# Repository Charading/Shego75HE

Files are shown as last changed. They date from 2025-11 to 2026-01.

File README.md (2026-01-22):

<h1 style="margin-bottom:0;">Shego75HE</h1>
<h4 style="margin-top:0;">Probably the first magnetic keyboard running QMK firmware.</h4>

> 📖 **[Read the latest update →](UPDATE.md)**

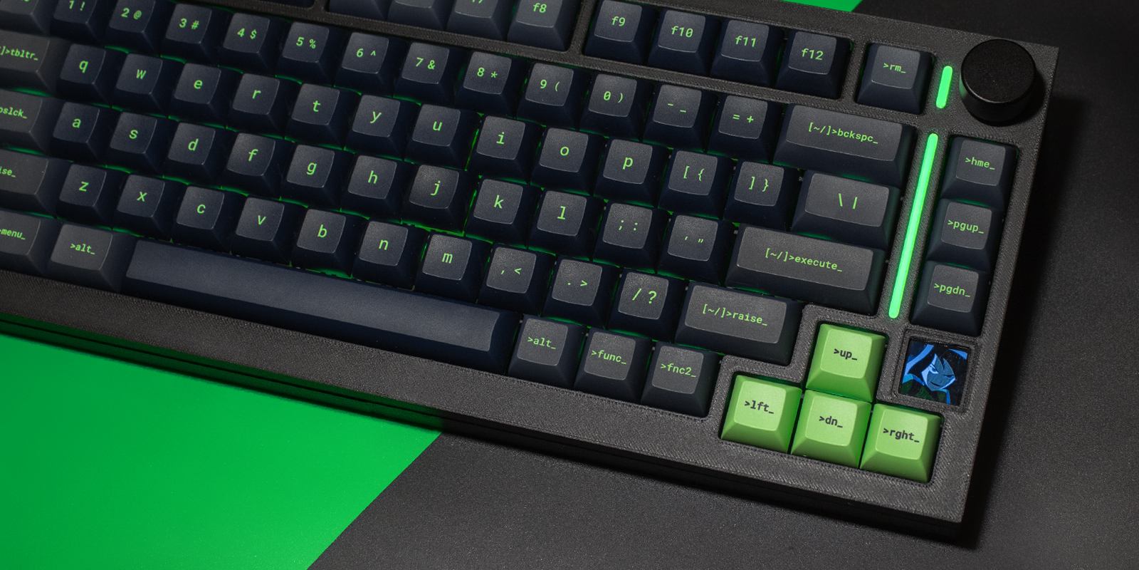
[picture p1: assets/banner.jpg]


### Introduction&nbsp; 

I couldn't find a keyboard with the all of features that I wanted at all, so I resorted to building my own one. After testing a lot of keyboards, I wanted one that had a mix of all different features from multiple keyboards. This project has taken many, many, many months, starting from experimentaion and various mini protypes like the [Shego16](https://github.com/Charading/SHEGO16-QMK-Hall-Effect-Macropad).

### Design and Inspiration 💡
I think the exploded 75% layout is one of the best layouts but sadly it's not as aftermarket as the generic 60% layout so my only options for trying to find a board were scarce. For aesthetics, I went with Shego because my mind was blank and tbh, I just wanted a cool silkscreen too lol. 

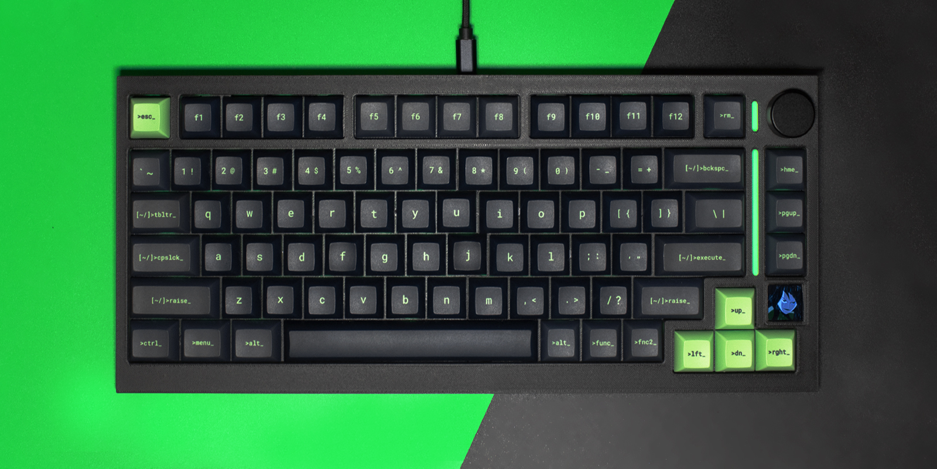
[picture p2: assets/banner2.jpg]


I do love the **Ajazz AK820 Pro** and it's clean design, along with the added screen. I do wish it could run QMK/VIA firmware though. Another board I tested was the **GamaKay TK75HEV2** I wanted my board to be quite similar to both, but have everything I've ever wanted. 

Features I wanted

* Hall Sensors
* SOCD
* Rapid Trigger
* Volume Knob
* Ambient Lighting
* Screen
* North-facing RGB
* 75% Layout
* QMK/VIA Compatible
* Works with SignalRGB (per-key not that stupid one-zone nonsense)

#### Firmware 👨‍💻
I originally tried raw C, then riskable put me on Rust, but after creating a successful prototype, I had a revelation. the idea I had is to use normal QMK firmware since I was a little bit familiar with it, then heavily modify my clone of it to work with hall sensors. 

*I am still designing a drop in [module](https://github.com/Charading/qmk-hallscan) that can make anyone be able to use the logic for QMK. Project is ongoing*

Oh yeah, to make my life easier, and save my poor fingers from typing `qmk compile -kb shego75_v1 -km default` a million times, I developed a VS Code extension, a small one-click button that compiles QMK firmware. Find it [here](https://github.com/Charading/QMK-Compile-button-for-VS-Code).

The screen/ESP32 portion is written in C++ inside Arduino IDE.

###### The Sensors 🧲
After doing extensive research and testing with breadboards and Raspberry Pi Pico boards, I settled on using the RP2040 for my base MCU. I was going to use HC4067s, but I didn't really understand multiplexer cascading so after looking for a bit, I stumbled upon the ADG732 so I now use three of these, which means I do not need to use a MCP3208 external ADC *(my god, I recently was trying to get this to work using my sensor-to-matrix logic in QMK but couldn't for the life of me)* and I could use only 3 of the 4 analog pins.

###### How it works 🔎
Essentially, the bread and butter is that the firmware scans across three ADG732 muxes - *which I got really cheap for ~£2 on AliExpress*, and this 'injects' keypresses directly into the key matrix so that it works with VIA and key remapping also. 

On startup, the sensors calibrate with a baseline threshold and when the sensors deviate by a certain % amount, the keypress is registered. I even added hysteresis so I have some kind of rapid trigger.

Debugging keycodes enable printing to QMK Toolbox's HID Console

* `DEBUG_ADC`  - Prints ADC values
* `DEBUG_KEYS` - Prints on keypress events
* `DEBUG_RAW`  - Prints the raw VIA keycode on keypresses, i.e *0x67*

I believe it still prints keys and raw to the screen on a little popup text box too.

###### The Lighting 💡
For the lighting, I ket it simple, and just use SignalRGB,  but in the future I want to maybe add OpenRGB support as well and my own custom lighting section in my Electron app. I have made the [plugin](SignalRGB/SHEGO75.js).

It has full per-key north-facing rgb, a 10-led ambient strip and a 3-led status bar, there is also a 3-pin jst 1.25mm connector footprint in the corner for optional extending *(maybe for a future case, underglow?)*.

The SRGB plugin uses `LedGroups()` to create segments so it has three draggable windows to mess around with.

```javascript
export function LedGroups() {
	return [
		{ name: "Keys",    leds: vKeys },
		{ name: "Ambient", leds: vAmbientKeys },
		{ name: "Status", leds: vStatusKeys }
	];
}
```
 It is designed as one continuous strip though, on `GP17`, but there is a transistor pair on `GP23` which is controlled by the `LED_TOG` custom keycode and cuts power to the LEDs.

 When focused on the screen/layer 3 toggled, the status bar will turn blue.

 When debugging is enabled via `DEBUG_ADC`,`DEBUG_KEYS` or `DEBUG_RAW`, the ambient strip should marque orange.

###### The Screen 📺

Sadly, I couldn't figure out how to get SPI working to talk to the screen for GIF upload and playback via HID, so I approached it a different way.

I built an isolated ESP32 system using [my fork](/esp32_display) of a GIF player repo. I basically redid it to have a little menu and file system, and work a different way to the original. Instead of it automatically copying the GIF to flash and autoplaying, I can browse the SD card, choose which GIF to display, it copies it to SPIFFS, then plays. This way it persists even after power off. 

The screen is [this](https://www.aliexpress.com/item/1005004490846551.html) ST7735/GC9107 8-pin, 0.85", 128x128 IPS display.

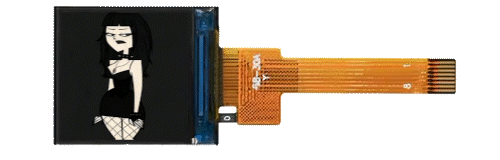
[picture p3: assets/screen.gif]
display


To get the QMK firmware to communicate with the ESP32 system, I created custom VIA keycodes which send UART text strings and text commands such as `MENU_OPEN`, `MENU_UP`,`MENU_DOWN` and `MENU_SELECT` allow me to navigate and choose an animation.

4-stage PWM controlled backlight with `TFT_BRIGHTNESS_UP` and `TFT_BRIGHTNESS_DOWN`, via a [AO3401](https://www.aosmd.com/res/data_sheets/AO3401.pdf) transistor. 

I also made a a timer page, settings page, and hardcoded focus toggle which layer 3 + encoder press turns the rotation into menu navigation, and press is the select. 

In a small update, I added a I2C connection between the RP2040 and the ESP32 which I was thinking I could use for GIF passthrough and sending in the future but this is not implemented yet.

##### Firmware Issues
I want a way to use QMK's `raw_hid_receive` and `raw_hid_send` so I can have my own custom software that can change per-key actuation, I could implement DKS, upload GIFs to the SD card/directly to the screen and even manage the card's storage. 

I managed to create a small Electron app that can communicate with the board, but it's still in development.

I realised that SignalRGB consumes packets so I had to edit the `signalrgb.c` and `signalrgb.h` to not drop packets it doesn't recognise but I am still stuck because I can't get my app to even toggle GPIO23 which toggles power to the lighting. *I did manage to do it once but I reverted back because I have up, but this was before I changed the SRGB module. Now even with SRGB disabled, I still can't get my keyboard to toggle and I don't know what the issue is.*

I just want to be able to talk to my board over HID and then I can make it similar to all those Chinese OEM clone web apps and software, Wootings web app etc.

If anyone more knowledgable can assist or point me in the right direction that would be amazing!

####  Case ⚫

case

At the moment I am using a prototype case that I printed out of ELEGOO PLA-CF. I could technically get this machined by JLCCNC but I do not wish to increase spending at this time. I would rather wait and see if I can finalise my case beforehand to minimise revisions and metallic waste. 

I do wish I could find the smaller form factor ball catches that the **Lucky65** and many other newer boards use but I can't find somewhere that can machine them or find them aftermarket. So at the moment, it is a two piece design, designed similarily to the **CIDOO C75** and **TK75HEV2** but with the shaping somewhat resembling the **Tofu65** because I like the sharp edges. I really hate the designs that have such baby rounded edges like the **AK820 Pro MAX**.

It uses a daughterboard I designed, but maybe a future design I would want to to use pogo pin connectors like the **Lucky65 V3** but I would have to do some testing to see that the magnets do not interfer with normal keyboard function.

#### PCB 🟢
pcb

Just used KiCad, I kept having issues using the standalone ESP32-PICO-D4 and flashing it *(maybe it's because I was lazy and didn't implement a USB-UART chip)* so I did some looking and found the [TinyPICO Nano](https://github.com/tinypico). To help test with firmware and stuff, just to be safe and not rely on my firmware working with it just because it worked on the ESP32-WROOM-32 dev module, I designed [this adapter](https://github.com/Charading/flexypin_adapters_hw/tree/main/TinyPICO-NANO_flexypin) so interfacing and testing would be easier. The RP2040's `GP0` and `GP1` are broken out for UART0 debug.

### Future Updates/Roadmap 🚗
- I haven't really been focused on it much with this board, but I will be looking to implent tri-mode or at least 2.4GHz wireless with a dongle. For a coming soon, future project I want to design a drop in replacement pcb for the **Lucky65 V2** or **Lucky65 V3** running my custom magnetic QMK firmware because the cases are gorgeous and such a steal!

- Software/web app (most likely Electron powered)
- Implement GIF upload over USB 
- Motion design/3D design for promotional material, a small website as I would like to start a small store that sells keyboard stuff and keycaps.
- Full aluminium case needs to be machined 
- Maybe start a Kickstarter for a future keyboard project
- TMR keyboard maybe? 👀

>*I should say I came into this project with no prior knowledge of PCB design (proficient now), very miniscule coding knowledge (still a newbie though), and a small amount of CAD skill (which I am quite proficient at now I believe). My soldering skills are now extremely high as well* :).

### Special Thanks 🖤
- [**riskable**](https://github.com/riskable) for his online resources and availabilty to help me at various points in this project!

- **@hardbr** *(discord)* for helping me understand SignalRGB implentation

- [**Phils Lab**](https://github.com/pms67) for online resources *(Youtube)*

- **JLCPCB**

- **GitHub Copilot**, **ChatGPT**, **Claude**, **Gemini Pro** (actual life savers lmao)

## 24/12/2025 - Merry Christmas! 
## Huge Update:
I’ve got the software working and a completely new firmware stack built from the ground up. The app is **Electron-based** and (honestly) was mostly vibe-coded while I iterated on UX and device behavior. The firmware is also brand new—written specifically for this project and its multi‑MCU architecture.

A big part of this update is that we **moved fully away from QMK**. Instead of adapting QMK to fit the hardware and features, we started from scratch with a firmware designed around our exact data paths and performance goals: **USB HID on the RP2040**, a clean **UART link** to the ESP32 for UI/display responsibilities, and **SPI** for high-throughput TFT updates. Dropping QMK gave us tighter control over timing, memory, and feature integration, and removed the friction of forcing a general-purpose keyboard firmware into a system that’s doing more than “just key scanning.”

The project is currently in a private repo. If you want to follow along or chat about it, my Discord is **hyupdo**.

### App Preview

<h5 align="center">Keys</h5>

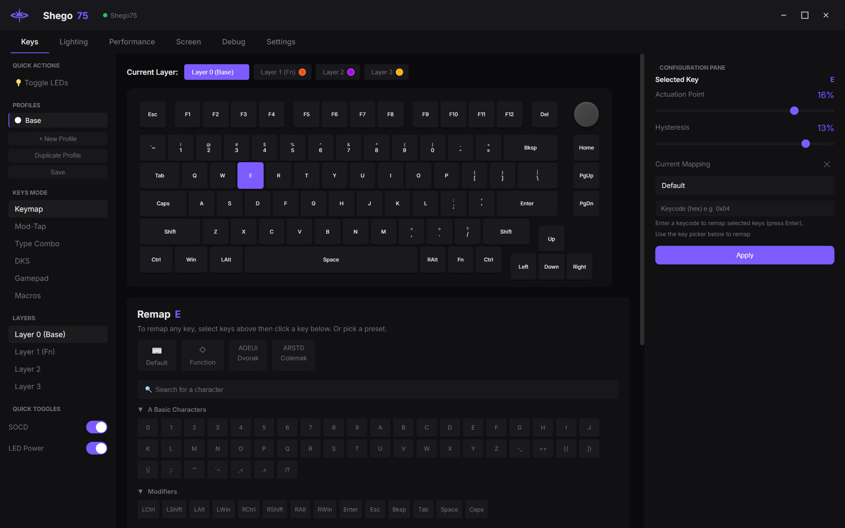
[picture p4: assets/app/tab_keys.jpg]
Keys Tab


<h5 align="center">Lighting</h5>

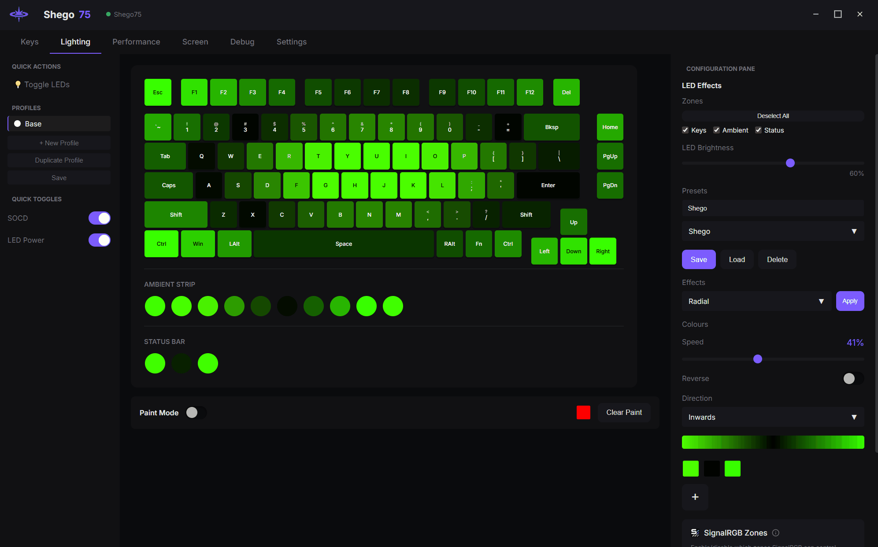
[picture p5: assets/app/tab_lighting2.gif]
Lighting Tab


<h5 align="center">Performance</h5>

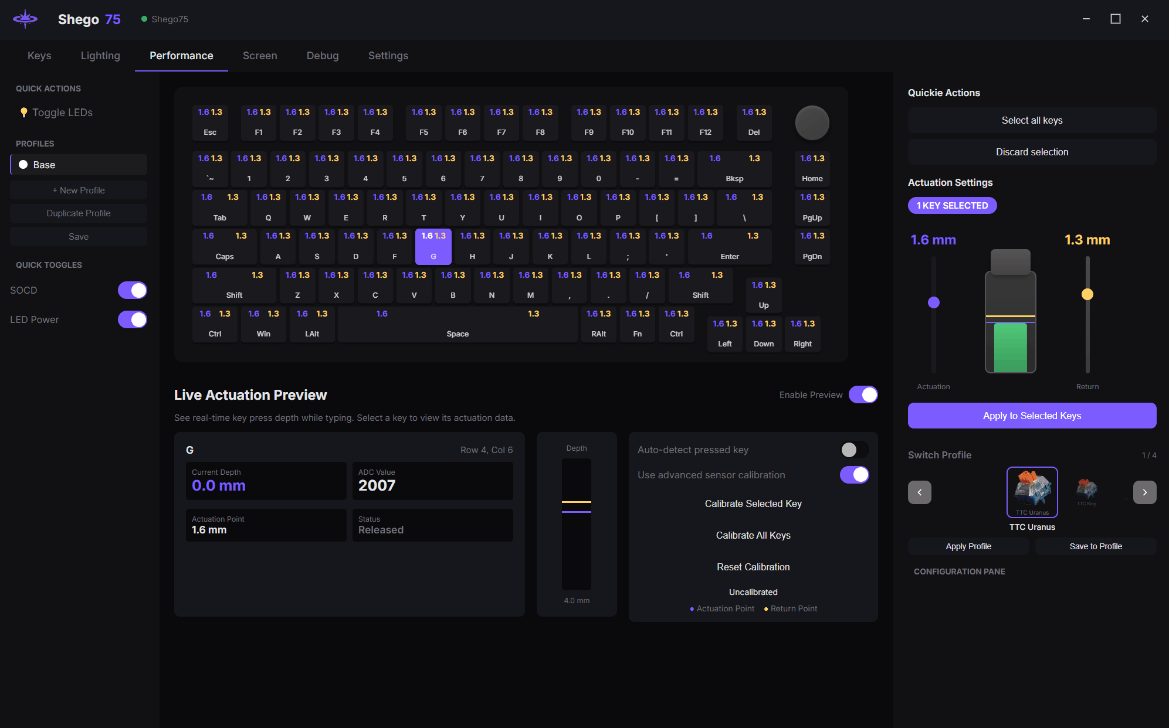
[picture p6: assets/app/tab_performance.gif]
Performance Tab


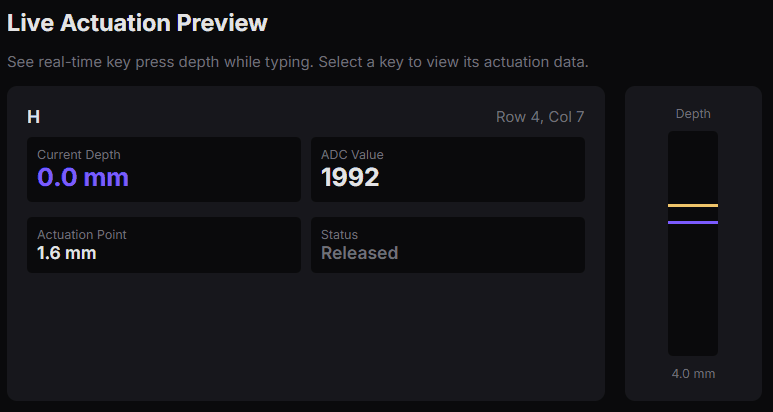
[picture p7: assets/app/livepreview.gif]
live preview


<h5 align="center" style="margin-bottom: 0;">Screen</h5>

<div align="center" style="font-style: italic; line-height: 1;">
  <small>This feature is only available on the Shego75</small>
</div>

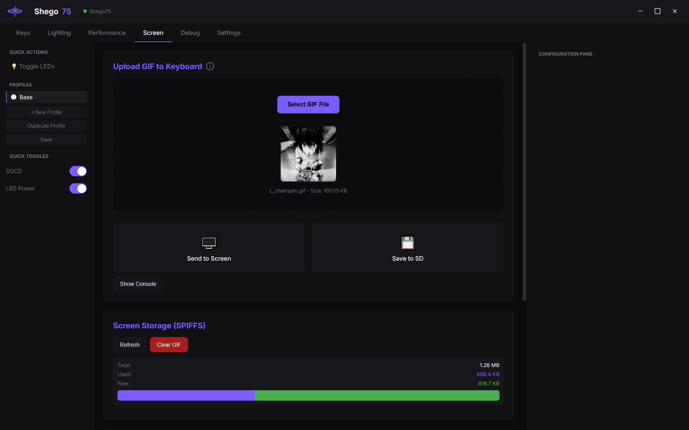
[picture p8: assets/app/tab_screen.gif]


<div align="center" style="line-height: 2;">
  <small>Storage system using the SD ('Send to SD' yet to be implemented)</small>
</div>

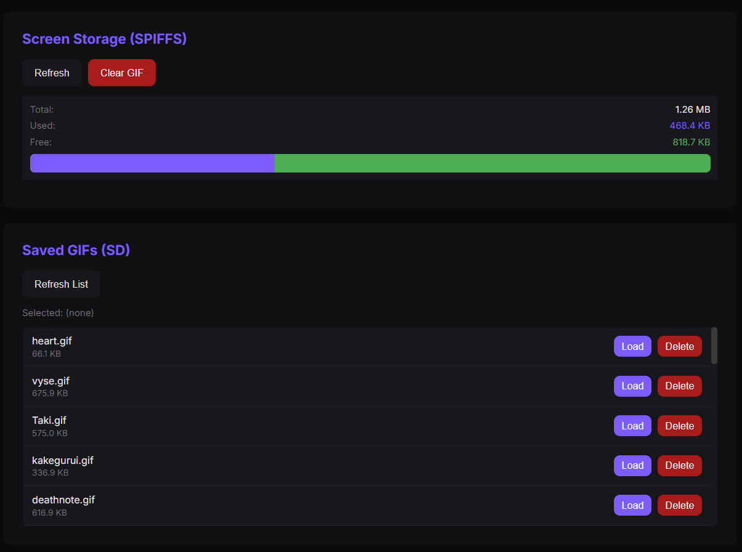
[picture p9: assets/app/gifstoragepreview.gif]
live preview


### How to use:

#### Keys

Configure per-key actuation points, dead zones, and key assignments. The live visualization shows real-time magnetic sensor readings and key states. Customize individual key behavior with adjustable sensitivity ranges and enable anti-ghosting features. Export and import key profiles for quick configuration switching.

#### Lighting

In the **Lighting** tab, effects are driven using **SignalRGB**, which treats the keyboard like an addressable LED device and streams color data in real time. Once enabled, SignalRGB can take control of animations (audio-reactive, game integrations, ambient effects) and push them directly to the board so lighting stays perfectly in sync with the rest of your setup. You can still fine-tune how the device presents itself to SignalRGB—especially how LEDs are grouped and mapped—so the software knows what “keys” or regions it’s actually driving.

To change **zones**, use the zone controls to assign LEDs/keys into separate regions (for example: left half, right half, underglow, indicator cluster, or per-row groups). Each zone can be adjusted independently so you can apply different colors/effects per region, or scale brightness and effect intensity where you want it. After updating zone assignments, apply/save the configuration so the device reports the new layout and SignalRGB (or the app’s built-in effects) will target the updated zones correctly.

#### Performance

The **Performance** tab is a live “health dashboard” for the firmware and transport links, meant to answer one question quickly: *is the device keeping up in real time?* It aggregates timing, throughput, and workload counters so you can confirm that input scanning, lighting updates, and display/UI work are all completing within budget—especially when features are enabled simultaneously.

At a high level, the tab focuses on three areas:

1) **Frame / Loop Timing**
- Shows how long the main firmware loop (or “frame”) takes to run and how consistent it is over time.
- Look for **average**, **min/max**, and **spike** behavior. A stable system has tight variance; frequent spikes suggest something occasionally blocks (heavy rendering, long SPI transfers, or bursts of host traffic).
- If you see a “budget” or target interval, the goal is to keep the loop time comfortably below that target so there’s slack for bursts.

2) **Input Responsiveness**
- Tracks the cadence and workload of key scanning and event processing.
- Useful indicators include scan rate, event queue depth, and any dropped/late events.
- If responsiveness metrics degrade while other features are active, it’s a sign you should reduce background load (very high LED update rates, overly frequent display refresh, or excessive logging/telemetry).

3) **Transport + Subsystem Throughput (Host ⇄ RP2040 ⇄ ESP32 ⇄ TFT)**
- **USB/HID**: lets you see how often the host is sending commands and how quickly the device is responding. Excessive command rates can create overhead and jitter.
- **UART (RP2040 ⇄ ESP32)**: shows whether messages are flowing smoothly between MCUs. Watch for rising queue/backlog counters or retry/error counts—those often correlate with delayed UI updates.
- **SPI (ESP32 ⇄ TFT)**: large, frequent screen updates can dominate time. If you see display-related counters tied to spikes, consider lowering refresh frequency or reducing what’s being redrawn per update.

How to use it in practice:
- Start with everything “idle” and note the baseline loop time and stability.
- Enable one feature at a time (lighting effects, animations, screen updates, host polling) and watch what changes.
- If a metric provides “worst” or “spike” values, treat those as the most important—single long stalls are often more noticeable than a slightly higher average.
- Use the tab as a verification step after configuration changes: if you adjust lighting zones, increase effect complexity, or change display behavior, confirm the loop remains stable and queues don’t grow over time.

If the Performance tab includes error counters (CRC, framing, dropped packets, overflow), any value that steadily increases during normal use usually indicates a configuration or bandwidth issue worth addressing before it impacts responsiveness.

#### Screen

The screen is driven as a simple “remote display” in a two‑MCU chain: the **RP2040** acts as the USB/HID-facing coordinator, and the **ESP32** acts as the display/UI controller. The RP2040 collects system state (and any stats it owns), then sends compact status packets over **UART** to the ESP32. The ESP32 turns those packets into UI state (text, graphs, icons, warnings) and renders the result to the TFT over **SPI**.

**Communication path**
- **Host → RP2040 (USB HID):** the desktop app can request status, enable/disable telemetry, or change what the UI should show (page selection, refresh rate, debug toggles).
- **RP2040 → ESP32 (UART):** the RP2040 forwards the “what to display” information as structured messages (think: page id + key/value metrics + flags). UART is used because it’s reliable, low-latency, and keeps the display work off the RP2040’s timing-critical loop.
- **ESP32 → TFT (SPI):** the ESP32 updates the actual pixels. SPI is a high-throughput link commonly used by small TFTs, and it lets the ESP32 push either partial updates (only what changed) or full frames depending on the UI.

**How it shows “memory and stuff”**
What you see on the screen is ultimately just the ESP32 drawing primitives (text, lines, rectangles, images) based on numbers it receives. Those numbers can come from a few places:
- **ESP32-local stats:** free heap/PSRAM, task runtime, Wi‑Fi state, frame time for rendering, SPI throughput, queue depths. These are measured directly on the ESP32 and then displayed immediately.
- **RP2040 stats:** loop timing, scan workload, HID traffic counters, UART throughput/error counters. The RP2040 measures these and periodically ships them to the ESP32 so they appear in the same UI.
- **Derived/aggregated values:** rates and percentages (e.g., “updates per second”, “max spike”, “avg frame time”) computed from counters over a time window to make the data readable at a glance.

**Display model (why it can update smoothly)**
- The ESP32 keeps a small UI state model (current page, last-known metric values, thresholds, formatting).
- On each update tick, it compares new values to the previous ones and redraws only the regions that changed (e.g., a number field or a graph strip). This avoids pushing a full-screen refresh over SPI when it’s not needed.
- Graphs are typically rendered as rolling plots: the ESP32 stores a short history buffer (last N samples) and draws it as a line or bar chart, which makes “performance” data intuitive without flooding the link.

**Features the screen typically supports**
- **Pages / tabs:** status overview, lighting status, performance graphs, debug info, connectivity.
- **Live counters:** loop/frame time, HID packet rate, UART rate, dropped/overflow counts.
- **Memory readouts:** free heap/PSRAM (ESP32), and any reported RP2040 memory stats if exposed.
- **Warnings:** threshold-based indicators (e.g., queue growing, repeated UART errors, refresh budget exceeded).

In short: the RP2040 and ESP32 exchange lightweight telemetry over UART, and the ESP32 turns that telemetry into a responsive on-screen dashboard by drawing UI elements over SPI to the TFT.

### App Flow

#### The way it works:

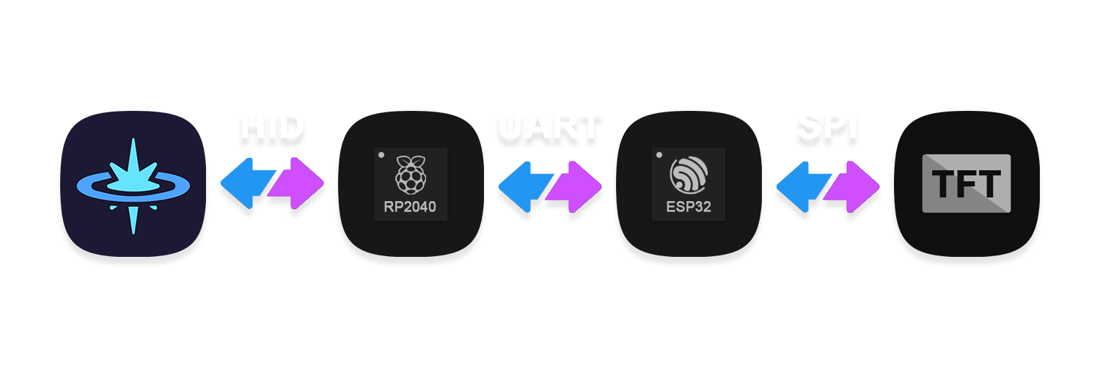
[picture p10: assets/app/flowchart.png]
order of operations


##### Software
The desktop-side software is the user interface and configuration layer. It connects to the device over **USB HID**, provides a way to change settings (layouts, lighting, display options, etc.), and then sends those changes as compact commands to the firmware. Because it uses HID, it can talk to the device without needing a custom driver on most systems, and it can also be used for debugging/telemetry (reading back status, firmware info, and error codes).

##### RP2040
The RP2040 is the **USB-facing controller** and the central coordinator. It presents itself to the computer as a **HID device**, parses incoming configuration commands from the software, and applies settings that belong on the main MCU (key scanning, state management, timing, etc.). It also acts as a bridge to the secondary MCU over **UART**, forwarding display/network-related commands and receiving status updates so the host can see what the rest of the system is doing.

##### ESP32-PICO-D4
The ESP32-PICO-D4 is responsible for the **high-level peripheral side**, primarily driving the display. It receives messages from the RP2040 over **UART**, interprets them as UI/state updates, and renders to the TFT over **SPI**. It can also be used for features that fit better on the ESP32 (background tasks, connectivity, asset handling), while keeping the RP2040 focused on deterministic USB + input timing.

### Test for yourself
I have put the app up online if you want to browse through, WebHID isn't implemented properly since I primarily focused on USB HID but do check out the themes in the Settings tab!

Link: [nova-8tt.pages.dev](https://nova-8tt.pages.dev)

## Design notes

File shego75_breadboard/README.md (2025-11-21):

# Shego75HE
75% Hall effect keyboard with many features.

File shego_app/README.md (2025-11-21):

# shego_app

Minimal Electron app with a button that sends the custom Raw HID command `0x30` (LED_TOGGLE) to the Shego75 firmware. Node cannot send Raw HID packets reliably, so every command is executed by `python scripts/toggle_led.py`, which uses hidapi under the hood. Firmware maps this command to `toggle_led()`, same effect as pressing the hardware `LED_TOG` key.

How to run

1. Install dependencies (Windows PowerShell):

```powershell
cd X:\Shego75HE\shego_app
npm install
npm start
```

2. Install Python 3 + `hidapi` (`pip install hidapi`) and ensure `python` is available in PATH. The Electron app shells out to the Python helper for every packet.

Manual CLI usage (bypasses Electron UI):

```powershell
cd X:\Shego75HE\shego_app
python scripts\toggle_led.py --vid DEAD --pid C0DE --cmd 30
```

Notes
- Sends report with command byte `0x30` (defined in firmware as `HID_REPORT_ID_LED_TOGGLE`).
- SignalRGB module now forwards unknown/non-module packets, so this command works even when SignalRGB is active.
- If you change the command ID in firmware, update `renderer.js` (`CMD_LED_TOGGLE`) and/or pass a different `--cmd` to `scripts/toggle_led.py`.

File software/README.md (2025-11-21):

# Keyboard Configurator - Electron App

A desktop application for configuring your custom keyboard, including GIF uploads via HID and per-key actuation threshold adjustment.

## Features

### 1. GIF Upload Tab
- Select GIF files from your computer
- Preview selected GIF
- Send GIF to two destinations via HID:
  - **Screen**: Display directly on ESP32 screen
  - **SD Card**: Save to SD card for later use

### 2. Actuation Settings Tab
- Interactive 75% keyboard layout
- Click any key to adjust its actuation threshold (0.1mm - 4.0mm)
- Visual feedback for modified keys
- Real-time updates sent to keyboard

## Installation

1. Install dependencies:
```bash
npm install
```

2. Install HID library (required for keyboard communication):
```bash
npm install node-hid
```

## Setup

### Find Your Keyboard's VID/PID

Run the helper script to find your keyboard:
```bash
node find-keyboard.js
```

This will list all HID devices. Find your keyboard and note the Vendor ID and Product ID.

### Configure Your Keyboard

Edit `config.js` and update with your keyboard's information:
```javascript
KEYBOARD_VID: 0x1234, // Your keyboard's Vendor ID
KEYBOARD_PID: 0x5678, // Your keyboard's Product ID
```

## Running the App

Development mode (with DevTools and auto-reload):
```bash
npm run dev
```

Production mode:
```bash
npm start
```

## HID Communication Protocol

The app sends GIF data over HID to your keyboard, which forwards it to the ESP32. The protocol includes:

- **Destination Flag**: Indicates whether to send to screen (0x01) or SD card (0x02)
- **Chunked Transfer**: Large GIFs are split into 64-byte packets
- **Commands**: Start (0x01), Data (0x02), End (0x03)

See `HID_PROTOCOL.md` for detailed protocol documentation.

## Project Structure

```
software/
├── main.js              # Electron main process with HID communication
├── preload.js           # Secure bridge between main and renderer
├── index.html           # Main UI structure
├── renderer.js          # UI logic and interactions
├── styles.css           # Styling
├── config.js            # HID configuration (VID/PID, timing)
├── find-keyboard.js     # Helper to find keyboard VID/PID
├── HID_PROTOCOL.md      # Protocol documentation
├── package.json         # Dependencies and scripts
└── README.md            # This file
```

## Customization

### Keyboard Layout
Modify the `keyLayout` array in `renderer.js` to match your keyboard's physical layout.

### Actuation Range
Adjust the slider range in `index.html`:
```html
<input type="range" id="threshold-slider" min="0.1" max="4.0" step="0.1">
```

### Communication Protocol
Implement your keyboard's specific protocol in the IPC handlers in `main.js`:
- `send-gif`: For GIF data transfer
- `update-actuation`: For actuation threshold updates

## Building for Distribution

To create distributable packages, you can add electron-builder:

```bash
npm install --save-dev electron-builder
```

Then add build scripts to `package.json`.

## License

MIT

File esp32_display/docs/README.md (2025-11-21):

# ESP32 GIF Player (ST7735)

Small ESP32 sketch to browse GIFs on an SD card, copy a selected GIF into SPIFFS as `/current.gif`, and play it on a ST7735 TFT display.

## Features
- Browse GIFs stored on SD card (up to 20 entries).
- Menu UI on the TFT (navigate with buttons for now. *QMK serial commands soon to be implemented*).
- Copy selected GIF from SD card to SPIFFS atomically (writes a temp file then renames).
- Visual progress bar while copying.
- `Clear GIF` menu option removes `/current.gif` from SPIFFS.
- Plays GIFs from SPIFFS only (prevents playing directly from SD) *I had so many issues trying to get that to work.*

## Pin assignments
These are the defaults used in `esp32_tft_sd_menu.ino`:

| Signal / Purpose | Sketch define | Default GPIO |
|---|:---|---:|
| SD Card CS (VSPI) | `SD_CS_PIN` | 5 |
| SD MOSI (VSPI) | `SD_MOSI` | 22 |
| SD MISO (VSPI) | `SD_MISO` | 19 |
| SD SCK (VSPI) | `SD_SCK` | 21 |
| Button - Up / Previous | `BUTTON_UP` | 14 |
| Button - Down / Next | `BUTTON_DOWN` | 13 |
| Button - Select | `BUTTON_SELECT` | 15 |
| TFT reset (optional) | (toggled via GPIO) | 4 |
| QMK UART RX (ESP32 receives) | `QMK_RX_PIN` | 16 |
| QMK UART TX (ESP32 sends) | `QMK_TX_PIN` | 17 |

> Note: TFT pin mappings (SPI, DC, CS, MOSI/MISO/SCLK) are configured via the `TFT_eSPI` library `User_Setup.h`. The sketch only toggles GPIO 4 as an optional display reset line if wired.

## Behavior / Usage
1. On boot the frimware initializes SD and SPIFFS and scans the SD root for `.gif` files.
2. If a valid `/current.gif` exists in SPIFFS the frimware will attempt to play it. If not, the menu is shown for gif selection.
3. In the menu:
   - Use `BUTTON_UP` and `BUTTON_DOWN` to change selection.
   - Short press `BUTTON_SELECT` to copy the chosen GIF into SPIFFS as `/current.gif` and start playback.
   - The bottom menu item is `Clear GIF`, which deletes `/current.gif` from SPIFFS.
4. Copying is atomic: the file is written to a temporary file then renamed to `/current.gif` on success. A progress bar is shown on the TFT while copying.

## QMK Serial Commands
You can control the menu remotely over the second hardware serial port (pins 16/17):*

- `MENU_OPEN`  – open menu
- `MENU_CLOSE` – close menu
- `MENU_UP`    – move selection up
- `MENU_DOWN`  – move selection down
- `MENU_SELECT`– select current item (copy / clear)
- `STATUS`     – request status string

The firmware replies with simple status messages (e.g. `MENU_OPENED`, `GIF_SELECTED:...`).

**Still yet to be implemented properly.*

## Upload / Troubleshooting
- Use the Arduino IDE or PlatformIO with the ESP32 board package installed.
- If upload fails with "Wrong boot mode detected (0x13)", put the board into download mode by holding BOOT (IO0) while plugging USB, then upload.
- Serial output (115200) prints helpful debug messages during SD/SPIFFS init, menu actions and copying.
- If copying freezes:
  - Verify SD card wiring and power.
  - Make sure the TFT and SD do not share conflicting pins in your `TFT_eSPI` configuration.
  - Check that SPIFFS has enough free space for the selected GIF.
  - Clear GIF to free up SPIFFS then try again with another smaller gif.

## Files
- `esp32_tft_sd_menu.ino` — main sketch (menu, copy logic, GIF playback callbacks).

## Notes
- The TFT driver uses `TFT_eSPI` and its pin mapping is controlled by the `User_Setup.h` / `TFT_eSPI` config. Adjust that file if your display uses different pins.
- SPI transactions and a mutex are used to serialize SD/TFT/SPIFFS accesses. Avoid changing SPI pins at runtime.

If you want any additional documentation (example wiring diagram, change log, or a shorter quickstart), tell me what to include and I will add it.

*i am still very new to coding and all this and github copilot has been a huge saviour for me, so please do forgive my spaghetti code 🍝.*

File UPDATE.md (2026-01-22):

# How This Keyboard Ended Up Here

I’ve been working on this keyboard for months now, and honestly, it’s gone through *so many* changes that it reached a point where I needed to actually stop and write down why things changed the way they did.

A lot of this came down to the screen, the firmware, and just how disconnected everything felt before.

Also, as it's grown I've wanted to rebrand/rename but am still unsure of a name so it's just Nocturne75 for now.

---

## The Old Setup (And Why It Started to Bug Me)

Originally, Shego was split across two chips.

The **RP2040** did all the keyboard stuff — scanning, Hall sensors, HID — and the **ESP32** was basically just there to run the screen. The ESP handled a GIF player that worked off an SD card, and the two chips talked to each other over UART.

On paper, this was fine.

In reality, it kind of sucked.

The screen never felt like part of the keyboard. It always felt like this extra thing bolted on the side that you talked to indirectly. And that disconnect kept getting more obvious the more features I tried to add.

---

## The SD Card Problem

The SD card setup worked, but it was fragile.

If you wanted to change a GIF:
- Open the keyboard  
- Pull the SD card  
- Copy files  
- Put it back  
- Reassemble everything  

That’s fine once. It’s annoying every time after that.

The ESP would copy the GIF from the SD card into flash so it would persist, which was clever, but it still felt like a workaround rather than a real solution.

What I *wanted* was what other keyboards with screens do:
- Send a GIF directly over USB
- Have it show up immediately
- No physical access required

I just couldn’t get there with the split RP2040 + ESP32 setup.

---

## ESP32 Pico-D4: Looked Perfect, Wasn’t

At some point I found the **ESP32 Pico-D4**, and I really thought this was it.

It’s small, cheap, has integrated flash, no external crystal — perfect for a keyboard PCB.

Except… I could not get it to work.

I couldn’t flash it reliably. I couldn’t even tell if it was alive half the time. In hindsight, a lot of that was probably soldering skill, because this was earlier on and I’ve improved a *lot* since then. But at the time, boards were just getting wasted.

That was kind of the moment where I stopped and thought:

> Why am I fighting this so hard?

---

## Rethinking the Entire Direction

Instead of trying to fix the ESP32 approach again and again, I started questioning the whole architecture.

Why am I running two processors?
Why is the screen separate at all?
Why does this feel more complicated the more I improve it?

So I started looking around for alternatives.

---

## Finding the RP2350B

That’s when I came across the **RP2350 series**, and specifically the **RP2350B**.

This thing basically solved *everything* in one go.

- Eight beautiful ADC channels  
- Enough power to handle a screen properly  
- No need for rare, expensive parts like ADG732s even though I did get them very cheap (around £2 each) from AliExpress
- One processor for everything  

The biggest thing though wasn’t specs — it was the realization that **the screen didn’t need to be separate at all**.

The keyboard *could* just be one system.

---

## Porting Everything (And Why It Was Worth It)

Over the last month or so, I’ve been porting the Shego firmware to the RP2350B and rebuilding the screen logic properly.

I designed a Pico-style RP2350B breakout for testing and ran everything on a breadboard and at the time of writing, I still am. I didn’t even touch Hall scanning at first because that part was already solid — the real work was making the screen feel native.

At that stage, the screen wasn’t unfinished — it was actually mostly there. I had already built a working UI, and I added a Spotify screen, which could show album art, track information, and playback progress. Functionally, it did what I wanted, and I could have stopped there and called it done.

What kept bothering me, though, was how cheap the UI felt, and a big part of that came down to fonts. Everything was built around basic bitmap pixel fonts, and no matter how much I tweaked spacing or layout, it always looked primitive and unrefined. 

The old system worked, but it always felt cheap and off, like something that didn’t belong on a serious keyboard, and that disconnect kept bothering me the longer I worked on the project. This was the point where I started looking into alternatives, purely because I wanted better typography and more control over how text was rendered.

That search is what led me to LVGL. Initially, I wasn’t planning on rewriting the whole UI — I just wanted to see if I could get nicer fonts and cleaner text rendering. The first thing I brought over wasn’t the main screen or the Spotify page, but the settings and lighting menu. As soon as that was running in LVGL, with the new fonts, and animations, the difference was obvious. The UI immediately felt more structured, more consistent, and more intentional. At that point, it became very hard to justify keeping the rest of the interface on the old system, and that’s when I realised the entire screen stack needed to move over.

Once I brought LVGL in, everything clicked.

The UI finally felt like it belonged to the keyboard.

---

## What the Screen Can Do Now
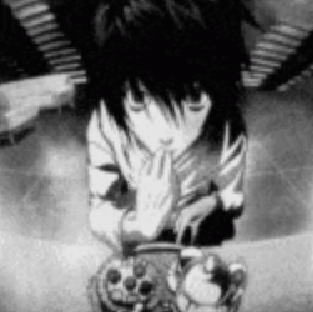
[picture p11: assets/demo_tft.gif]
Demo TFT

The screen isn’t a gimmick anymore.

It’s a proper interface.

There’s a page system:
- One page is just your main GIF
- Another page shows Spotify info — album art, track name, playtime
- Another page shows live Hall sensor data for individual keys
- Another page allows you to change the lighting

You can literally press a key and watch its actuation live. Right now it’s ADC values, but once the PCB is finalized and calibration is locked in, that’ll turn into proper distance values.

It feels *connected* in a way the old setup never did.

---

## The New GIF System (No More SD Card Pain)

This is probably one of the biggest quality-of-life improvements.

There’s now a **slot-based GIF system in flash**.

- 16 MB external flash
- Slot 0 is the active GIF
- 10 other slots for saved GIFs for instantanous switching

You upload GIFs over USB HID now. No SD card required!

If you *do* want to use the SD card, it’s still there — but now you can send gifs to it, browse it from the keyboard, copy files into flash, and manage storage without opening the case.

Changing a GIF is instant.

That alone fixes one of my biggest long-term annoyances with Shego.

---

## Input While Prototyping

Right now I’m using a little 5-button joystick module on the breadboard because it’s just faster for development.

In the real keyboard:
- Navigation will be done with keycodes and the encoder
- No extra hardware needed

The important part is that the logic is already there.

---

## Stability Testing (And Breaking It on Purpose)

I’ve spent a lot of time trying to break this.

Streaming live ADC data while LVGL is rendering.
Hammering USB while the screen updates.
Doing things I probably shouldn’t be doing.

It’s held up really well.

I did hit a weird bug where the screen was selecting the wrong key while the software side was correct — turned out to be an index offset issue, which is now fixed.

Overall, it feels solid.

---

## Flashing and Development Now

Moving to the RP2350B made development *so* much easier.

Flashing over USB or SWD.
SWD is way faster now that the firmware is bigger.
Debugging is cleaner.

At this point, once the PCB is done, it’s basically:
- Firmware updates
- Bug fixes
- Feature additions

No more architectural rework.

---

## Lucky65 v2 & v3 Side Projects

Alongside all this, I’ve also designed **drop-in replacement PCBs** for the **Lucky65 V2 and V3**.

They’re direct replacements — no case mods — and they turn those boards into **Hall Effect keyboards** running the *same* firmware as Shego, just without the screen.

Same scanning logic.
Same actuation model.
Same software quality.

The stock Lucky65 firmware ecosystem doesn't really exist. These boards basically free the hardware from that whole situation and give it a proper firmware stack. I wanted this since I do love the cases and the sounds they produce. These two boards also work wirelessly too, I designed it to work with a 2.4GHz radio module, and designed my own dongle (sadly not that tiny size, as the identical size one wouldn't work, but the firmware works) But that's another story.

---

## About the Repo

All of this has been developed in a **private repository**.

That was intentional. I wanted to be able to refactor aggressively, break things, and clean stuff up without worrying about public stability, and also am heavily thinking about making releasing this somewhat commercially. 

The codebase is now getting to the point where:
- The architecture is solid
- The direction is locked in
- It’s actually maintainable

I do think however, I will be releasing it publicly very soon, once documentation and cleanup are done.

---

## Where This Leaves Nocturne 75 (placeholder name btw)

Nocturne 75 feels like the point where everything finally came together.

One processor.
One system.
Screen, firmware, and hardware all designed together instead of fighting each other.

From here on out, it’s refinement — not reinvention.

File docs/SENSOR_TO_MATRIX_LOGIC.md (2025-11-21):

# Sensor → Matrix logic

Short reference for how sensor numbers (1–48) map to the keyboard matrix positions used in this project.

## Concept

- Sensors are numbered 1..48. Each sensor maps to a matrix row and column in a 4×12 matrix.
- Formula (integer math):

- matrix_row = (sensor - 1) / 12  // integer division
- matrix_col = (sensor - 1) % 12  // remainder

Or the inverse (given matrix row r and column c):

- sensor = r * 12 + c + 1

Notes:
- Rows and columns are zero-indexed for the matrix (rows 0..3, cols 0..11).
- These formulas are exactly what the scanner code in `mux_adc.c` uses when converting a sensor number to a matrix coordinate.

## Examples

- Sensor 1 → row = (1-1)/12 = 0, col = (1-1)%12 = 0 → matrix[0][0]
- Sensor 6 → row = (6-1)/12 = 0, col = (6-1)%12 = 5 → matrix[0][5]
- Sensor 18 → row = (18-1)/12 = 1, col = (18-1)%12 = 5 → matrix[1][5]
- Sensor 48 → row = (48-1)/12 = 3, col = (48-1)%12 = 11 → matrix[3][11]

Inverse examples:
- Row 0, Col 5 → sensor = 0*12 + 5 + 1 = 6
- Row 1, Col 5 → sensor = 1*12 + 5 + 1 = 18

## Quick code snippets

C (same idea used in the firmware):

```c
// sensor is 1..48
uint8_t matrix_row = (sensor - 1) / 12;
uint8_t matrix_col = (sensor - 1) % 12;
// then use matrix_row and matrix_col to set matrix[row][col]
```

Python (for testing / scripting):

```python
def sensor_to_matrix(sensor):
    assert 1 <= sensor <= 48
    row = (sensor - 1) // 12
    col = (sensor - 1) % 12
    return row, col

def matrix_to_sensor(row, col):
    assert 0 <= row < 4 and 0 <= col < 12
    return row * 12 + col + 1
```

## 4 × 12 sensor grid (sensor number → matrix position)

Rows are left→right (cols 0..11). Each cell shows the sensor number and (r,c).

Row 0:  1 (0,0)   2 (0,1)   3 (0,2)   4 (0,3)   5 (0,4)   6 (0,5)   7 (0,6)   8 (0,7)   9 (0,8)  10 (0,9)  11 (0,10) 12 (0,11)

Row 1: 13 (1,0)  14 (1,1)  15 (1,2)  16 (1,3)  17 (1,4)  18 (1,5)  19 (1,6)  20 (1,7)  21 (1,8) 22 (1,9)  23 (1,10) 24 (1,11)

Row 2: 25 (2,0)  26 (2,1)  27 (2,2)  28 (2,3)  29 (2,4)  30 (2,5)  31 (2,6)  32 (2,7)  33 (2,8) 34 (2,9)  35 (2,10) 36 (2,11)

Row 3: 37 (3,0)  38 (3,1)  39 (3,2)  40 (3,3)  41 (3,4)  42 (3,5)  43 (3,6)  44 (3,7)  45 (3,8) 46 (3,9)  47 (3,10) 48 (3,11)

## Practical notes

- The scanner reads a MUX channel, looks up the configured `sensor` number for that channel (from `mux_pins.c`), and applies the formula above to set the corresponding key in the QMK matrix.
- If two different MUX channels are accidentally configured with the same sensor number, pressing either physical key will activate the same matrix position (causing duplicated/ghosted keypresses).
- If a physical key does nothing, check that the MUX channel's `.sensor` value points to the correct sensor number and that the wiring to that MUX channel/4×4 board is good.

Paste this file anywhere you need; it's meant to be a compact copy/paste reference for quick debugging.

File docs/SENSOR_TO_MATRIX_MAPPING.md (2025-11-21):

# Sensor to Matrix Position Mapping

## Where is the sensor-to-matrix array?

**There is NO explicit array!** The mapping is calculated on-the-fly using a simple formula.

## The Formula (in `mux_adc.c` line ~145-146):

```c
uint8_t matrix_row = (key_mapping->sensor - 1) / MATRIX_COLS;  // MATRIX_COLS = 12
uint8_t matrix_col = (key_mapping->sensor - 1) % MATRIX_COLS;
```

## Complete Sensor-to-Matrix Reference Table:

| Sensor # | Matrix Position | Your Keymap Key | Calculation |
|---|---|---|---|
| 1 | [0][0] | ESC | (1-1)/12=0, (1-1)%12=0 |
| 2 | [0][1] | Q | (2-1)/12=0, (2-1)%12=1 |
| 3 | [0][2] | W | (3-1)/12=0, (3-1)%12=2 |
| 4 | [0][3] | E | (4-1)/12=0, (4-1)%12=3 |
| 5 | [0][4] | R | (5-1)/12=0, (5-1)%12=4 |
| 6 | [0][5] | T | (6-1)/12=0, (6-1)%12=5 |
| 7 | [0][6] | Y | (7-1)/12=0, (7-1)%12=6 |
| 8 | [0][7] | U | (8-1)/12=0, (8-1)%12=7 |
| 9 | [0][8] | I | (9-1)/12=0, (9-1)%12=8 |
| 10 | [0][9] | O | (10-1)/12=0, (10-1)%12=9 |
| 11 | [0][10] | P | (11-1)/12=0, (11-1)%12=10 |
| 12 | [0][11] | BSPC | (12-1)/12=0, (12-1)%12=11 |
| 13 | [1][0] | TAB | (13-1)/12=1, (13-1)%12=0 |
| 14 | [1][1] | A | (14-1)/12=1, (14-1)%12=1 |
| 15 | [1][2] | S | (15-1)/12=1, (15-1)%12=2 |
| 16 | [1][3] | D | (16-1)/12=1, (16-1)%12=3 |
| 17 | [1][4] | F | (17-1)/12=1, (17-1)%12=4 |
| 18 | [1][5] | G | (18-1)/12=1, (18-1)%12=5 |
| 19 | [1][6] | H | (19-1)/12=1, (19-1)%12=6 |
| 20 | [1][7] | J | (20-1)/12=1, (20-1)%12=7 |
| 21 | [1][8] | K | (21-1)/12=1, (21-1)%12=8 |
| 22 | [1][9] | L | (22-1)/12=1, (22-1)%12=9 |
| 23 | [1][10] | SCLN (;) | (23-1)/12=1, (23-1)%12=10 |
| 24 | [1][11] | ENT | (24-1)/12=1, (24-1)%12=11 |
| 25 | [2][0] | LSFT | (25-1)/12=2, (25-1)%12=0 |
| 26 | [2][1] | Z | (26-1)/12=2, (26-1)%12=1 |
| 27 | [2][2] | X | (27-1)/12=2, (27-1)%12=2 |
| 28 | [2][3] | C | (28-1)/12=2, (28-1)%12=3 |
| 29 | [2][4] | V | (29-1)/12=2, (29-1)%12=4 |
| 30 | [2][5] | B | (30-1)/12=2, (30-1)%12=5 |
| 31 | [2][6] | N | (31-1)/12=2, (31-1)%12=6 |
| 32 | [2][7] | M | (32-1)/12=2, (32-1)%12=7 |
| 33 | [2][8] | COMM (,) | (33-1)/12=2, (33-1)%12=8 |
| 34 | [2][9] | DOT (.) | (34-1)/12=2, (34-1)%12=9 |
| 35 | [2][10] | SLSH (/) | (35-1)/12=2, (35-1)%12=10 |
| 36 | [2][11] | RSFT | (36-1)/12=2, (36-1)%12=11 |
| 37 | [3][0] | LCTL | (37-1)/12=3, (37-1)%12=0 |
| 38 | [3][1] | LGUI (Win) | (38-1)/12=3, (38-1)%12=1 |
| 39 | [3][2] | LALT | (39-1)/12=3, (39-1)%12=2 |
| 40 | [3][3] | MO(1) | (40-1)/12=3, (40-1)%12=3 |
| 41 | [3][4] | SPC | (41-1)/12=3, (41-1)%12=4 |
| 42 | [3][5] | SPC | (42-1)/12=3, (42-1)%12=5 |
| 43 | [3][6] | SPC | (43-1)/12=3, (43-1)%12=6 |
| 44 | [3][7] | MO(2) | (44-1)/12=3, (44-1)%12=7 |
| 45 | [3][8] | RALT | (45-1)/12=3, (45-1)%12=8 |
| 46 | [3][9] | RGUI | (46-1)/12=3, (46-1)%12=9 |
| 47 | [3][10] | APP | (47-1)/12=3, (47-1)%12=10 |
| 48 | [3][11] | RCTL | (48-1)/12=3, (48-1)%12=11 |

## How to Use This:

1. **Test a physical key** on your MUX board
2. **Note which key it types** (e.g., it types "ENTER")
3. **Find that key in the table above** (ENT is sensor 24, matrix [1][11])
4. **Update your mux_pins.c** to map that MUX channel to sensor 24

Example:
```c
// If MUX1 CH15 physically types "ENTER", then:
[15] = { .sensor = 24, .key = "Ent" },  // CH15 wired to sensor 24
```

## Quick Lookup by Key:

- **ESC**: sensor 1
- **Q**: sensor 2
- **TAB**: sensor 13
- **A**: sensor 14
- **ENTER**: sensor 24
- **LSHIFT**: sensor 25
- **Z**: sensor 26
- **SPACE**: sensors 41, 42, 43

The sensor number completely determines what key is pressed!

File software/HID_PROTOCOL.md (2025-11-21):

# HID Protocol Documentation

## Overview
This document describes the HID communication protocol for sending GIF files from the Electron app to your keyboard, which forwards them to the ESP32.

## Packet Structure
Each HID report is 64 bytes (configurable in `config.js`):

```
Byte 0:    Report ID (typically 0x00)
Byte 1:    Command byte
Byte 2:    Destination flag
Bytes 3+:  Command-specific data
```

## Commands

### 1. Start GIF Transfer (0x01)
Initiates a GIF transfer session.

**Packet Layout:**
```
[0x00] Report ID
[0x01] Command: Start GIF
[0x01/0x02] Destination: 0x01=Screen, 0x02=SD Card
[4 bytes] Total file size (little-endian uint32)
[2 bytes] Total chunks (little-endian uint16)
[remaining] Padding
```

### 2. GIF Data Chunk (0x02)
Sends a chunk of GIF data.

**Packet Layout:**
```
[0x00] Report ID
[0x02] Command: GIF Data
[0x01/0x02] Destination flag
[2 bytes] Chunk index (little-endian uint16)
[1 byte] Chunk size (0-59 bytes)
[59 bytes] Chunk data
```

### 3. End GIF Transfer (0x03)
Signals completion of GIF transfer.

**Packet Layout:**
```
[0x00] Report ID
[0x03] Command: End GIF
[0x01/0x02] Destination flag
[remaining] Padding
```

## Destination Flags
- `0x01`: Send to Screen (ESP32 displays immediately)
- `0x02`: Save to SD Card (ESP32 stores on SD card)

## Timing
- **Start delay**: 50ms after sending start packet
- **Packet delay**: 10ms between data chunks
- These can be adjusted in `config.js`

## Keyboard Implementation

Your keyboard firmware should:

1. **Receive HID reports** via USB
2. **Parse the command byte** to determine action
3. **Forward to ESP32** via UART/SPI/I2C with the destination flag
4. **Handle acknowledgments** (optional, for reliability)

### Example Keyboard Code (Pseudocode)
```c
void handle_hid_report(uint8_t* data, uint16_t len) {
    uint8_t cmd = data[1];
    uint8_t dest = data[2];
    
    switch(cmd) {
        case 0x01: // Start GIF
            uint32_t size = *(uint32_t*)&data[3];
            uint16_t chunks = *(uint16_t*)&data[7];
            esp32_start_gif_transfer(size, chunks, dest);
            break;
            
        case 0x02: // Data chunk
            uint16_t index = *(uint16_t*)&data[3];
            uint8_t chunk_size = data[5];
            esp32_send_gif_chunk(index, &data[6], chunk_size, dest);
            break;
            
        case 0x03: // End
            esp32_end_gif_transfer(dest);
            break;
    }
}
```

## Setup Instructions

1. **Install node-hid**:
   ```bash
   npm install node-hid
   ```

2. **Find your keyboard's VID/PID**:
   ```bash
   node find-keyboard.js
   ```

3. **Update config.js** with your keyboard's VID/PID

4. **Test the connection** by running the app and sending a small GIF

## Troubleshooting

### "Keyboard not found"
- Check VID/PID in `config.js`
- Run `find-keyboard.js` to verify device is detected
- Ensure keyboard is connected and recognized by Windows

### Transfer fails or is slow
- Adjust timing in `config.js`
- Check HID report size matches your keyboard
- Verify keyboard firmware is processing packets

### ESP32 doesn't receive data
- Check UART/SPI/I2C connection between keyboard and ESP32
- Verify baud rate and protocol
- Add debug logging in keyboard firmware

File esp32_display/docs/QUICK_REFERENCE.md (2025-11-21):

# Quick Reference Guide - ESP32 GIF Player Menus

## 🎮 UART Commands Cheat Sheet

### Menu Navigation
| Command | Description |
|---|---|
| `MENU_OPEN` | Open GIF select menu |
| `SETTINGS_OPEN` | Open settings menu |
| `MENU_CLOSE` | Close menu, return to GIF |
| `MENU_UP` | Navigate up / Decrease timer |
| `MENU_DOWN` | Navigate down / Increase timer |
| `MENU_SELECT` | Select / Toggle / Start-Stop |
| `MENU_CYCLE_RIGHT` | Cycle menus → |
| `MENU_CYCLE_LEFT` | Cycle menus ← |
| `STATUS` | Get current state |

---

## 📋 Settings Menu Items

```
Settings:
  > < Back                      [SELECT = Exit]
    SOCD: ON/OFF                [SELECT = Toggle]
    Debugging                   [Header - not selectable]
      Raw Keycodes: ON/OFF      [SELECT = Toggle]
      Keypress Detect: ON/OFF   [SELECT = Toggle]
      ADC Printing: ON/OFF      [SELECT = Toggle]
```

**Navigation**: Auto-skips "Debugging" header  
**Timeout**: 5 seconds of inactivity

---

## ⏱️ Timer Menu Controls

### When Stopped:
- `MENU_UP` → Decrease minutes (min: 1)
- `MENU_DOWN` → Increase minutes (max: 99)
- `MENU_SELECT` → Start countdown
- **Visual**: Orange arrows ▲▼ visible

### When Running:
- **Any button** → Stop & Reset
- **Auto-update**: Every 100ms
- **No timeout**: Runs indefinitely

### On Expiration:
- Screen flashes 3× (white/black)
- "TIME'S UP!" message
- Returns to stopped state (00:00)

---

## 🎨 Text Offset Editing

### Quick Start:
1. Trigger popup (e.g., press key)
2. Check Serial Monitor:
   ```
   [POPUP] Title: "Keypress" | X_OFFSET: 0
   ```
3. Edit line ~110 in sketch:
   ```cpp
   {"Keypress", 15},  // +15px right
   ```
4. Upload

### Rules:
- **Positive** = shift RIGHT
- **Negative** = shift LEFT
- **0** = left edge (default)
- **Auto**: `0x____` gets +8px

---

## 🚦 Debug Popup Types

| UART Message | Popup Title | Body Color |
|---|---|---|
| `RAW_KEYCODE: 0x001C` | Keypress | Yellow |
| `[DEBUG] Key printing: ON` | Key Printing | Green |
| `[DEBUG] Key printing: OFF` | Key Printing | Red |
| `[DEBUG] Raw keycodes: ON` | Raw Keycodes | Green |
| `[DEBUG] Raw keycodes: OFF` | Raw Keycodes | Red |
| `[DEBUG] ADC printing: ON` | ADC printing | Green |
| `[DEBUG] ADC printing: OFF` | ADC printing | Red |
| `SOCD: Enabled` | SOCD status | Green |
| `SOCD: Disabled` | SOCD status | Red |

**Display**: 750ms (keycodes) or 1500ms (settings)  
**Behavior**: No GIF pause, immediate draw

---

## 🔧 Common Tasks

### Change Timer Default (5 min → X min):
Line 79: `int timerMinutes = 5;` → `int timerMinutes = X;`

### Adjust Popup Duration:
Line 76: `unsigned long debugPopupDefaultMs = 1500;`

### Move ALL Keycodes Right 10px:
Line 140-143: Change `return 8;` → `return 10;`

### Add New Setting to Menu:
1. Add bool at line ~72 (e.g., `bool setting_xyz = false;`)
2. Add to items array in `drawSettingsMenu()` (~line 1112)
3. Add handler in `handleSettingsSelection()` (~line 1150)
4. Update total count in MENU_UP/DOWN handlers

---

## 📊 Menu State Variables

```cpp
currentMenuType          // MENU_GIF, MENU_SETTINGS, MENU_TIMER
inMenu                   // true if any menu is open
menuSelection           // GIF menu cursor position
settingsSelection       // Settings menu cursor position
timerMinutes           // Timer duration (adjustable)
timerRunning           // Timer active state
setting_socd_enabled   // SOCD toggle state
// ... more settings
```

---

## 🐛 Troubleshooting

### Popup Text Not Moving:
1. Check Serial Monitor for exact string
2. Ensure entry matches exactly (case-insensitive ok)
3. Verify comma after each entry (except last)
4. Recompile and upload

### Timer Not Starting:
- Ensure you're in TIMER menu (not SETTINGS)
- Check Serial Monitor for "Timer started" message
- Try resetting with any button first

### Menu Stuck/Frozen:
- Send `MENU_CLOSE` via UART
- Menu auto-exits after 5s timeout (except timer)
- Physical buttons also work (if wired)

### Popups Flickering:
- Should be fixed now (immediate draw mode)
- If still flickering, check Serial for errors
- Ensure latest code is uploaded

---

## 💾 Backup Settings Before Editing

### Critical Lines to Backup:
- Lines 95-120: Manual offset table
- Lines 60-84: Menu state and settings
- Lines 410-800: handleQMKCommands() function

### Safe Edit Areas:
- Offset X values (can't break anything)
- Timer default minutes
- Popup duration (milliseconds)
- Color definitions (TFT_GREEN, etc.)

---

## 📞 Quick Debug Commands

```cpp
// In Serial Monitor or QMK:
STATUS                    // Check current menu state
[DEBUG] ADC printing: ON  // Test ADC popup
RAW_KEYCODE: 0x001C       // Test keycode popup
SOCD: Enabled             // Test SOCD popup
SETTINGS_OPEN             // Open settings
MENU_CLOSE                // Force close menu
```

---

## 🎯 Best Practices

1. **Test popups first**: Trigger each type and copy exact strings
2. **Small adjustments**: Move text by ±5px at a time
3. **Backup often**: Save working offset values
4. **Serial Monitor**: Always keep open during testing
5. **One change**: Edit one offset at a time, test, repeat

---

**For detailed information, see `CHANGELOG_2025-10-02.md`**

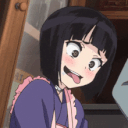
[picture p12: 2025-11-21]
assets/lick.gif

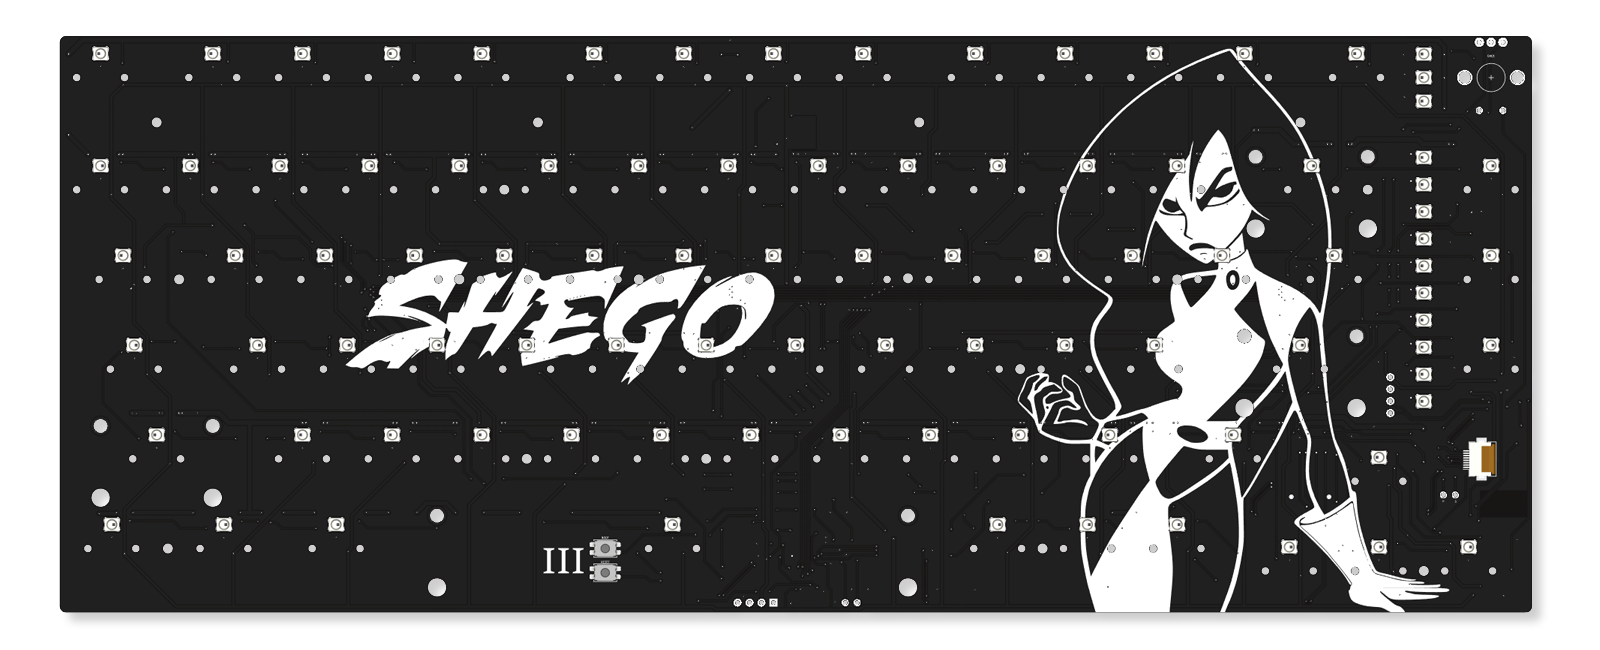
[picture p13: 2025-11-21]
assets/pcb_front.png

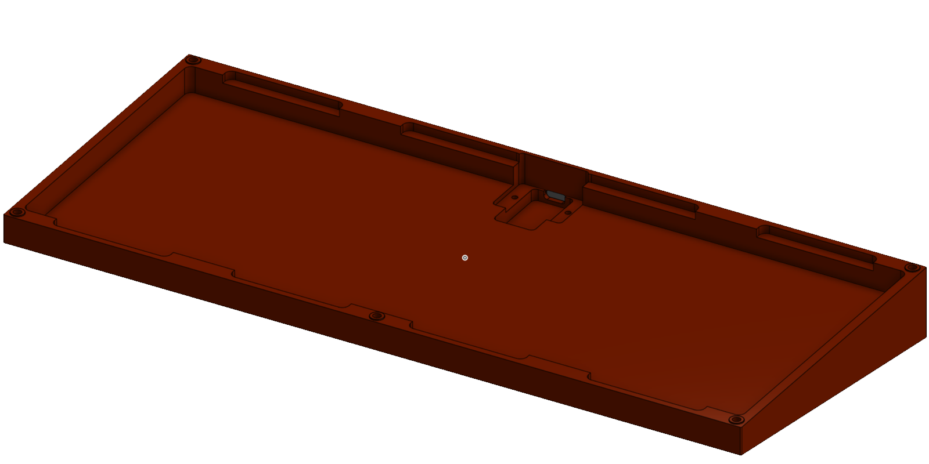
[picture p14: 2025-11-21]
assets/case_lower.png

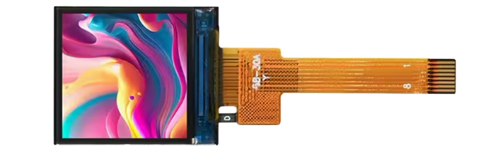
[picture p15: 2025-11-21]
assets/screen.png

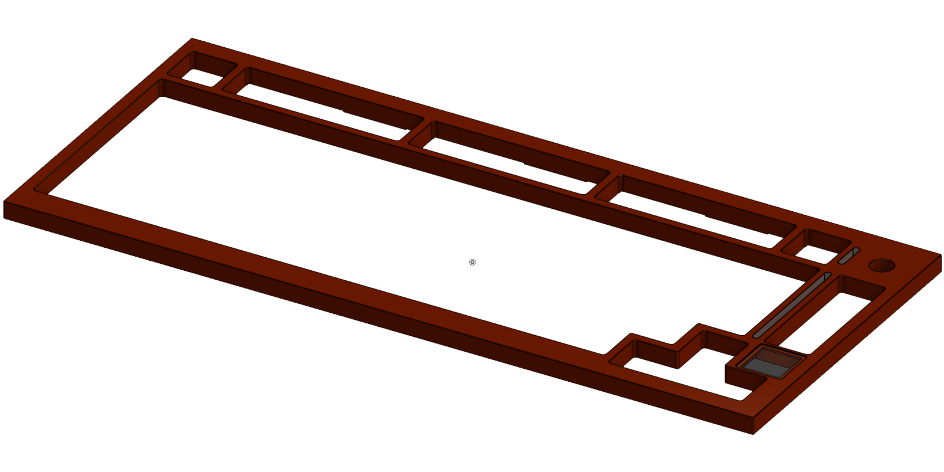
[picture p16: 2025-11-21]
assets/case_upper.png

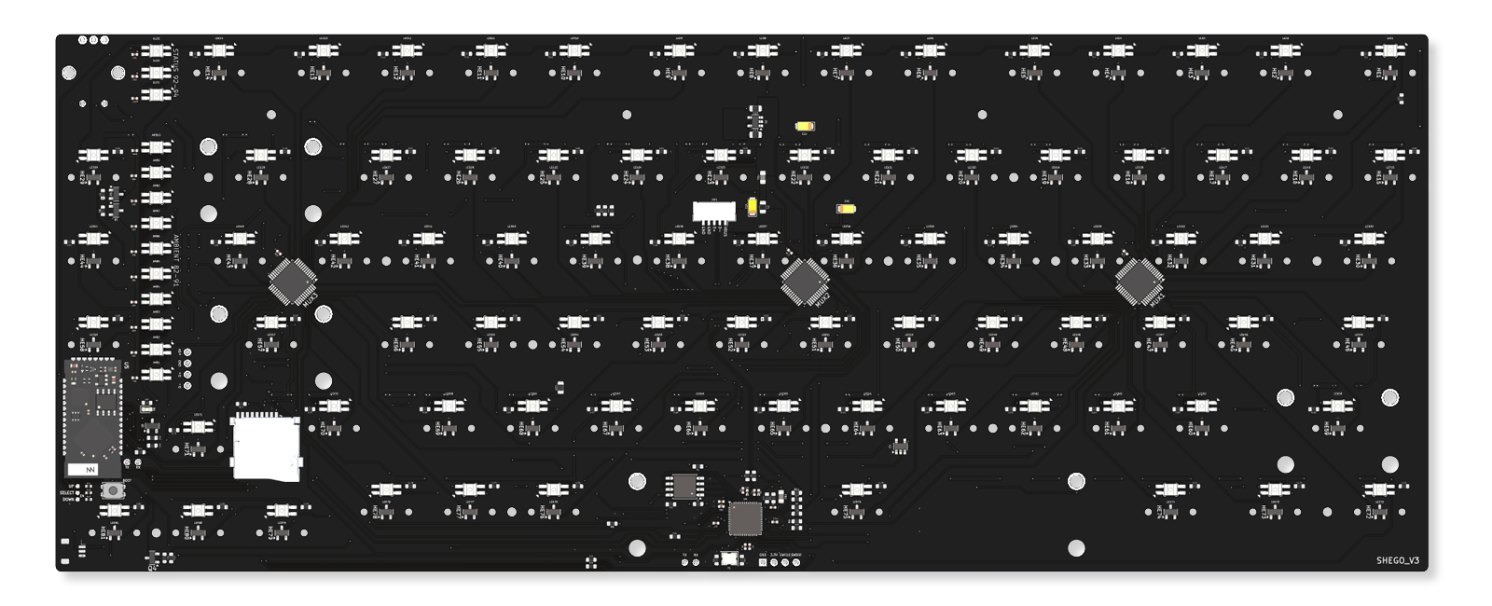
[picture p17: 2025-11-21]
assets/pcb_back.png

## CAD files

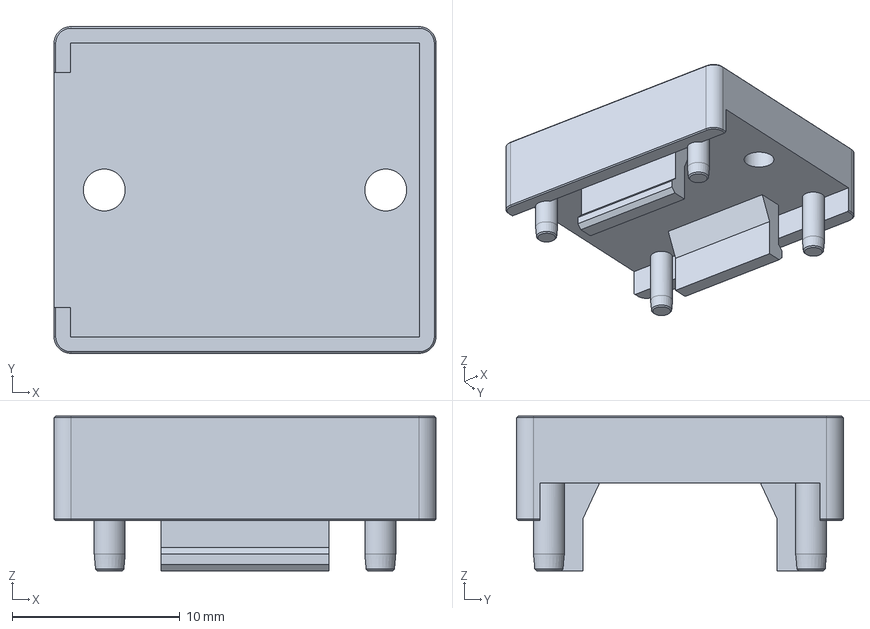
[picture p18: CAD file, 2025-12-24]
case/SHEGO75 - ScreenHolder 0.025.step
22.8 x 19.5 x 9.25 mm

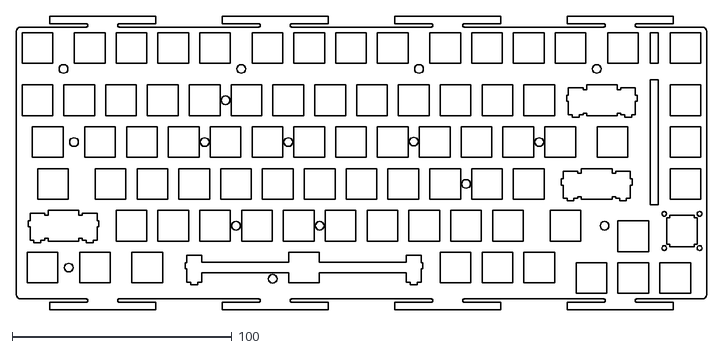
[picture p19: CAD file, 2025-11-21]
pcbs/SHEGO75-V5/Shego75_plate.dxf
314.3 x 133.8

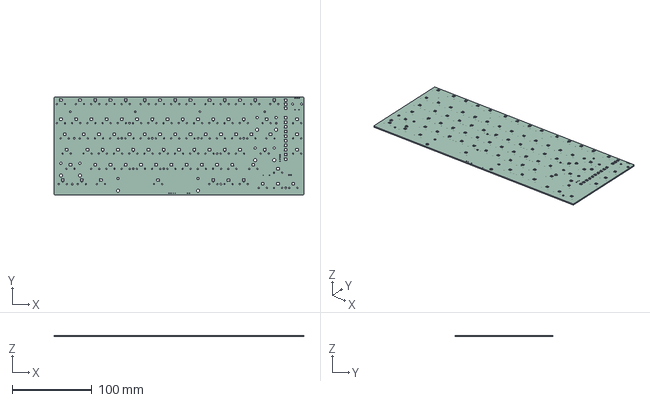
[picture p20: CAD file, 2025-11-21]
pcbs/SHEGO75-V5/SHEGO75-v3_outline.step
312.5 x 122.3 x 1.51 mm

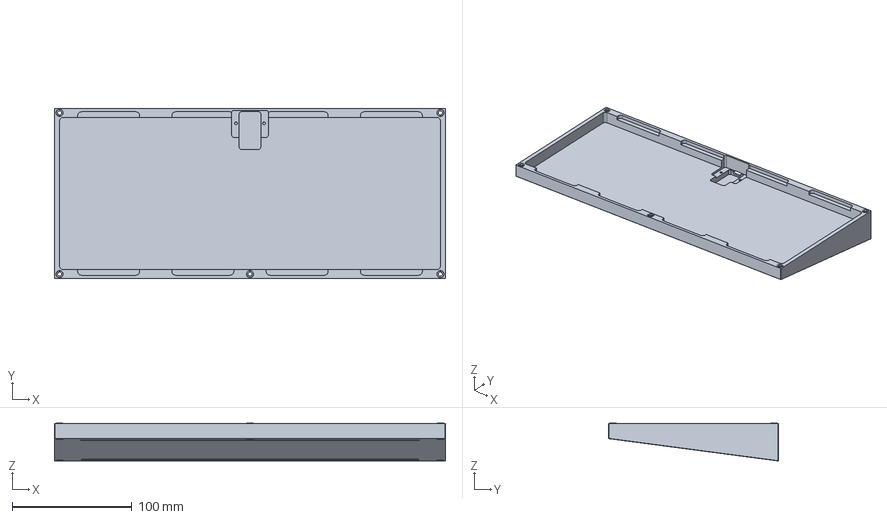
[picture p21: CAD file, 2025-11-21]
case/SHEGO75 - CASE_LOWER-V1.step
326.0 x 142.0 x 31.7 mm

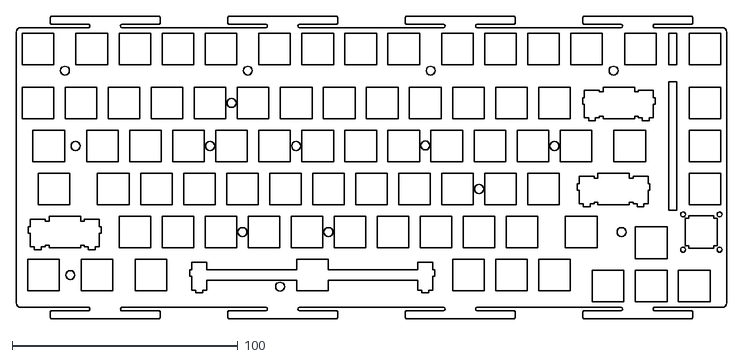
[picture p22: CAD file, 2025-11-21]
case/SHEGO75 - PLATE-v1.dxf
314.3 x 133.8

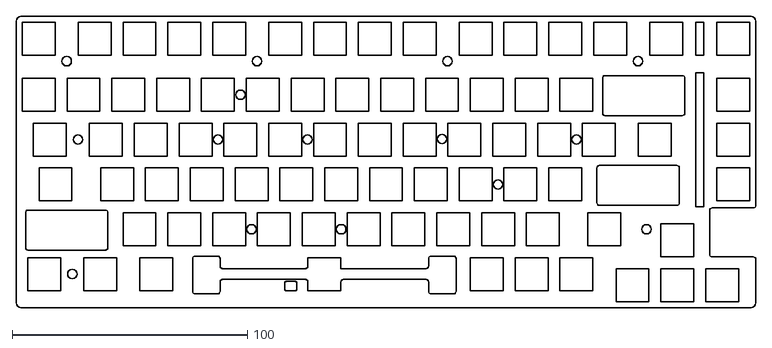
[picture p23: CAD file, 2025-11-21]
case/SHEGO75 - FOAM.dxf
314.3 x 123.8

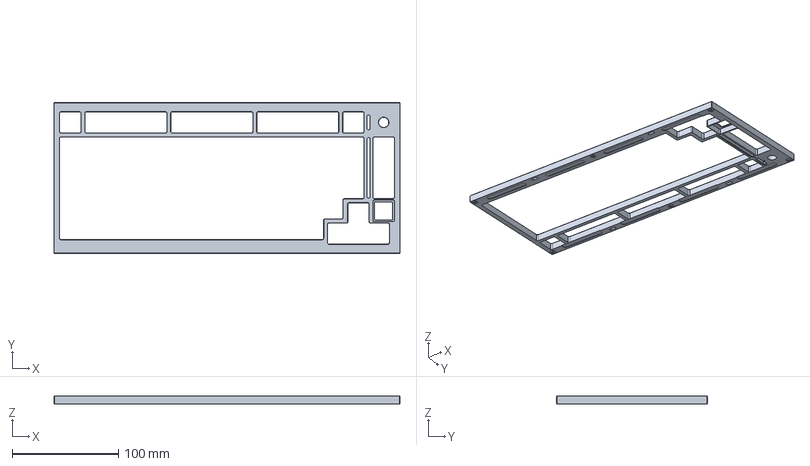
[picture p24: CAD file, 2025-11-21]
case/SHEGO75 - CASE_UPPER-V1.step
326.0 x 142.0 x 7.50 mm

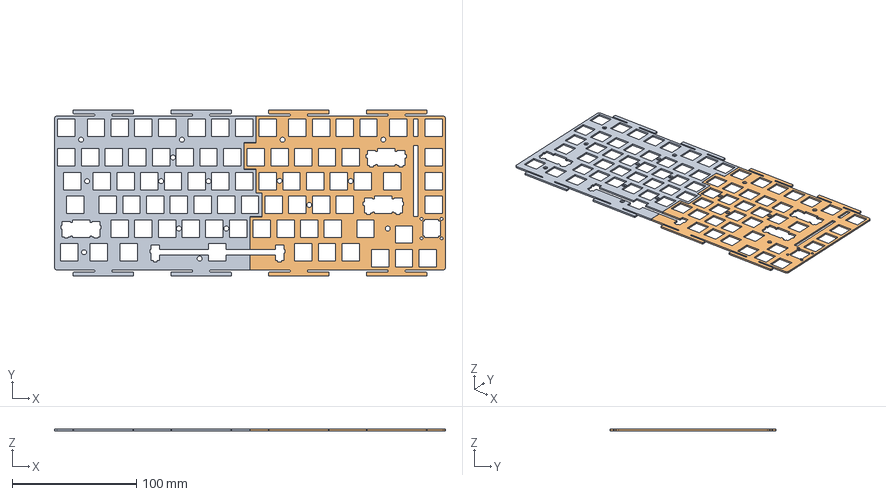
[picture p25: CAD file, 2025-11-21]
case/SHEGO75_PLATE_SPLIT.step
314.3 x 133.8 x 1.50 mm

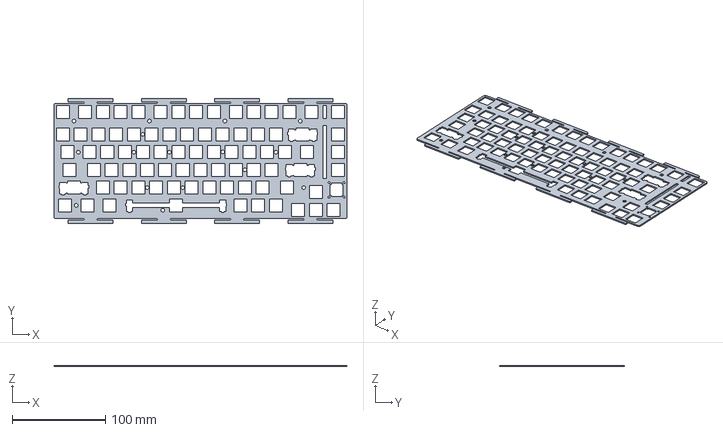
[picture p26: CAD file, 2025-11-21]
case/SHEGO75 - PLATE-V2.step
314.3 x 133.8 x 1.50 mm

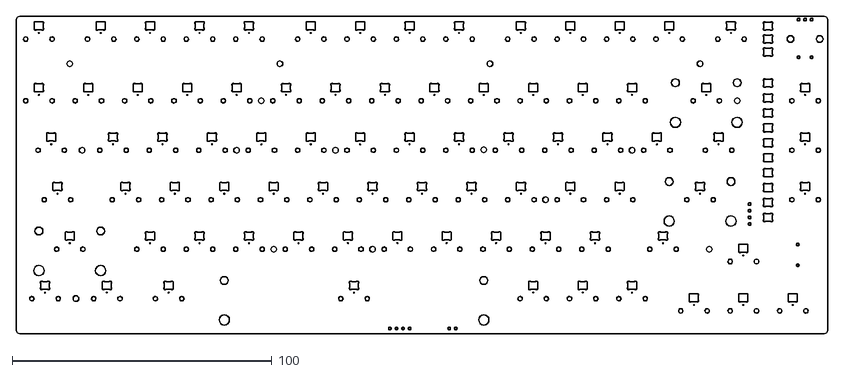
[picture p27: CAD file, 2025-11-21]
case/SHEGO75 - IPXE_FOAM.dxf
312.5 x 122.3

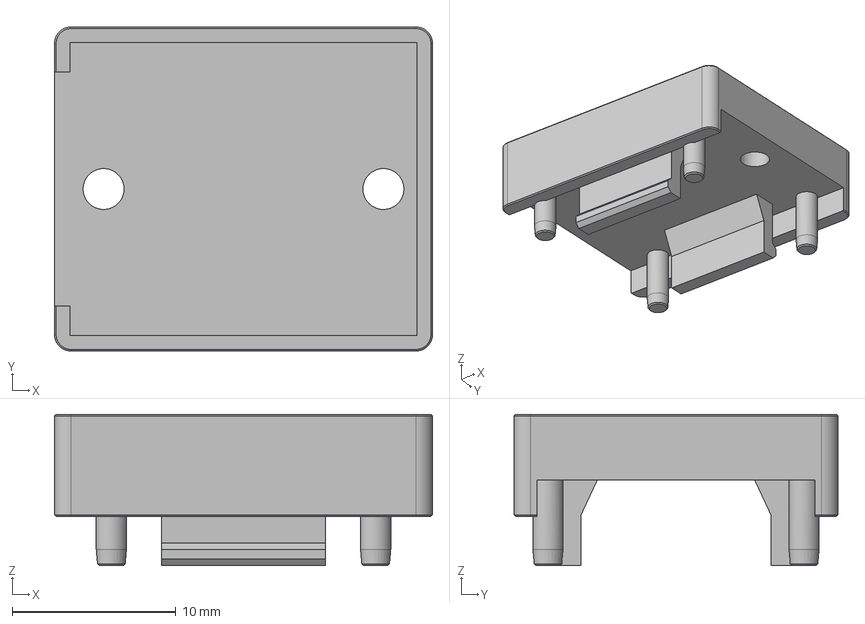
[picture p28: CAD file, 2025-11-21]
case/SHEGO75 - ScreenHolder.step
23.1 x 19.8 x 9.25 mm

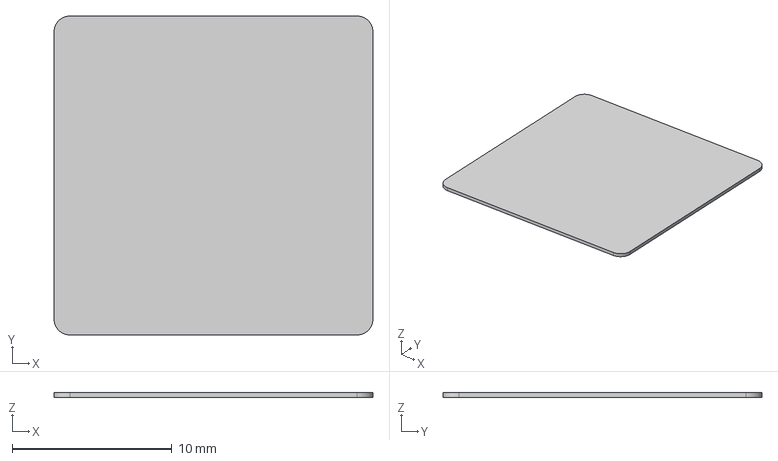
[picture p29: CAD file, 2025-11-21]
case/SHEGO75 - ProtectiveFilm.step
20.0 x 20.0 x 0.3 mm

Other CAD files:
case/SHEGO75 - ScreenHolder 0.1.step
pcbs/SHEGO75-V5/SHEGO75_blank.step
case/SHEGO75 - Drawing 1.dwg
case/SHEGO75 - ScreenHolder_notab.step
pcbs/SHEGO75-V4/SHEGO75_blank.step

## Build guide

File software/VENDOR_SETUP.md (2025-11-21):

# Vendor Bulk Endpoint Setup Guide

Your Electron app now supports high-speed vendor bulk endpoints with automatic fallback to raw HID.

## 🚀 Quick Start

### 1. Install Dependencies
```bash
cd software
npm install usb
```

### 2. Build & Flash Firmware  
The firmware is already configured with `VENDOR_ENABLE`. Just rebuild and flash:
```bash
qmk compile -kb shego75_v1 -km default
# Flash the resulting firmware to your keyboard
```

### 3. Test Vendor Communication
```bash
cd software
node test-vendor.js
```

## 🔧 How It Works

### Firmware Changes
- **`VENDOR_ENABLE`** - Enables vendor interface in USB descriptors  
- **Vendor Interface** - USB class 0xFF bulk endpoints (64-byte packets)
- **`vendor_task()`** - Polls vendor OUT endpoint, called from `matrix_scan_user()`
- **Shared Processing** - Both vendor and HID use `hid_process_received_buffer()`

### App Changes
- **Primary**: Tries vendor bulk endpoints first (faster, larger packets)
- **Fallback**: Uses raw HID if vendor fails (compatibility)
- **Auto-detection**: Finds vendor interface (class 0xFF) automatically
- **Bigger chunks**: 61-byte vs 29-byte payloads (vendor vs HID)

### Transport Comparison
| Method | Chunk Size | Speed | Driver Req (Win) | Compatibility |
|---|---|---|---|---|
| Vendor Bulk | 61 bytes | Fast | WinUSB (Zadig) | Modern |
| Raw HID | 29 bytes | Slower | None | Universal |

## 🪟 Windows Setup (Driver Binding)

On Windows, vendor endpoints need a libusb-compatible driver:

### Using Zadig (Recommended)
1. Download [Zadig](https://zadig.akeo.ie/)
2. **With keyboard connected**, run Zadig as Administrator
3. **Options → List All Devices** ✓
4. Find your keyboard (VID: 0xDEAD, PID: 0xC0DE)
5. Look for the **vendor interface** (not HID interface!)
6. Select **WinUSB** driver → **Replace Driver**

### Verification
- Device Manager should show your keyboard with both HID and USB (WinUSB) entries
- `node test-vendor.js` should find vendor interface and send test packets

## 🐛 Troubleshooting

### "Vendor interface not found"
- ✅ Firmware built with `VENDOR_ENABLE` defined
- ✅ Keyboard flashed with new firmware  
- ✅ Device enumerated properly (check Device Manager)

### "Failed to claim vendor interface" (Windows)
- ✅ Use Zadig to bind vendor interface to WinUSB
- ✅ Run Node.js as Administrator if needed

### "USB library not available"
- ✅ Run `npm install usb` in software folder
- ✅ May need build tools on Windows (Visual Studio Build Tools)

### Transfer Issues
- ✅ Check ESP32 debug output for I2C messages
- ✅ Verify `vendor_task()` is called in `matrix_scan_user()`
- ✅ Check firmware console for HID debug messages

## 📊 Performance

Expected transfer speeds for a 100KB GIF:
- **Vendor**: ~2-3 seconds (61-byte chunks @ 10ms delay)
- **HID**: ~4-5 seconds (29-byte chunks @ 10ms delay)

## 🔄 Fallback Behavior

The app automatically tries vendor first, then HID:

```javascript
// Electron automatically tries:
1. Open vendor interface (class 0xFF)
2. If vendor fails → open HID interface  
3. Use appropriate chunk size for chosen method
4. Send same protocol packets (START/DATA/END)
```

Both paths forward to the same `hid_process_received_buffer()` on the device.

## 🧪 Testing

```bash
# Test vendor communication only
node test-vendor.js

# Test with actual Electron app  
npm run dev
# Use "Send GIF" - check console for "Using vendor bulk endpoints"
```

## 📁 Files Modified

### Firmware
- `config.h` - Added `#define VENDOR_ENABLE`  
- `usb_descriptor.h/.c` - Added vendor interface descriptors
- `vendor_bridge.h/.c` - Vendor endpoint polling and packet sending
- `hid_reports.c` - Refactored into shared processor
- `keymap.c` - Added `vendor_task()` call in `matrix_scan_user()`

### Software  
- `main.js` - Added vendor support with HID fallback
- `package.json` - Added `usb` dependency
- `test-vendor.js` - Vendor endpoint test script

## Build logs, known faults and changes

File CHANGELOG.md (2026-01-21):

# Shego75HE - Dev Branch Developer Diary

## 2026-01-21

Over the past few months, I’ve been doing a lot of deep architectural work on this project — rethinking the firmware, the screen integration, and the overall direction of the keyboard. Rather than trying to summarise all of that here, I’ve written a much more detailed design journal that explains the decisions, dead ends, and turning points properly. If you’re interested in the full context behind these changes, see `update.md` for the complete write-up.

## 2025-11-21
- Added vendor-class USB descriptors and host-side vendor/bulk support (experimental).
  - Firmware: descriptors added and a `vendor_bridge` stub introduced so host tools can detect a vendor interface; shared HID processing extracted into `hid_process_received_buffer()` to unify raw-HID and vendor paths.
  - Host: Electron app updated to prefer `node-usb` vendor bulk endpoints with a `node-hid` fallback; test utilities created (`test-vendor.js`, `try-claim.js`, `debug-usb-interface.js`) to enumerate, claim, and exercise vendor endpoints on Windows (Zadig/WinUSB or libusbK required).
  - Debugging: one-shot IN transfers replaced `startPoll()` in tests to avoid libusb pending-transfer races; remaining Windows libusb polling race noted for follow-up.

- SOCD and input handling improvements.
  - Fixed SOCD logic to avoid duplicate key registrations on release and ensured `socd_process_key()` handles registrations/unregistrations itself to prevent QMK double-processing.

- Sensor / ADC tuning and crosstalk work.
  - Auto-calibration kept but per-key sensitivity made adjustable; default sensitivity tuned (developer tested values 2%→4% during tuning).
  - Debounce lowered for snappier response (runtime tuned from 5ms down to 2ms in testing); matrix scan throttle adjusted during tuning to free CPU for RGB rendering (various values tried: 2–5ms; 1.5ms target discussed).
  - Investigated MUX-channel crosstalk (adjacent-channel bleed observed). Firmware includes diagnostic output and temporary mitigation strategies, but hardware fixes (filter caps, routing changes, remapping) recommended as the proper solution.

- LED / RGB and power changes.
  - Inverted GP23 LED logic to match new two-transistor (BSS138 + AO3401) gate circuit; initialization and toggle logic updated accordingly.
  - Added `RGB_MATRIX_MAXIMUM_BRIGHTNESS` cap (70%) to reduce heat.

- Encoder fixes and VIA support.
  - Encoder handler fixed so `encoder_map` is honored; direction inversion and resolution options were tested (resolution restored to 4, direction inverted per user preference).
  - Created a `shego75he-via.json` definition and documented loading it into VIA (Design → Load Draft Definition) so VIA recognizes custom keycodes (QK_USER / custom actions).

- Misc and testing notes
  - Multiple host test scripts and small utilities added to `software/` to exercise vendor endpoints and debug claim/release behavior on Windows with libusb-based backends.
  - Ongoing: implement proper ChibiOS/QMK vendor endpoint handling in firmware (non-stub), and finish host-side robust vendor handshake to fully validate end-to-end vendor → I2C → ESP32 GIF streaming.

## 2025-11-04
- Finalized full firmware integration for working board in `shego75_v1/`.
  - Verified full boot sequence and peripheral initialization.
  - Cleaned up debug output and confirmed stable board operation.
- Updated LED logic for consistent startup state.
  - Adjusted light commit routines in `rgb_control.c`.
- Confirmed all modules (ADC, MUX, display, encoder) operate synchronously.
- Added minor refinements to USB HID behavior and timing.

## 2025-11-01
- Refined SOCD cleaning logic in `shego75_v1/holoscan.c`.
  - Prevented double-press behavior on key release.
  - Adjusted key state transitions and debounce edge handling.
- Updated internal variable naming for clarity.
- Verified key scanning stability after SOCD updates.

## 2025-10-26
- Added preliminary I2C support to `esp32_display/`.
  - Implemented base I2C communication functions.
  - Evaluating UART replacement for data streaming.
- Began GUI app logic for key actuation adjustment and GIF upload.
  - Introduced base structure for user configuration commands.
- Updated actuation logic in `shego75_v1/holoscan.c`.
  - Added automatic calibration at startup.
  - Uses 15% deviation (≈85% threshold) for press registration.
- Removed old PCB versions (v2.1, v2.2) and migrated to TinyPico Nano base.
  - Cleaned outdated design references in firmware.

## 2025-10-23
- Added LED MOSFET and encoder pin defines in `shego75_v1/pins.h`.
  - Updated pin mapping for v2.2 hardware.
- Refined scanning behavior and encoder logic.
  - Confirmed new encoder pins functional under revised firmware.
- Minor cleanup across hardware abstraction layer.
  - Adjusted timing constants in `shego75_v1/main.c`.

## 2025-10-15
- Minor schematic and firmware tidying.
  - Simplified internal hardware mapping arrays.
  - Adjusted power pin defines for upcoming PCB rev.

## 2025-10-14
- Introduced v2.1 hardware layout updates (transistors, pin changes).
  - Updated `pins.h` and `board_config.c` to match new schematic.
  - Continued work on firmware compatibility.

## 2025-10-05
- Added SignalRGB plugin files for LED integration (`plugins/signalrgb/`).
  - Added packet encoder for LED frame updates.
- Replaced HC4067 logic with ADG732 in `shego75_v1/holoscan.c`.
  - Rewrote MUX channel handling and pin selection logic.
- Created typedef enums for sensor-mux mapping.
  - Simplified multiplexed ADC reads and loop structure.
- Added `.gitignore` and removed unnecessary assets.
  - Cleaned temporary test scripts and debug files.
- Merged unified `dev` branch with stable foundation.

## 2025-10-03
- Initialized main repo with minimal structure.
  - Added `README.md` and stub firmware directories.
  - Set up initial branch for early development.

---

### Notes
This changelog compiles all commits (including minor tweaks and experiments) across the `dev` branch, excluding hardware CAD files under `pcbs/` and `case/`. Each section reflects functional and structural code changes drawn from commit diffs.

---

## 24/12/2025 - Merry Christmas! GIANT UPDATE!
I’ve got the software working and a completely new firmware stack built from the ground up. The app is **Electron-based** and (honestly) was mostly vibe-coded while I iterated on UX and device behavior. The firmware is also brand new—written specifically for this project and its multi‑MCU architecture.

A big part of this update is that we **moved fully away from QMK**. Instead of adapting QMK to fit the hardware and features, we started from scratch with a firmware designed around our exact data paths and performance goals: **USB HID on the RP2040**, a clean **UART link** to the ESP32 for UI/display responsibilities, and **SPI** for high-throughput TFT updates. Dropping QMK gave us tighter control over timing, memory, and feature integration, and removed the friction of forcing a general-purpose keyboard firmware into a system that’s doing more than “just key scanning.”

The project is currently in a private repo. If you want to follow along or chat about it, my Discord is **hyupdo**.

---

### App Preview

<h5 align="center">Keys</h5>

Keys Tab

<h5 align="center">Lighting</h5>

Lighting Tab

<h5 align="center">Performance</h5>

Performance Tab

live preview

<h5 align="center" style="margin-bottom: 0;">Screen</h5>

<div align="center" style="font-style: italic; line-height: 1;">
  <small>This feature is only available on the Shego75</small>
</div>

live preview

<div align="center" style="line-height: 2;">
  <small>Storage system using the SD ('Send to SD' yet to be implemented)</small>
</div>

live preview

### How to use:

#### Keys

Configure per-key actuation points, dead zones, and key assignments. The live visualization shows real-time magnetic sensor readings and key states. Customize individual key behavior with adjustable sensitivity ranges and enable anti-ghosting features. Export and import key profiles for quick configuration switching.

#### Lighting

In the **Lighting** tab, effects are driven using **SignalRGB**, which treats the keyboard like an addressable LED device and streams color data in real time. Once enabled, SignalRGB can take control of animations (audio-reactive, game integrations, ambient effects) and push them directly to the board so lighting stays perfectly in sync with the rest of your setup. You can still fine-tune how the device presents itself to SignalRGB—especially how LEDs are grouped and mapped—so the software knows what “keys” or regions it’s actually driving.

To change **zones**, use the zone controls to assign LEDs/keys into separate regions (for example: left half, right half, underglow, indicator cluster, or per-row groups). Each zone can be adjusted independently so you can apply different colors/effects per region, or scale brightness and effect intensity where you want it. After updating zone assignments, apply/save the configuration so the device reports the new layout and SignalRGB (or the app’s built-in effects) will target the updated zones correctly.

#### Performance

The **Performance** tab is a live “health dashboard” for the firmware and transport links, meant to answer one question quickly: *is the device keeping up in real time?* It aggregates timing, throughput, and workload counters so you can confirm that input scanning, lighting updates, and display/UI work are all completing within budget—especially when features are enabled simultaneously.

At a high level, the tab focuses on three areas:

1) **Frame / Loop Timing**
- Shows how long the main firmware loop (or “frame”) takes to run and how consistent it is over time.
- Look for **average**, **min/max**, and **spike** behavior. A stable system has tight variance; frequent spikes suggest something occasionally blocks (heavy rendering, long SPI transfers, or bursts of host traffic).
- If you see a “budget” or target interval, the goal is to keep the loop time comfortably below that target so there’s slack for bursts.

2) **Input Responsiveness**
- Tracks the cadence and workload of key scanning and event processing.
- Useful indicators include scan rate, event queue depth, and any dropped/late events.
- If responsiveness metrics degrade while other features are active, it’s a sign you should reduce background load (very high LED update rates, overly frequent display refresh, or excessive logging/telemetry).

3) **Transport + Subsystem Throughput (Host ⇄ RP2040 ⇄ ESP32 ⇄ TFT)**
- **USB/HID**: lets you see how often the host is sending commands and how quickly the device is responding. Excessive command rates can create overhead and jitter.
- **UART (RP2040 ⇄ ESP32)**: shows whether messages are flowing smoothly between MCUs. Watch for rising queue/backlog counters or retry/error counts—those often correlate with delayed UI updates.
- **SPI (ESP32 ⇄ TFT)**: large, frequent screen updates can dominate time. If you see display-related counters tied to spikes, consider lowering refresh frequency or reducing what’s being redrawn per update.

How to use it in practice:
- Start with everything “idle” and note the baseline loop time and stability.
- Enable one feature at a time (lighting effects, animations, screen updates, host polling) and watch what changes.
- If a metric provides “worst” or “spike” values, treat those as the most important—single long stalls are often more noticeable than a slightly higher average.
- Use the tab as a verification step after configuration changes: if you adjust lighting zones, increase effect complexity, or change display behavior, confirm the loop remains stable and queues don’t grow over time.

If the Performance tab includes error counters (CRC, framing, dropped packets, overflow), any value that steadily increases during normal use usually indicates a configuration or bandwidth issue worth addressing before it impacts responsiveness.

#### Screen

The screen is driven as a simple “remote display” in a two‑MCU chain: the **RP2040** acts as the USB/HID-facing coordinator, and the **ESP32** acts as the display/UI controller. The RP2040 collects system state (and any stats it owns), then sends compact status packets over **UART** to the ESP32. The ESP32 turns those packets into UI state (text, graphs, icons, warnings) and renders the result to the TFT over **SPI**.

**Communication path**
- **Host → RP2040 (USB HID):** the desktop app can request status, enable/disable telemetry, or change what the UI should show (page selection, refresh rate, debug toggles).
- **RP2040 → ESP32 (UART):** the RP2040 forwards the “what to display” information as structured messages (think: page id + key/value metrics + flags). UART is used because it’s reliable, low-latency, and keeps the display work off the RP2040’s timing-critical loop.
- **ESP32 → TFT (SPI):** the ESP32 updates the actual pixels. SPI is a high-throughput link commonly used by small TFTs, and it lets the ESP32 push either partial updates (only what changed) or full frames depending on the UI.

**How it shows “memory and stuff”**
What you see on the screen is ultimately just the ESP32 drawing primitives (text, lines, rectangles, images) based on numbers it receives. Those numbers can come from a few places:
- **ESP32-local stats:** free heap/PSRAM, task runtime, Wi‑Fi state, frame time for rendering, SPI throughput, queue depths. These are measured directly on the ESP32 and then displayed immediately.
- **RP2040 stats:** loop timing, scan workload, HID traffic counters, UART throughput/error counters. The RP2040 measures these and periodically ships them to the ESP32 so they appear in the same UI.
- **Derived/aggregated values:** rates and percentages (e.g., “updates per second”, “max spike”, “avg frame time”) computed from counters over a time window to make the data readable at a glance.

**Display model (why it can update smoothly)**
- The ESP32 keeps a small UI state model (current page, last-known metric values, thresholds, formatting).
- On each update tick, it compares new values to the previous ones and redraws only the regions that changed (e.g., a number field or a graph strip). This avoids pushing a full-screen refresh over SPI when it’s not needed.
- Graphs are typically rendered as rolling plots: the ESP32 stores a short history buffer (last N samples) and draws it as a line or bar chart, which makes “performance” data intuitive without flooding the link.

**Features the screen typically supports**
- **Pages / tabs:** status overview, lighting status, performance graphs, debug info, connectivity.
- **Live counters:** loop/frame time, HID packet rate, UART rate, dropped/overflow counts.
- **Memory readouts:** free heap/PSRAM (ESP32), and any reported RP2040 memory stats if exposed.
- **Warnings:** threshold-based indicators (e.g., queue growing, repeated UART errors, refresh budget exceeded).

In short: the RP2040 and ESP32 exchange lightweight telemetry over UART, and the ESP32 turns that telemetry into a responsive on-screen dashboard by drawing UI elements over SPI to the TFT.

### App Flow

#### The way it works:

order of operations

##### Software
The desktop-side software is the user interface and configuration layer. It connects to the device over **USB HID**, provides a way to change settings (layouts, lighting, display options, etc.), and then sends those changes as compact commands to the firmware. Because it uses HID, it can talk to the device without needing a custom driver on most systems, and it can also be used for debugging/telemetry (reading back status, firmware info, and error codes).

##### RP2040
The RP2040 is the **USB-facing controller** and the central coordinator. It presents itself to the computer as a **HID device**, parses incoming configuration commands from the software, and applies settings that belong on the main MCU (key scanning, state management, timing, etc.). It also acts as a bridge to the secondary MCU over **UART**, forwarding display/network-related commands and receiving status updates so the host can see what the rest of the system is doing.

##### ESP32-PICO-D4
The ESP32-PICO-D4 is responsible for the **high-level peripheral side**, primarily driving the display. It receives messages from the RP2040 over **UART**, interprets them as UI/state updates, and renders to the TFT over **SPI**. It can also be used for features that fit better on the ESP32 (background tasks, connectivity, asset handling), while keeping the RP2040 focused on deterministic USB + input timing.

### Test for yourself
I have put the app up online if you want to browse through, WebHID isn't implemented properly since I primarily focused on USB HID but do check out the themes in the Settings tab!

Link: [nova-8tt.pages.dev](https://nova-8tt.pages.dev)

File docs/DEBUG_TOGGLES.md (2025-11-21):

# UART Debug Toggle System

## Overview
The keyboard now has custom keycodes to toggle debug output via UART, keeping the logic cleanly separated from keymap.c for visual simplicity.

## File Structure

### uart_keycodes.h
- Defines custom keycodes: `DEBUG_ADC`, `DEBUG_KEYS`, `MENU_OPEN`, etc.
- Declares helper functions for debug control
- Can be included anywhere you need the custom keycodes

### uart_keycodes.c
- Implements `process_record_user()` with all custom keycode logic
- Contains state variables: `adc_debug_enabled`, `key_debug_enabled`
- Helper functions:
  - `toggle_adc_debug()` - Toggles ADC value printing (every 1 second)
  - `toggle_key_debug()` - Toggles keypress event printing
  - `get_adc_debug_enabled()` - Returns current ADC debug state
  - `get_key_debug_enabled()` - Returns current key debug state

### mux_adc.c
- Calls `get_adc_debug_enabled()` to check if ADC values should be printed
- Calls `get_key_debug_enabled()` to check if key events should be printed
- No direct dependency on the toggle logic - uses clean getter functions

### keymap.c
- Includes `uart_keycodes.h` to use custom keycodes
- Maps keys to custom keycodes (e.g., X → DEBUG_ADC, Slash → DEBUG_KEYS)
- Does NOT implement `process_record_user()` - that's in uart_keycodes.c

## Custom Keycodes

| Keycode | Value | Mapped to | Function |
|---|---|---|---|
| DEBUG_ADC | SAFE_RANGE | X key | Toggle ADC row printing (every 1s) |
| DEBUG_KEYS | SAFE_RANGE+5 | Slash key | Toggle keypress event messages |
| MENU_OPEN | SAFE_RANGE | - | Send "MENU_OPEN\n" via UART |
| MENU_UP | SAFE_RANGE+1 | - | Send "MENU_UP\n" via UART |
| MENU_DOWN | SAFE_RANGE+2 | - | Send "MENU_DOWN\n" via UART |
| MENU_SELECT | SAFE_RANGE+3 | - | Send "MENU_SELECT\n" via UART |

## Usage

1. **Toggle ADC printing**: Press X key
   - When enabled: Prints all ADC values by row every 1 second
   - When disabled: No periodic ADC output
   - Sends confirmation message: "[DEBUG] ADC printing: ON/OFF"

2. **Toggle key event printing**: Press Slash key
   - When enabled: Prints "Key X: PRESS/RELEASE (R# C#) ADC=###" for each keypress
   - When disabled: Keys still work, but no UART messages
   - Sends confirmation message: "[DEBUG] Key event printing: ON/OFF"

## VIA Compatibility
The code also supports VIA custom keycodes:
- 0xffff → MENU_OPEN
- 0xfffe → MENU_UP
- 0xfffd → MENU_DOWN
- 0xfffc → MENU_SELECT
- 0xfffb → DEBUG_ADC
- 0xfffa → DEBUG_KEYS

## Why This Structure?

✅ **Visual simplicity**: keymap.c stays clean with just key layouts
✅ **Organization**: All UART logic in uart_keycodes.c
✅ **Reusability**: Helper functions can be called from anywhere
✅ **Maintainability**: Easy to add more debug toggles or menu commands
✅ **Clean separation**: mux_adc.c doesn't know about toggle implementation

## Initial State
Both debug outputs start **enabled** by default:
- `adc_debug_enabled = true`
- `key_debug_enabled = true`

Change the initial values in uart_keycodes.c if you want them disabled by default.

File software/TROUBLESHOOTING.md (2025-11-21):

# Troubleshooting Guide: GIF Transfer Not Working

## Current Status (Based on Your Screenshot)

✅ **What's Working:**
- Electron app sends data to keyboard
- HID communication is established
- Transfer completes without errors

❌ **What's Not Working:**
- You're seeing echoes of sent packets logged as "Received from keyboard"
- You don't know if ESP32 is actually receiving/displaying the GIF
- No clear feedback from the firmware

## The Problem

The console shows packets like:
```
Received from keyboard: 0x11 0x04 0x01 0x0a 0x04 0x00 0x88 0x46 ...
```

That `0x11` is `CMD_GIF_DATA` - meaning Windows is echoing back the DATA packets you sent. This is normal behavior, but they should be suppressed.

## Step-by-Step Diagnosis

### 1. Check if Echoes are Being Suppressed

**Replace your current main.js with the improved version**:
```bash
cp /mnt/user-data/outputs/main.js /path/to/your/project/main.js
```

The new version:
- ✅ Better echo suppression using packet signatures
- ✅ Clearer logging (echoes are silent, real messages are shown)
- ✅ Status message detection
- ✅ Better error messages

### 2. Verify Keyboard Firmware is Receiving

**Add debug output to your keyboard firmware** (in `raw_hid_receive_user()`):

```c
void raw_hid_receive_user(uint8_t *data, uint8_t length) {
    // Add this at the very start:
    printf("[HID] Received %d bytes, CMD=0x%02X\n", length, data[0]);
    
    // Your existing code...
}
```

**What to expect:**
- You should see: `[HID] Received 32 bytes, CMD=0x10` (START)
- Then many: `[HID] Received 32 bytes, CMD=0x11` (DATA)
- Finally: `[HID] Received 32 bytes, CMD=0x12` (END)

**If you don't see these messages:**
- ❌ HID data is not reaching your firmware
- Check: USB cable, keyboard enumeration, QMK configuration

### 3. Check ESP32 Communication

**Add debug to your I2C/UART forwarding code**:

```c
// In the function that sends to ESP32:
printf("[I2C] Forwarding CMD=0x%02X, %d bytes to ESP32\n", data[0], length);

// After sending:
printf("[I2C] ESP32 acknowledged: %s\n", ack ? "YES" : "NO");
```

**What to expect:**
```
[I2C] Forwarding CMD=0x10, 32 bytes to ESP32
[I2C] ESP32 acknowledged: YES
[I2C] Forwarding CMD=0x11, 32 bytes to ESP32
[I2C] ESP32 acknowledged: YES
...
```

**If ESP32 doesn't acknowledge:**
- ❌ I2C/UART connection problem
- Check: wiring, pull-ups, baud rate, ESP32 is running

### 4. Verify ESP32 is Processing Data

**Add debug to ESP32 firmware**:

```c
// In your GIF receive function:
Serial.printf("[ESP] Received CMD=0x%02X, size=%d\n", cmd, dataSize);

switch(cmd) {
    case 0x10: // START
        Serial.printf("[ESP] Starting GIF transfer, size=%d, dest=%d\n", totalSize, destination);
        break;
    case 0x11: // DATA
        Serial.printf("[ESP] Chunk %d received\n", chunkIndex);
        break;
    case 0x12: // END
        Serial.printf("[ESP] Transfer complete, displaying GIF\n");
        break;
}
```

**What to expect:**
```
[ESP] Received CMD=0x10, size=13967
[ESP] Starting GIF transfer, size=13967, dest=1
[ESP] Chunk 0 received
[ESP] Chunk 1 received
...
[ESP] Chunk 481 received
[ESP] Received CMD=0x12, size=1
[ESP] Transfer complete, displaying GIF
```

**If ESP32 gets corrupted data:**
- ❌ Data corruption during I2C/UART transfer
- Try: slower I2C speed, shorter wires, better power supply

### 5. Test with Minimal Example

**Create a test script to send just ONE packet**:

```javascript
// test-single-packet.js
const HID = require('node-hid');
const config = require('./config');

const devices = HID.devices();
const keyboard = devices.find(d => 
  d.vendorId === config.KEYBOARD_VID && 
  d.productId === config.KEYBOARD_PID && 
  d.interface === 1
);

if (!keyboard) {
  console.error('Keyboard not found!');
  process.exit(1);
}

const hid = new HID.HID(keyboard.path);

// Listen for responses
hid.on('data', (data) => {
  console.log('Received:', Array.from(data).map(b => '0x' + b.toString(16).padStart(2, '0')).join(' '));
});

// Send a single START packet
const packet = Buffer.alloc(33);
packet[0] = 0x00; // Report ID
packet[1] = config.CMD_START_GIF; // 0x10
packet.writeUInt16LE(100, 2); // Small size
packet[4] = config.DEST_SCREEN; // 0x01

console.log('Sending:', Array.from(packet).slice(0, 10).map(b => '0x' + b.toString(16).padStart(2, '0')).join(' '), '...');
hid.write(Array.from(packet));

setTimeout(() => {
  console.log('Done. Check keyboard/ESP32 debug output.');
  hid.close();
}, 1000);
```

Run it and check debug output on keyboard AND ESP32.

## Common Issues and Solutions

### Issue 1: "Received from keyboard" shows echoes
**Solution:** Use the improved main.js provided above

### Issue 2: No debug output from keyboard firmware
**Solution:** 
- Check USB serial monitor is connected at correct baud rate
- Enable `CONSOLE_ENABLE = yes` in QMK rules.mk
- Add `printf()` calls as shown above

### Issue 3: Keyboard receives data but ESP32 doesn't
**Solution:**
- Check I2C/UART wiring
- Verify ESP32 is powered and running
- Test I2C with a simple ping/pong before transferring GIFs
- Try slower I2C clock speed (100kHz instead of 400kHz)

### Issue 4: ESP32 receives data but doesn't display GIF
**Solution:**
- Check GIF decoding library is working
- Test with a tiny GIF (e.g., 64x64, 2 frames)
- Verify screen initialization
- Check memory allocation (large GIFs need lots of RAM)

### Issue 5: Transfer works sometimes, fails other times
**Solution:**
- Increase `PACKET_DELAY_MS` in config.js (try 20ms or 50ms)
- Add handshaking (wait for ACK after each chunk)
- Check USB cable quality
- Try different USB port

## Expected Console Output (After Fix)

With the improved main.js, you should see:

```
============================================================
📤 Starting GIF transfer to Screen
File: example.gif (13967 bytes)
============================================================
📊 Transfer details:
   Destination: Screen (flag: 0x1)
   Chunk size: 29 bytes
   Total chunks: 482
   Estimated time: ~4.8s

📤 Sending START command...
📤 Sending data chunks...
   Progress: 10% (50/482 chunks)
   Progress: 20% (100/482 chunks)
   ...
   Progress: 100% (482/482 chunks)

📤 Sending END command...
============================================================
✅ Transfer Complete
============================================================

⏳ Waiting for firmware response...
   (If you see no status messages, check firmware debug output)
```

**If your firmware sends status messages**, you'll also see:
```
✅ Status from keyboard: Transfer started (0x3)
✅ Status from keyboard: Chunk received (0x2)
✅ Status from keyboard: Transfer complete (0x4)
```

## Next Steps

1. **Install the improved main.js**
2. **Add debug output to keyboard firmware**
3. **Add debug output to ESP32 firmware**
4. **Run the app and compare output**
5. **Share the keyboard AND ESP32 debug logs** if still not working

## Quick Test Command

```bash
# Run with debug enabled
HID_DEBUG=1 npm run dev
```

This will show detailed packet information.

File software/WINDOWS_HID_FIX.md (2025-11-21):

# Windows HID Report ID Fix

## The Problem

When sending HID data from Electron to the keyboard, **Windows was stripping the first byte** before passing it to the QMK firmware's `raw_hid_receive_user()` callback.

### What Was Happening

```
Electron sent:      [0x10][0x8f][0x36][0x01][...]
                     ^^^^  ^^^^  ^^^^  ^^^^
                     CMD   SIZE  SIZE  DEST

Windows stripped:   [0x10] ← Interpreted as Report ID, removed!

Firmware received:        [0x8f][0x36][0x01][...]
                          ^^^^  ^^^^  ^^^^
                          ???   ???   ???
```

The keyboard firmware was seeing garbage because the command byte was missing!

## The Solution

**Always prefix packets with `0x00` as the Report ID:**

```
Electron sends:     [0x00][0x10][0x8f][0x36][0x01][...]
                     ^^^^  ^^^^  ^^^^  ^^^^  ^^^^
                     RPT   CMD   SIZE  SIZE  DEST
                     ID

Windows strips:     [0x00] ← Report ID removed
                     ^^^^

Firmware receives:        [0x10][0x8f][0x36][0x01][...]
                          ^^^^  ^^^^  ^^^^  ^^^^
                          CMD   SIZE  SIZE  DEST  ✓
```

## Implementation

### Before (Broken)
```javascript
const packet = Buffer.alloc(64);
packet[0] = 0x10;  // CMD_START_GIF
packet[1] = size & 0xFF;
packet[2] = (size >> 8) & 0xFF;
packet[3] = destination;
device.write(Array.from(packet));
```

### After (Fixed)
```javascript
const packet = Buffer.alloc(65);  // +1 for Report ID
packet[0] = 0x00;  // Report ID (required by Windows HID)
packet[1] = 0x10;  // CMD_START_GIF
packet[2] = size & 0xFF;
packet[3] = (size >> 8) & 0xFF;
packet[4] = destination;
device.write(Array.from(packet));
```

## Why This Happens

From the Windows HID documentation:

> When an application calls WriteFile to send a HID report to a device, the first byte of the buffer must contain the report ID. If the device doesn't use report IDs, set this to 0x00.

The `node-hid` library on Windows follows this convention, so **every packet must start with a Report ID byte** (typically `0x00` for raw HID).

## What Changed

All three packet types now include the `0x00` prefix:

1. **START packet**: `[0x00][0x10][size_low][size_high][dest][...]`
2. **DATA packet**: `[0x00][0x11][...63 bytes of GIF data...]`
3. **END packet**: `[0x00][0x12][dest][...]`

## Testing

After this fix, you should see debug messages on the keyboard's UART showing:

```
[HID] raw_hid_receive_user called!
[HID] Command: 0x10 (START_GIF)
[HID] Size: 13967 bytes
[HID] Destination: 0x01 (Screen)
[I2C] Forwarding to ESP32...
```

## References

- [Windows HID Concepts](https://docs.microsoft.com/en-us/windows-hardware/drivers/hid/introduction-to-hid-concepts)
- [node-hid Documentation](https://github.com/node-hid/node-hid#usage)
- [QMK Raw HID Documentation](https://docs.qmk.fm/#/feature_rawhid)

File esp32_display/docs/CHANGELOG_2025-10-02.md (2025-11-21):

# ESP32 GIF Player - Development Log (October 2, 2025)

## 🎯 Major Features Added Today

### 1. **On-Screen Debug Popups System** 
Real-time semi-transparent overlays that appear over GIF playback without interrupting animation.

#### Features:
- **Multi-line popups**: Title + 2 body lines
- **Color-coded text**: 
  - Green for "ON/Enabled" states
  - Red for "OFF/Disabled" states  
  - Yellow for keycodes
- **Immediate draw mode**: Popups render instantly without pausing GIF (no flicker/dissolve)
- **Auto-positioning**: Left-aligned text with manual per-string X-offset control
- **Smart detection**: Handles both raw UART messages and `[DEBUG]` prefixed messages

#### Supported Debug Messages:
```
RAW_KEYCODE: 0x____      → "Keypress" popup with yellow hex code
[DEBUG] Key printing: ON/OFF     → "Key Printing" popup
[DEBUG] Raw keycodes: ON/OFF     → "Raw Keycodes" popup  
[DEBUG] ADC printing: ON/OFF     → "ADC printing" popup
SOCD: Enabled/Disabled           → "SOCD status" popup
```

---

### 2. **Manual Text Offset System**
Pixel-perfect positioning for every text string in popups.

#### Location: Lines 95-147
```cpp
ManualOffset manualOffsets[] = {
  {"Keypress detection", 10},   // Shift title right 10px
  {"0x001C", -5},                // Shift keycode left 5px
  {"ADC printing", 0},           // No shift (left edge)
};
```

#### Features:
- **Per-string control**: Each exact text string can have its own X offset
- **Positive = right shift**, **negative = left shift**
- **Automatic hex detection**: Any string starting with `0x` gets +8px offset
- **Case-insensitive matching**: Works with uppercase/lowercase variants
- **Serial Monitor debug**: Prints exact strings when popups appear for easy copy-paste

---

### 3. **New Multi-Menu System**
Complete menu overhaul with settings, timer, and future stopwatch support.

#### Menu Types:
1. **GIF Select Menu** (existing, enhanced)
2. **Settings Menu** (NEW)
3. **Timer Menu** (NEW)
4. **Stopwatch Menu** (planned, not implemented yet)

---

### 4. **Settings Menu** (`SETTINGS_OPEN`)

Full-screen black menu with persistent toggle settings.

#### Menu Structure:
```
Settings:
  > < Back               ← Select to exit
    SOCD: ON             ← Toggle SOCD (green=ON, red=OFF)
    Debugging            ← Non-selectable header
      Raw Keycodes: OFF
      Keypress Detect: OFF
      ADC Printing: OFF
```

#### Navigation:
- `MENU_UP` / `MENU_DOWN`: Navigate (auto-skips "Debugging" header)
- `MENU_SELECT`: Toggle selected setting or exit (if "Back" selected)
- Settings persist across menu opens/closes
- 5-second timeout (returns to GIF playback)

#### Persistent Settings:
- `setting_socd_enabled`
- `setting_raw_keycodes_enabled`
- `setting_keypress_detection_enabled`
- `setting_adc_printing_enabled`

---

### 5. **Timer Menu** (`TIMER_OPEN`)

Full-screen countdown timer with real-time updates.

#### Features:
- **Big centered digital display**: `MM:SS` format (size 4 font)
- **Adjustable duration**:
  - `MENU_UP`: Decrease minutes (min: 1 minute)
  - `MENU_DOWN`: Increase minutes (max: 99 minutes)
- **Visual indicators**: Small orange arrows (▲/▼) shown when stopped
- **Start/Stop**:
  - `MENU_SELECT` when stopped: Starts countdown
  - Any button when running: Resets/stops timer
- **Real-time countdown**: Updates every 100ms
- **Expiration effect**: 
  - Screen flashes 3 times (white background, black "TIME'S UP!" text)
  - 200ms flash intervals
  - Returns to stopped timer display

#### Timer Persistence:
- Timer continues running even when cycling between menus
- Current time/state preserved across menu navigation
- No timeout while timer is running

---

### 6. **Menu Cycling System** (For Future Stopwatch)

Horizontal navigation between timer and stopwatch menus.

#### Commands:
- `MENU_CYCLE_RIGHT`: Cycle to next menu (timer → stopwatch)
- `MENU_CYCLE_LEFT`: Cycle to previous menu (stopwatch → timer)

**Note**: Stopwatch not yet implemented (placeholder ready)

---

## 🔧 Technical Improvements

### Bug Fixes:
1. **Popup flicker eliminated**: Changed from request/pause pattern to immediate inline draw
2. **GIF dissolve artifact fixed**: Proper mutex management and immediate draws
3. **Variable scope errors**: Fixed `tableTitleX/Line1X/Line2X` declarations
4. **Duplicate popup titles**: Separated "Key Printing" vs "Raw Keycodes" vs "Keypress" popups
5. **Text centering issues**: Switched to left-alignment with manual offsets
6. **Serial spam reduction**: Removed "starting playback loop" repeated message

### Code Architecture:
- **Menu type enum**: `MENU_GIF`, `MENU_SETTINGS`, `MENU_TIMER`, `MENU_STOPWATCH`
- **Context-aware commands**: MENU_UP/DOWN/SELECT behave differently per menu type
- **Mutex-protected draws**: All immediate popup draws use proper SPI mutex
- **State persistence**: Settings and timer state preserved across menu changes
- **No blocking**: Timer updates in `loop()` without blocking GIF playback

---

## 📡 New UART Commands

### Settings & Menus:
```
SETTINGS_OPEN       → Open settings menu
TIMER_OPEN          → Open timer menu (not yet implemented, use after SETTINGS_OPEN + MENU_CYCLE)
MENU_CYCLE_RIGHT    → Cycle menus right
MENU_CYCLE_LEFT     → Cycle menus left
```

### Existing Commands (Enhanced):
```
MENU_OPEN           → Open GIF select menu
MENU_CLOSE          → Close any menu, return to GIF
MENU_UP             → Navigate up / Decrease timer minutes
MENU_DOWN           → Navigate down / Increase timer minutes
MENU_SELECT         → Select item / Toggle setting / Start-Stop timer
STATUS              → Get current menu state and GIF info
```

**Context-aware behavior**: UP/DOWN/SELECT change function based on active menu type.

---

## 📝 Code Locations

### Key Files:
- **Main sketch**: `esp32_tft_sd_menu_lowpower.ino`
- **GIF draw callback**: `GIFDraw.ino` (handles transparency and frame rendering)

### Important Sections:
- **Lines 95-147**: Manual text offset table (edit here for positioning)
- **Lines 60-84**: Menu state variables and settings toggles
- **Lines 410-720**: `handleQMKCommands()` - UART command parsing
- **Lines 1073-1188**: Settings menu implementation
- **Lines 1193-1309**: Timer menu implementation
- **Lines 1388-1461**: Debug popup drawing functions

---

## 🎨 Visual Design

### Settings Menu:
- Black background
- White text (default)
- Yellow selected item background
- Green "ON" text
- Red "OFF" text
- Thin white scrollbar thumb (right edge)

### Timer Menu:
- Black background
- White large timer digits (size 4 font)
- Orange triangular arrows (▲/▼)
- Green "Running..." status
- Yellow "UP/DOWN=Adjust" instructions
- White/black flash effect on expiration

### Debug Popups:
- Near-black rounded rectangle background (RGB 8,8,8)
- White border
- White title text
- Color-coded body text (green/red/yellow/white)
- Left-aligned with manual X offsets
- No longer centered (easier pixel-perfect positioning)

---

## 🔮 Planned Features (Not Yet Implemented)

### Stopwatch Menu:
- Start/pause with MENU_SELECT
- Reset with MENU_UP or MENU_DOWN
- Big centered display (MM:SS.ms format)
- Persistent state across menu cycles
- Access via MENU_CYCLE_LEFT/RIGHT from timer

---

## 🚀 How to Use

### 1. Upload the sketch to your ESP32

### 2. Open Serial Monitor (115200 baud)

### 3. Send UART commands from QMK or Serial Monitor:

#### View Settings:
```
SETTINGS_OPEN
```
Navigate with MENU_UP/DOWN, toggle with MENU_SELECT

#### Use Timer:
```
SETTINGS_OPEN
MENU_CYCLE_RIGHT    (once stopwatch implemented, or add TIMER_OPEN command)
```
Adjust minutes with UP/DOWN, start with SELECT

#### Customize Popup Positions:
1. Trigger a popup (e.g., press a key with raw keycodes enabled)
2. Check Serial Monitor for exact string:
   ```
   [POPUP] Title: "Keypress" | X_OFFSET: 0
   [POPUP] Line1: "0x001C" | X_OFFSET: 8
   ```
3. Add entry to `manualOffsets[]` array (line ~110):
   ```cpp
   {"Keypress", 15},   // Shift right 15px
   {"0x001C", -5},     // Shift left 5px
   ```
4. Recompile and upload

---

## 🐛 Known Issues

### Fixed Today:
- ✅ Popup flicker/dissolve
- ✅ GIF pause artifacts
- ✅ Duplicate popup titles
- ✅ Text centering inconsistencies
- ✅ Compile errors (variable scope)

### Remaining:
- ⏱️ Stopwatch not implemented
- 📍 No direct `TIMER_OPEN` command yet (workaround: use SETTINGS_OPEN + MENU_CYCLE)

---

## 💡 Tips & Tricks

### Perfect Text Positioning:
1. Use Serial Monitor to see exact strings
2. Start with offset `0` (left edge)
3. Adjust by ±5px increments
4. Positive = right, negative = left
5. Automatic +8px for hex codes (`0x____`)

### Timer Best Practices:
- Set duration before starting
- Any button stops/resets running timer
- No timeout while timer runs
- Timer persists if you cycle menus

### Settings Persistence:
- Toggle settings in menu
- Settings remain even after exiting
- Check Serial Monitor for state changes
- Settings don't auto-send to QMK (read-only display)

---

## 📊 Statistics

### Lines of Code Added: ~400+
### New Functions: 8
- `enterSettingsMenu()`
- `drawSettingsMenu()`
- `handleSettingsSelection()`
- `enterTimerMenu()`
- `drawTimerMenu()`
- `handleTimerSelection()`
- `updateTimer()`
- `getManualOffset()`

### New UART Commands: 4
### New State Variables: 12
### Bug Fixes: 6+

---

## 🙏 Credits

**Development Session**: October 2, 2025  
**Developer**: GitHub Copilot + User Collaboration  
**Platform**: ESP32 + TFT_eSPI + AnimatedGIF  
**Branch**: `exp` (experimental)

---

## 📄 License

Same as parent project (ESP32-GIF-Player)

---

**Happy coding! 🎮✨**

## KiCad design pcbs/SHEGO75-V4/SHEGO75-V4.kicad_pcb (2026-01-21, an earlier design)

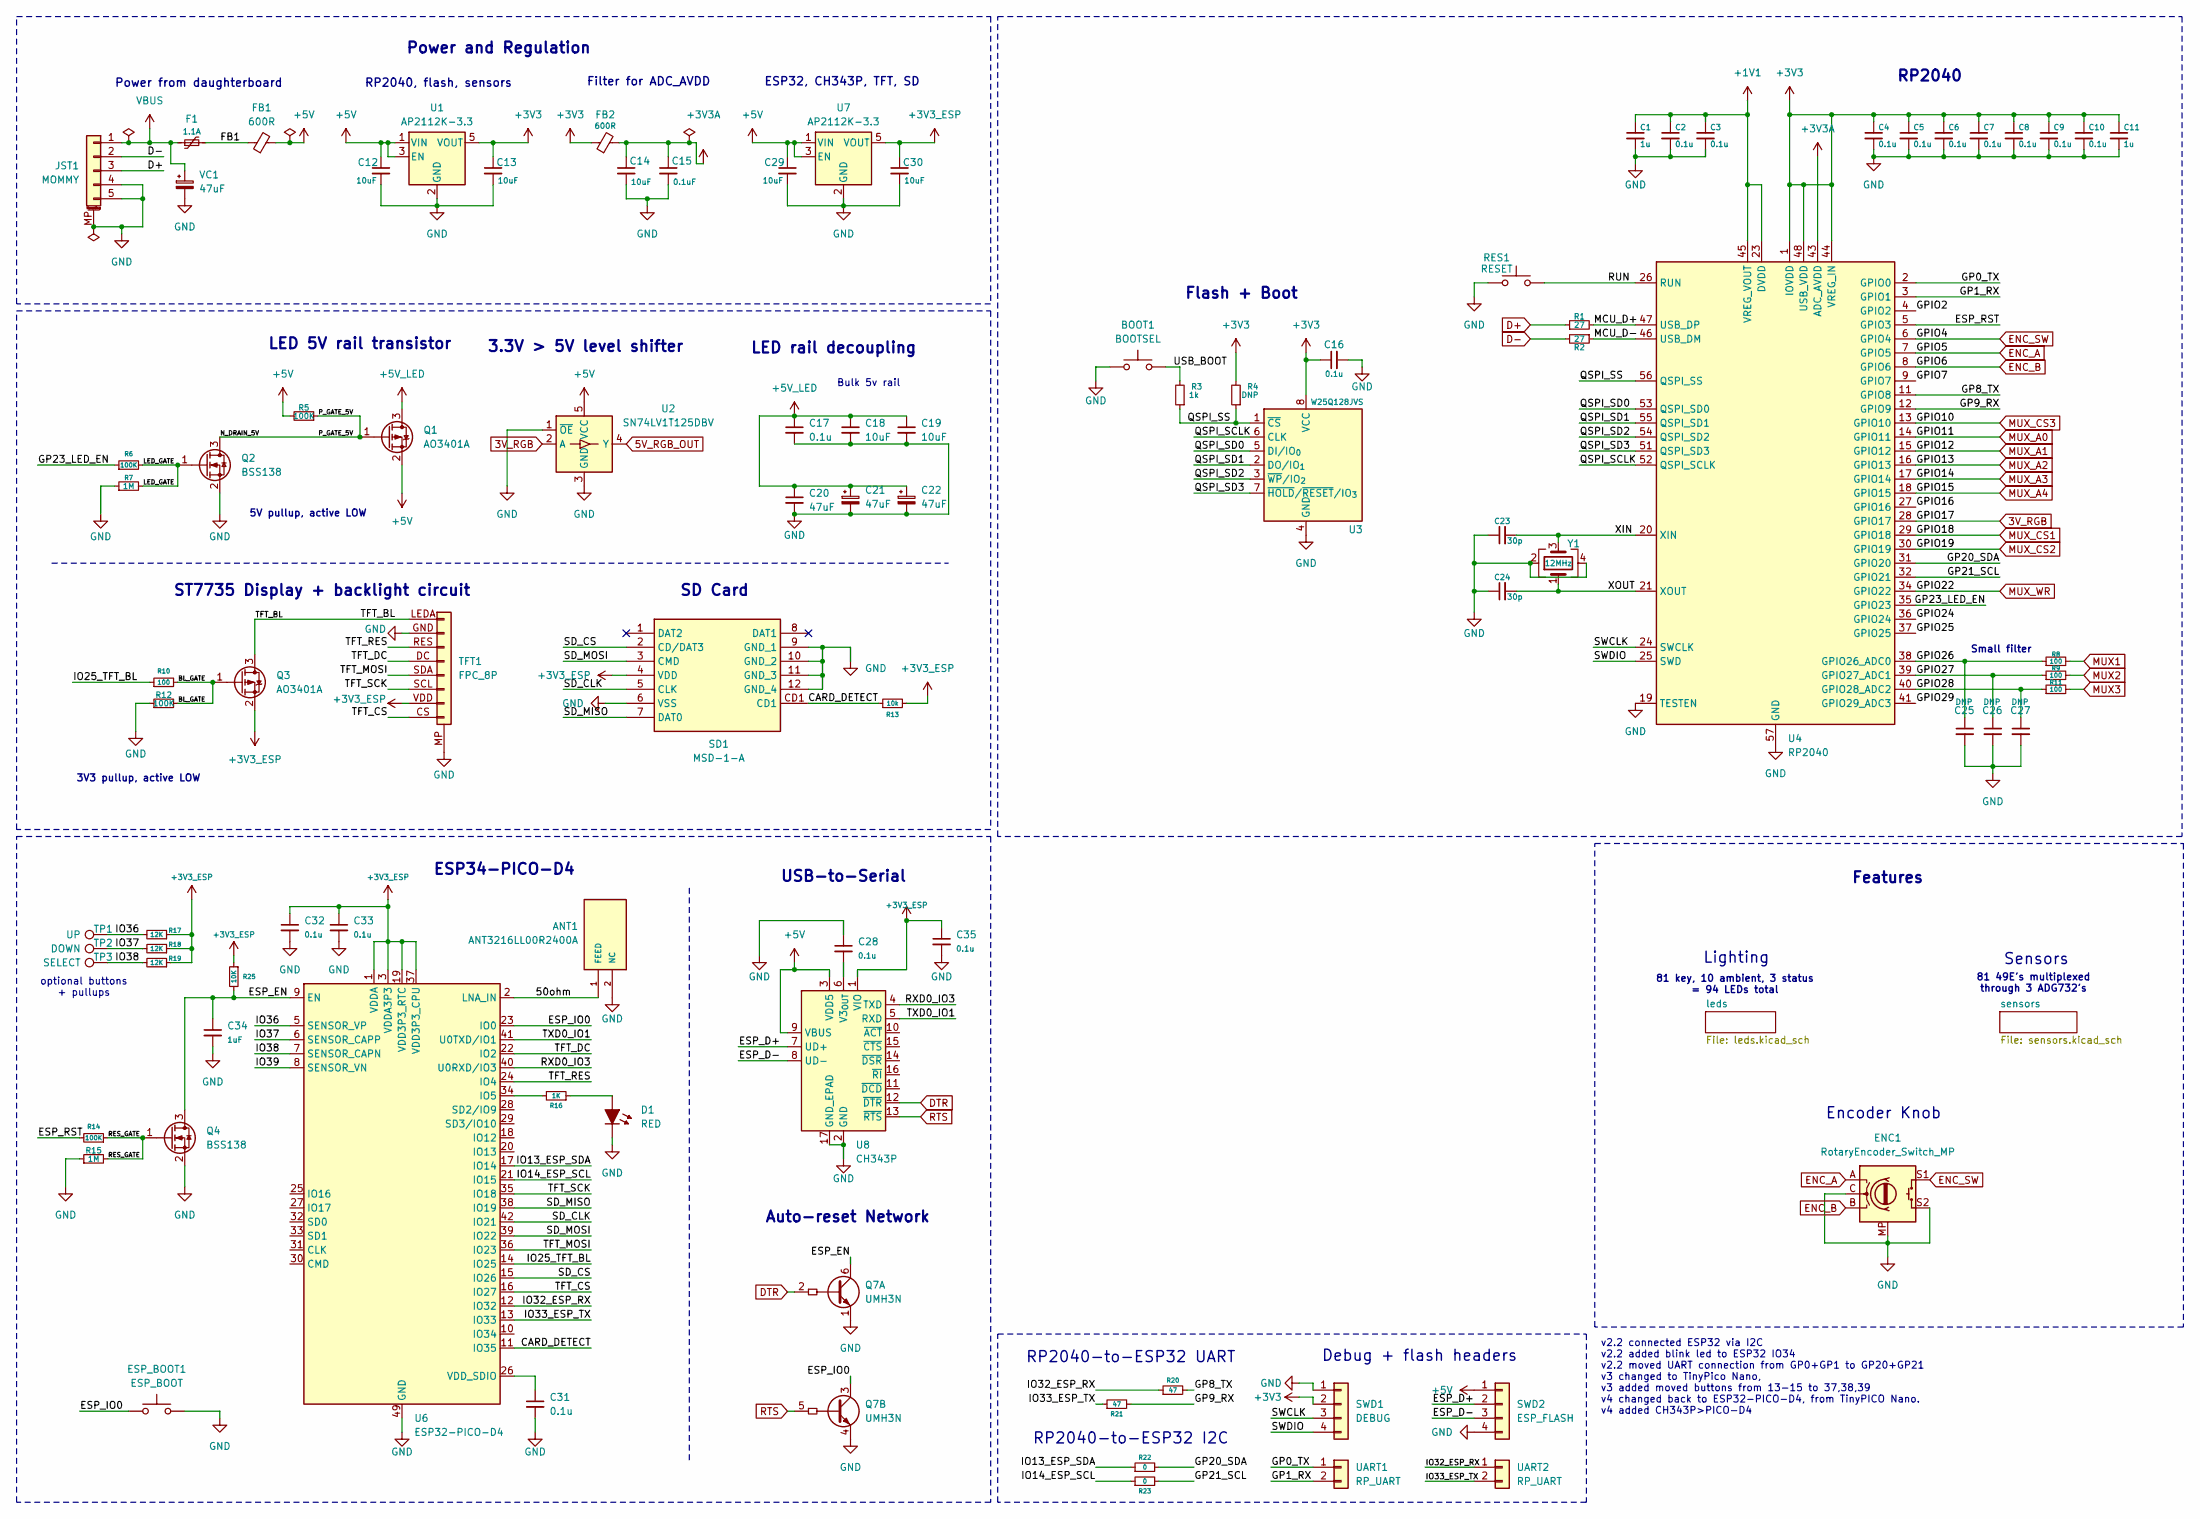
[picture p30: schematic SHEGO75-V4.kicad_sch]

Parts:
ANT1: ANT3216LL00R2400A; ANTC3216X135N; Mouser_Part_Number 603-ANT3216LL00R2400
BOOT1: BOOTSEL; SW_SPST_EVQP2_MiddlePushTravel_H2.5mm
C1, C11: 1u; C_0402
C2, C3, C4, C5, C6, C7, C8, C9, C10, C28, C31, C32, C33, C35: 0.1u; C_0402
C12, C13: 10uF; C_0805
C14, C18, C19, C29, C30: 10uF; C_0603
C15: 0.1uF; C_0603
C16, C17: 0.1u; C_0603
C20: 47uF; C_0805
C21, C22: 47uF; CP_EIA-3216-12_Kemet-S
C23, C24: 30p; C_0603; LCSC C1658
C25, C26, C27: DNP; C_0603
C34: 1uF; C_0402
D1: RED; LED_0402_1005Metric
ENC1: RotaryEncoder_Switch_MP; RotaryEncoder_Alps_EC11E_Vertical_H20mm_CircularMountingHol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
ESP_BOOT1: ESP_BOOT; SW_SPST_EVQP2
F1: 1.1A; Fuse_PPTC_0805
FB1, FB2: 600R; Ferrite_0805
JST1: MOMMY; JST_GH_SM05B-GHS-TB_1x05-1MP_P1.25mm_Horizontal
Q1, Q3: AO3401A; SOT-23
Q2, Q4: BSS138; SOT-23
Q7: UMH3N; SOT-363_SC-70-6
R1, R2: 27; R_0603
R3: 1k; R_0603
R4: DNP; R_0603
R5, R6, R12, R14: 100K; R_0603
R7, R15: 1M; R_0603
R8, R9, R10, R11: 100; R_0603
R13: 10k; R_0603
R16: 1K; R_0402
R17, R18, R19: 12K; R_0402
R20, R21: 47; R_0603
R22, R23: 0; R_0603
R25: 10K; R_0402
RES1: RESET; SW_SPST_EVQP2_MiddlePushTravel_H2.5mm
SD1: MSD-1-A; MSD1A; Manufacturer_Part_Number MSD-1-A; Mouser Part Number 179-MSD-1-A
SWD1: DEBUG; SWD_Debug_PinHeader_1x04_P2.54mm; Part Number 1-0401FBV0T
SWD2: ESP_FLASH; SWD_Debug_PinHeader_1x04_P2.54mm; Part Number 1-0401FBV0T
TFT1: FPC_8P; TFT_FPC_8P_0.5mm
TP1: UP; TestPoint_Pad_04
TP2: DOWN; TestPoint_Pad_04
TP3: SELECT; TestPoint_Pad_04
U1, U7: AP2112K-3.3; SOT-23-5
U2: SN74LV1T125DBV; SOT-23-5
U3: W25Q128JVS; SOIC-8_5.3x5.3mm_P1.27mm
U4: RP2040; QFN-56-1EP_7x7mm_P0.4mm_EP3.2x3.2mm
U6: ESP32-PICO-D4; QFN-48-1EP_7x7mm_P0.5mm_EP5.3x5.3mm
U8: CH343P; WCH_QFN-16-1EP_3x3mm_P0.5mm_EP1.8x1.8mm
UART1, UART2: RP_UART; UART_PinHeader_1x02_P2.54mm
VC1: 47uF; CP_EIA-3216-12_Kemet-S
Y1: 12MHz; Crystal_SMD_3225-4Pin_3.2x2.5mm; LCSC C9002

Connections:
3V_RGB: U2.2 (A), U4.28 (GPIO17)
5V_RGB_OUT: U2.4 (Y); also elsewhere on the board
+1V1: C1.1, C2.1, C3.1, U4.23 (DVDD), U4.45 (VREG_VOUT), U4.50 (DVDD)
+3V3: C4.1, C5.1, C6.1, C7.1, C8.1, C9.1, C10.1, C11.1, C13.1, C16.1, FB2.1, R4.2, SWD1.2, U1.5 (VOUT), U3.8 (VCC), U4.1 (IOVDD), U4.10 (IOVDD), U4.22 (IOVDD), U4.33 (IOVDD), U4.42 (IOVDD), U4.44 (VREG_IN), U4.48 (USB_VDD), U4.49 (IOVDD); also elsewhere on the board
+3V3A: C14.1, C15.1, FB2.2, U4.43 (ADC_AVDD)
+3V3_ESP: C30.1, C32.1, C33.1, C35.1, Q3.2 (S), R13.2, R17.1, R18.1, R19.1, R25.1, SD1.4 (VDD), TFT1.VDD (Pin_7), U6.1 (VDDA), U6.3 (VDDA3P3), U6.4 (VDDA3P3), U6.19 (VDD3P3_RTC), U6.37 (VDD3P3_CPU), U6.43 (VDDA), U6.46 (VDDA), U7.5 (VOUT), U8.1 (VIO)
+5V: C12.1, C29.1, FB1.2, Q1.2 (S), R5.2, SWD2.1, U1.1 (VIN), U1.3 (EN), U2.5 (VCC), U7.1 (VIN), U7.3 (EN), U8.3 (VDD5), U8.9 (VBUS)
+5V_LED: C17.1, C18.1, C19.1, C20.1, C21.1, C22.1, Q1.3 (D); also elsewhere on the board
/50ohm: ANT1.1 (FEED), U6.2 (LNA_IN)
/BL_GATE: Q3.1 (G), R10.2, R12.2
/CARD_DETECT: R13.1, SD1.CD1, U6.11 (IO35)
/ESP_D+: SWD2.2, U8.7 (UD+)
/ESP_D-: SWD2.3, U8.8 (UD-)
/ESP_EN: C34.1, Q4.3 (D), Q7.6 (C1), R25.2, U6.9 (EN)
/ESP_IO0: ESP_BOOT1.1, Q7.3 (C2), U6.23 (IO0)
/ESP_RST: R14.2, U4.5 (GPIO3)
/FB1: F1.2, FB1.1
/GP0_TX: U4.2 (GPIO0), UART1.1
/GP1_RX: U4.3 (GPIO1), UART1.2
/GP8_TX: R20.2, U4.11 (GPIO8)
/GP9_RX: R21.2, U4.12 (GPIO9)
/GP20_SDA: R22.2, U4.31 (GPIO20)
/GP21_SCL: R23.2, U4.32 (GPIO21)
/GP23_LED_EN: R6.1, U4.35 (GPIO23)
/GPIO2: U4.4 (GPIO2)
/GPIO7: U4.9 (GPIO7)
/GPIO16: U4.27 (GPIO16)
/GPIO24: U4.36 (GPIO24)
/GPIO25: U4.37 (GPIO25)
/GPIO26: C25.1, R8.1, U4.38 (GPIO26_ADC0)
/GPIO27: C26.1, R9.1, U4.39 (GPIO27_ADC1)
/GPIO28: C27.1, R11.1, U4.40 (GPIO28_ADC2)
/GPIO29: U4.41 (GPIO29_ADC3)
/IO13_ESP_SDA: R22.1, U6.17 (IO14)
/IO14_ESP_SCL: R23.1, U6.21 (IO15)
/IO25_TFT_BL: R10.1, U6.14 (IO25)
/IO32_ESP_RX: R20.1, U6.12 (IO32), UART2.1
/IO33_ESP_TX: R21.1, U6.13 (IO33), UART2.2
/IO36: R17.2, TP1.1, U6.5 (SENSOR_VP)
/IO37: R18.2, TP2.1, U6.6 (SENSOR_CAPP)
/IO38: R19.2, TP3.1, U6.7 (SENSOR_CAPN)
/IO39: U6.8 (SENSOR_VN)
/LED_GATE: Q2.1 (G), R6.2, R7.2
/MCU_D+: R1.2, U4.47 (USB_DP)
/MCU_D-: R2.1, U4.46 (USB_DM)
/N_DRAIN_5V: Q1.1 (G), Q2.3 (D), R5.1
/QSPI_SCLK: U3.6 (CLK), U4.52 (QSPI_SCLK)
/QSPI_SD0: U3.5 (DI/IO_{0}), U4.53 (QSPI_SD0)
/QSPI_SD1: U3.2 (DO/IO_{1}), U4.55 (QSPI_SD1)
/QSPI_SD2: U3.3 (~WP/IO_{2}), U4.54 (QSPI_SD2)
/QSPI_SD3: U3.7 (~HOLD/~RESET/IO_{3}), U4.51 (QSPI_SD3)
/QSPI_SS: R3.1, R4.1, U3.1 (~CS), U4.56 (QSPI_SS)
/RES_GATE: Q4.1 (G), R14.1, R15.2
/RUN: RES1.2, U4.26 (RUN)
/RXD0_IO3: U6.40 (U0RXD/IO3), U8.4 (TXD)
/SD_CLK: SD1.5 (CLK), U6.42 (IO21)
/SD_CS: SD1.2 (CD/DAT3), U6.15 (IO26)
/SD_MISO: SD1.7 (DAT0), U6.38 (IO19)
/SD_MOSI: SD1.3 (CMD), U6.39 (IO22)
/SWCLK: SWD1.3, U4.24 (SWCLK)
/SWDIO: SWD1.4, U4.25 (SWD)
/TFT_BL: Q3.3 (D), TFT1.LEDA (Pin_1)
/TFT_CS: TFT1.CS (Pin_8), U6.16 (IO27)
/TFT_DC: TFT1.DC (Pin_4), U6.22 (IO2)
/TFT_MOSI: TFT1.SDA (Pin_5), U6.36 (IO23)
/TFT_RES: TFT1.RES (Pin_3), U6.24 (IO4)
/TFT_SCK: TFT1.SCL (Pin_6), U6.35 (IO18)
/TXD0_IO1: U6.41 (U0TXD/IO1), U8.5 (RXD)
/USB_BOOT: BOOT1.2, R3.2
/XIN: C23.2, U4.20 (XIN), Y1.3
/XOUT: C24.2, U4.21 (XOUT), Y1.1
D+: JST1.3, R1.1
D-: JST1.2, R2.2
DTR: Q7.2 (B1), U8.12 (~DTR)
ENC_A: ENC1.A, U4.7 (GPIO5)
ENC_B: ENC1.B, U4.8 (GPIO6)
ENC_SW: ENC1.S1, U4.6 (GPIO4)
GND: ANT1.2 (NC), BOOT1.1, C1.2, C2.2, C3.2, C4.2, C5.2, C6.2, C7.2, C8.2, C9.2, C10.2, C11.2, C12.2, C13.2, C14.2, C15.2, C16.2, C17.2, C18.2, C19.2, C20.2, C21.2, C22.2, C23.1, C24.1, C25.2, C26.2, C27.2, C28.1, C29.2, C30.2, C31.2, C32.2, C33.2, C34.2, C35.2, D1.1 (K), ENC1.C, ENC1.MP, ENC1.S2, ESP_BOOT1.2, JST1.4, JST1.5, JST1.MP (MountPin), Q2.2 (S), Q4.2 (S), Q7.1 (E1), Q7.4 (E2), R7.1, R12.1, R15.1, RES1.1, SD1.6 (VSS), SD1.9 (GND_1), SD1.10 (GND_2), SD1.11 (GND_3), SD1.12 (GND_4), SWD1.1, SWD2.4, TFT1.GND (Pin_2), TFT1.MP (Pin_8), U1.2 (GND), U2.1 (~OE), U2.3 (GND), U3.4 (GND), U4.19 (TESTEN), U4.57 (GND), U6.49 (GND), U7.2 (GND), U8.2 (GND), U8.17 (GND_EPAD), VC1.2, Y1.2, Y1.4; also elsewhere on the board
MUX1: R8.2; also elsewhere on the board
MUX2: R9.2; also elsewhere on the board
MUX3: R11.2; also elsewhere on the board
MUX_A0: U4.14 (GPIO11); also elsewhere on the board
MUX_A1: U4.15 (GPIO12); also elsewhere on the board
MUX_A2: U4.16 (GPIO13); also elsewhere on the board
MUX_A3: U4.17 (GPIO14); also elsewhere on the board
MUX_A4: U4.18 (GPIO15); also elsewhere on the board
MUX_CS1: U4.29 (GPIO18); also elsewhere on the board
MUX_CS2: U4.30 (GPIO19); also elsewhere on the board
MUX_CS3: U4.13 (GPIO10); also elsewhere on the board
MUX_WR: U4.34 (GPIO22); also elsewhere on the board
unnamed: D1.2 (A), R16.1
unnamed: R16.2, U6.34 (IO5)
unnamed: C31.1, U6.26 (VDD_SDIO)
unnamed: C28.2, U8.6 (V3_{OUT})
RTS: Q7.5 (B2), U8.13 (~RTS)
VBUS: F1.1, JST1.1, VC1.1

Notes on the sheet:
optional buttons + pullups
LED 5V rail transistor
USB-to-Serial
Power and Regulation
Filter for ADC_AVDD
Features
Auto-reset Network
Sensors
RP2040, flash, sensors
Small filter
ST7735 Display + backlight circuit
v2.2 connected ESP32 via I2C v2.2 added blink led to ESP32 IO34 v2.2 moved UART connection from GP0+GP1 to GP20+GP21 v3 changed to TinyPico Nano, v3 added moved buttons from 13-15 to 37,38,39 v4 changed back to ESP32-PICO-D4, from TinyPICO Nano. v4 added CH343P>PICO-D4
ESP34-PICO-D4
Debug + flash headers
3.3V > 5V level shifter
3V3 pullup, active LOW
5V pullup, active LOW
Power from daughterboard
SD Card
Lighting
LED rail decoupling
RP2040-to-ESP32 UART
81 49E's multiplexed through 3 ADG732's
Flash + Boot
Encoder Knob
ESP32, CH343P, TFT, SD
81 key, 10 ambient, 3 status = 94 LEDs total
RP2040
RP2040-to-ESP32 I2C
Bulk 5v rail

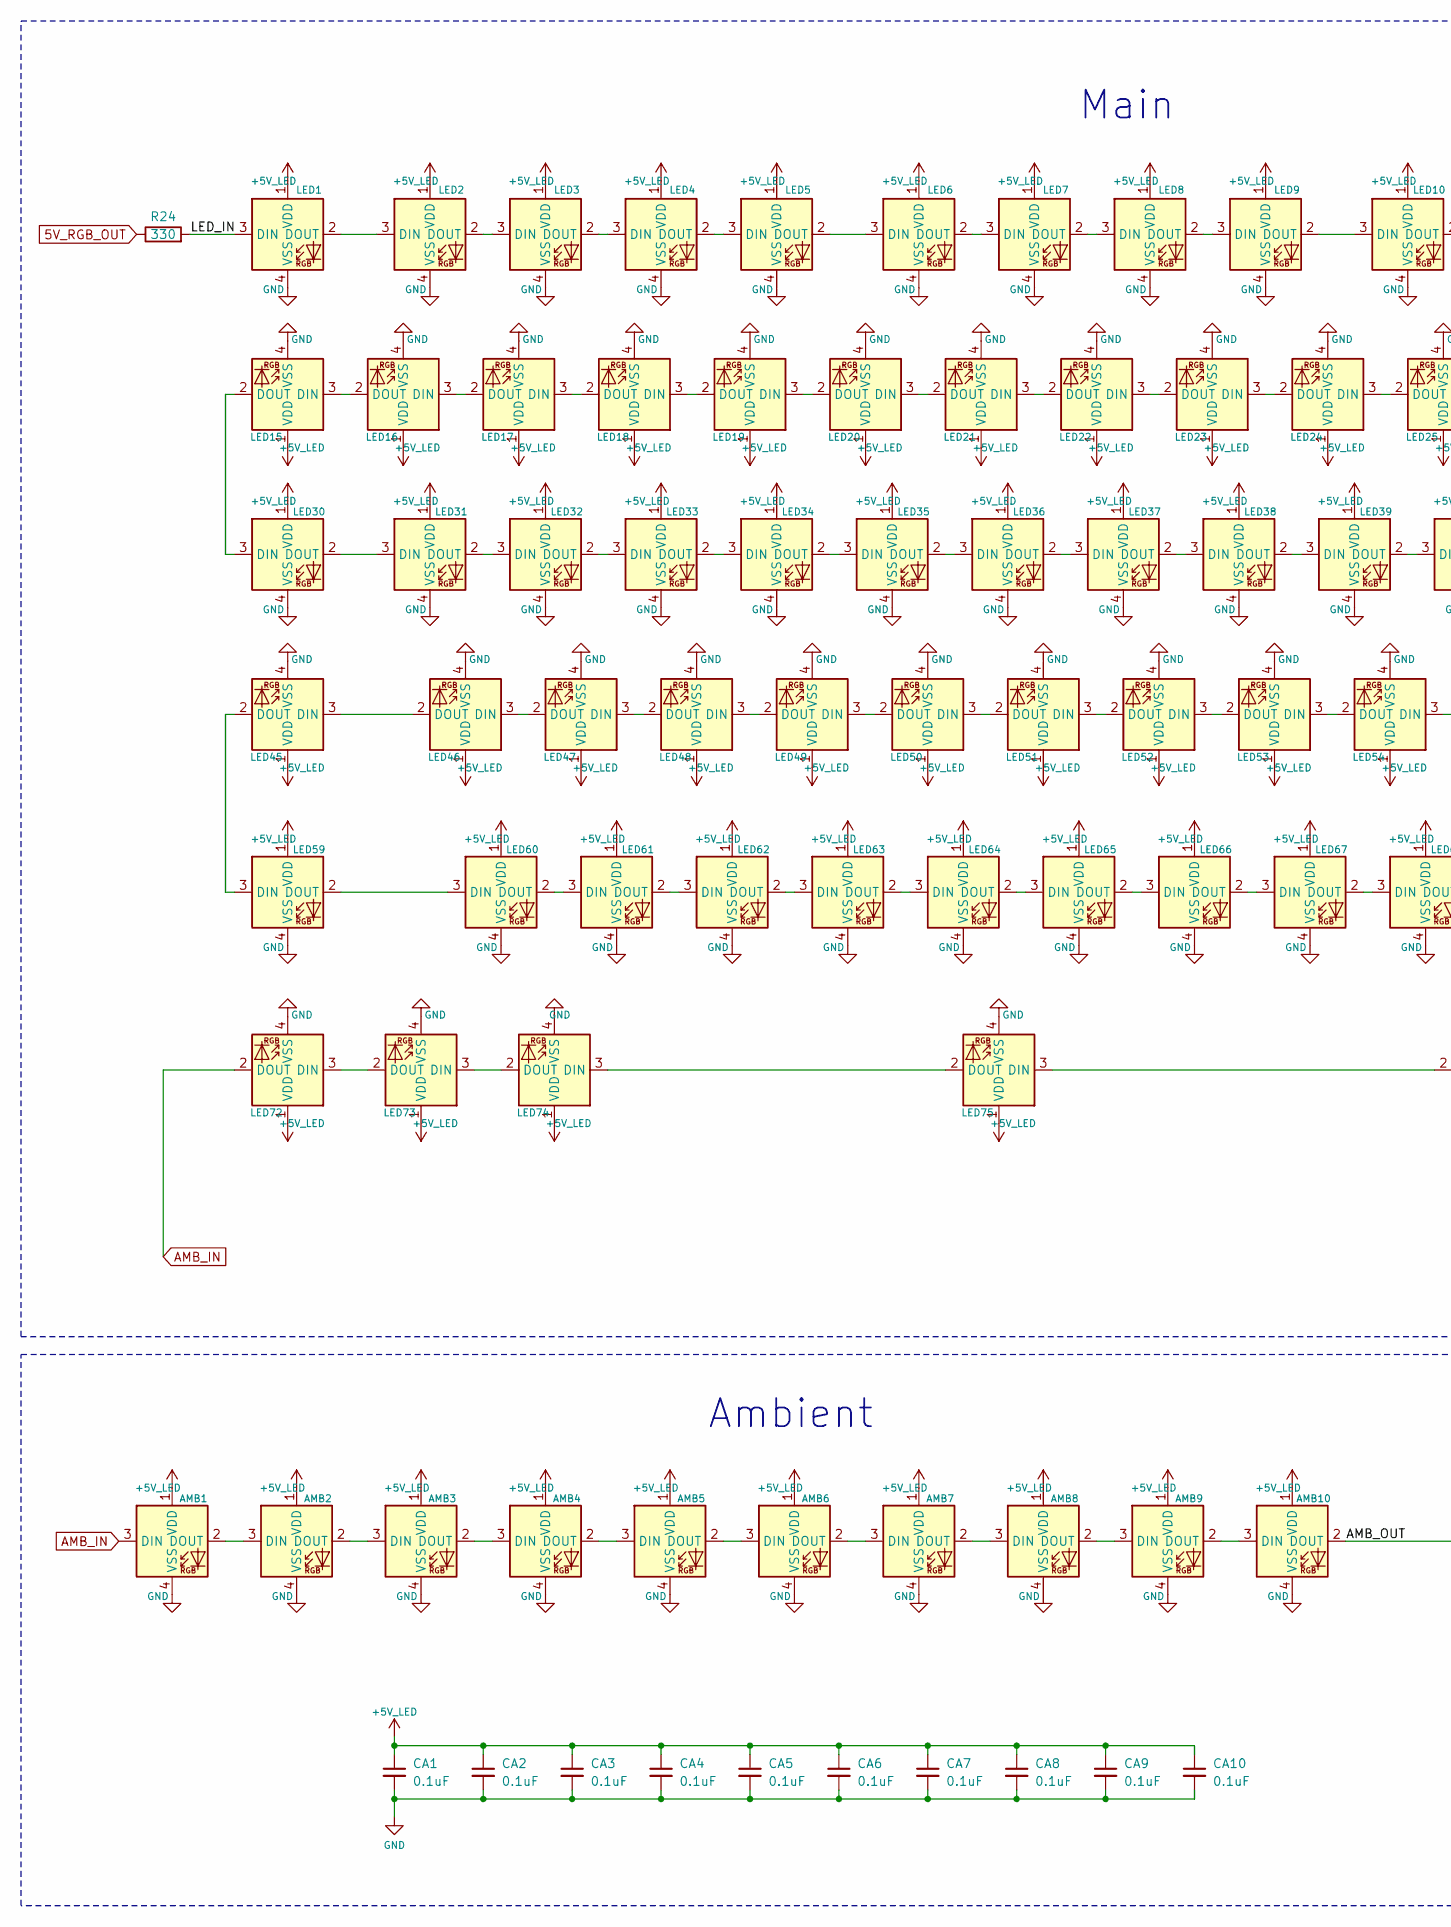
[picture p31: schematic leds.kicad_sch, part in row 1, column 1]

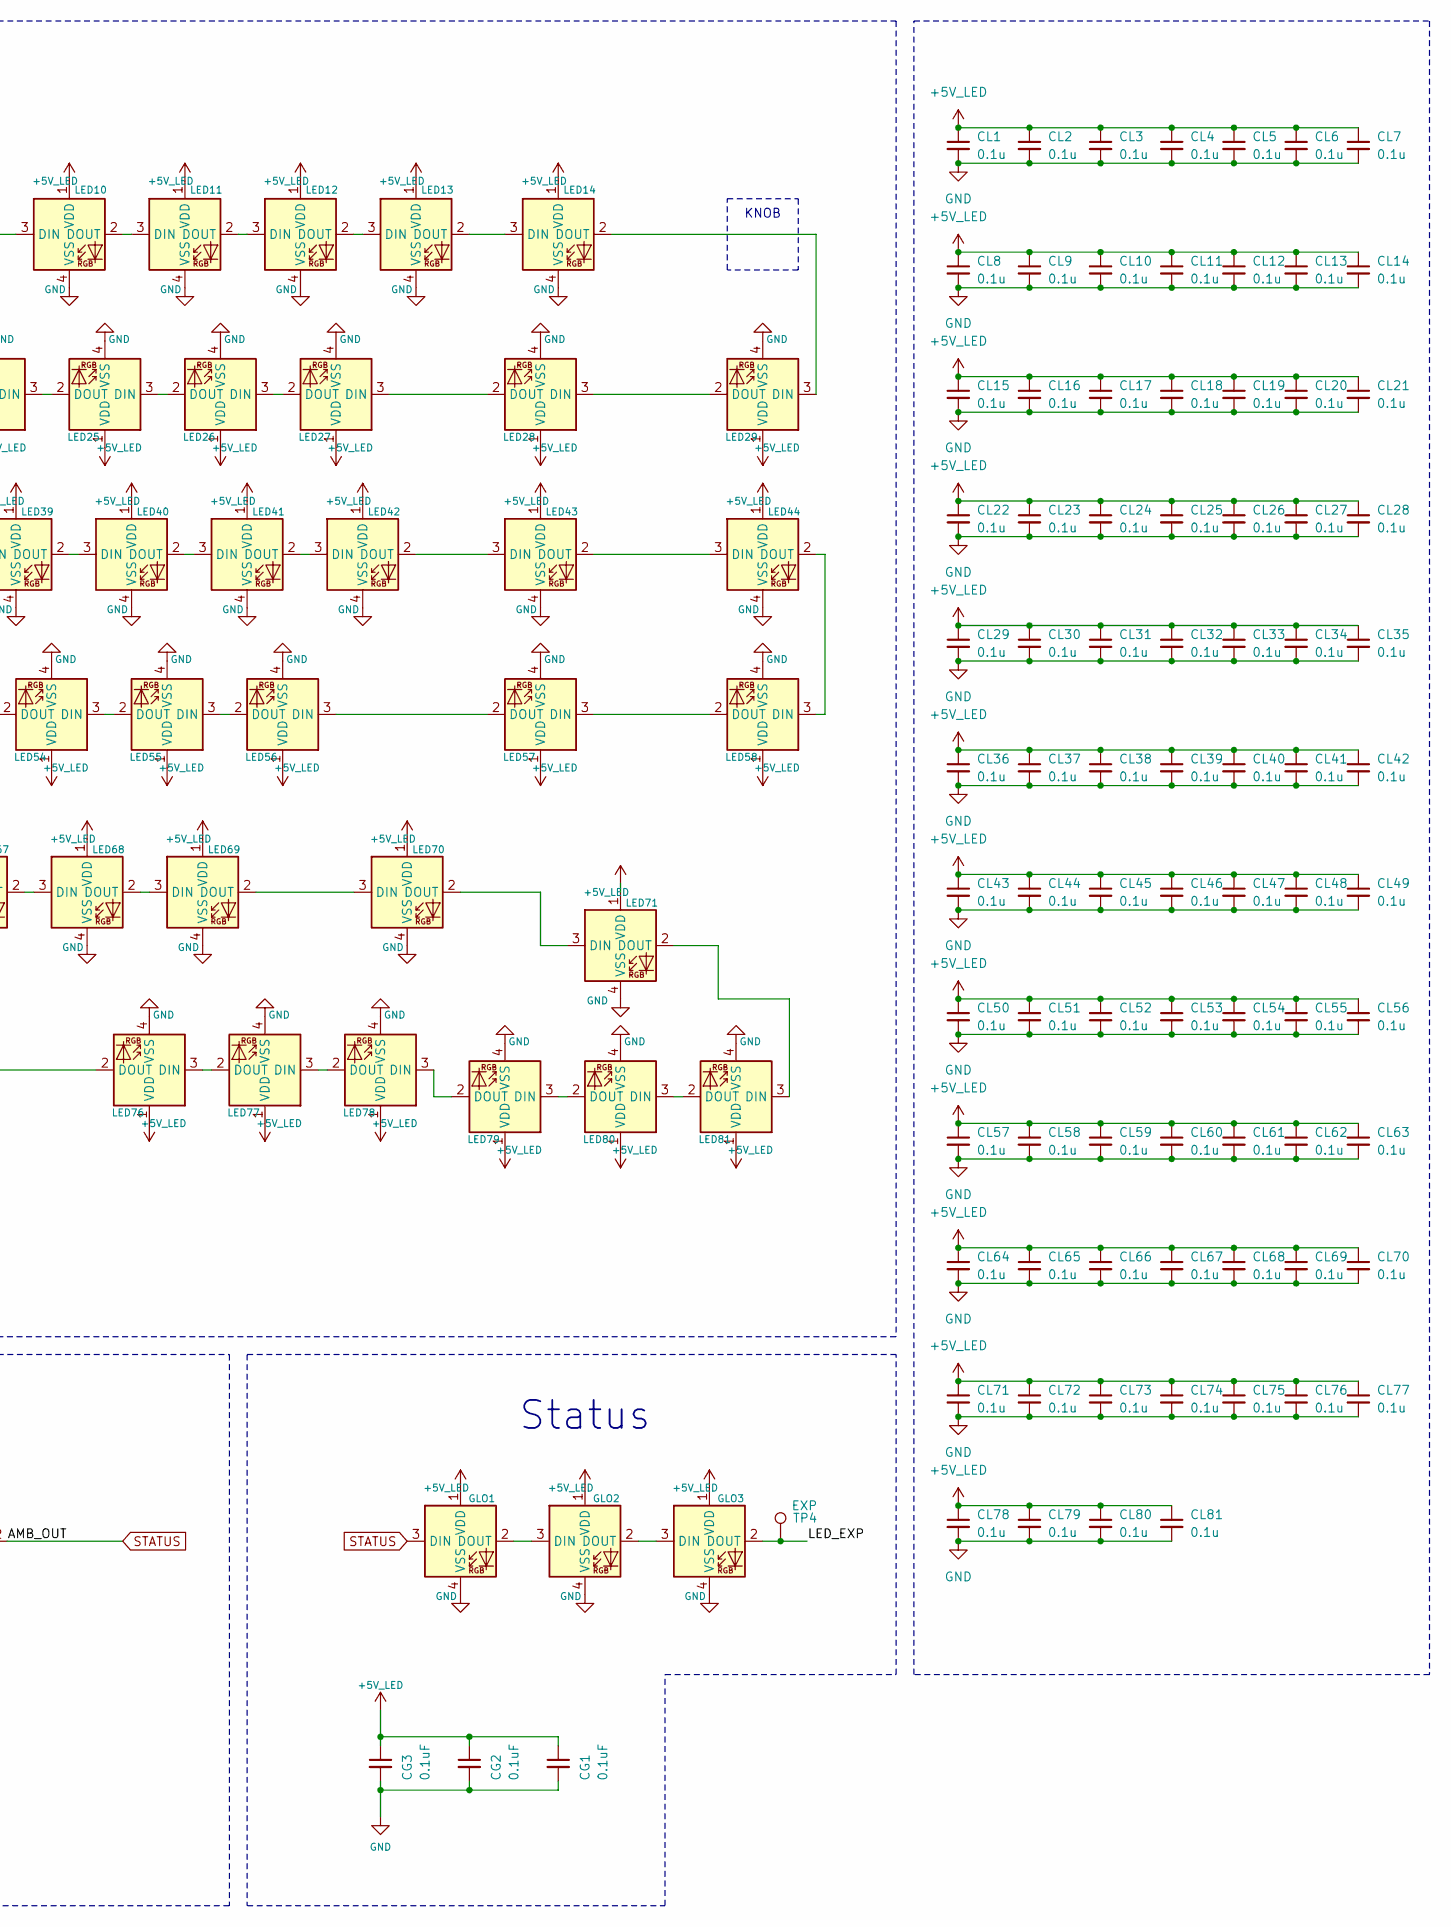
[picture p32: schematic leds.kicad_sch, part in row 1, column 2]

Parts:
AMB1, AMB2, AMB3, AMB4, AMB5, AMB6, AMB7, AMB8, AMB9, AMB10: SK6812; LED_6028R; LCSC C5149201
CA1, CA2, CA3, CA4, CA5, CA6, CA7, CA8, CA9, CA10: 0.1uF; C_0402
CG1, CG2, CG3: 0.1uF; C_0402
CL1, CL2, CL3, CL4, CL5, CL6, CL7, CL8, CL9, CL10, CL11, CL12, CL13, CL14, CL15, CL16, CL17, CL18, CL19, CL20, CL21, CL22, CL23, CL24, CL25, CL26, CL27, CL28, CL29, CL30, CL31, CL32, CL33, CL34, CL35, CL36, CL37, CL38, CL39, CL40, CL41, CL42, CL43, CL44, CL45, CL46, CL47, CL48, CL49, CL50, CL51, CL52, CL53, CL54, CL55, CL56, CL57, CL58, CL59, CL60, CL61, CL62, CL63, CL64, CL65, CL66, CL67, CL68, CL69, CL70, CL71, CL72, CL73, CL74, CL75, CL76, CL77, CL78, CL79, CL80, CL81: 0.1u; C_0603
GLO1, GLO2, GLO3: SK6812; LED_6028R; LCSC C5149201
LED1, LED2, LED3, LED4, LED5, LED6, LED7, LED8, LED9, LED10, LED11, LED12, LED13, LED14, LED15, LED16, LED17, LED18, LED19, LED20, LED21, LED22, LED23, LED24, LED25, LED26, LED27, LED28, LED29, LED30, LED31, LED32, LED33, LED34, LED35, LED36, LED37, LED38, LED39, LED40, LED41, LED42, LED43, LED44, LED45, LED46, LED47, LED48, LED49, LED50, LED51, LED52, LED53, LED54, LED55, LED56, LED57, LED58, LED59, LED60, LED61, LED62, LED63, LED64, LED65, LED66, LED67, LED68, LED69, LED70, LED71, LED72, LED73, LED74, LED75, LED76, LED77, LED78, LED79, LED80, LED81: SK6812; LED_6028R; LCSC C5149201
R24: 330; R_0603
TP4: EXP; TestPoint_Pad_04

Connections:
5V_RGB_OUT: R24.1; also elsewhere on the board
+5V_LED: AMB1.1 (VDD), AMB2.1 (VDD), AMB3.1 (VDD), AMB4.1 (VDD), AMB5.1 (VDD), AMB6.1 (VDD), AMB7.1 (VDD), AMB8.1 (VDD), AMB9.1 (VDD), AMB10.1 (VDD), CA1.1, CA2.1, CA3.1, CA4.1, CA5.1, CA6.1, CA7.1, CA8.1, CA9.1, CA10.1, CG1.1, CG2.1, CG3.1, CL1.1, CL2.1, CL3.1, CL4.1, CL5.1, CL6.1, CL7.1, CL8.1, CL9.1, CL10.1, CL11.1, CL12.1, CL13.1, CL14.1, CL15.1, CL16.1, CL17.1, CL18.1, CL19.1, CL20.1, CL21.1, CL22.1, CL23.1, CL24.1, CL25.1, CL26.1, CL27.1, CL28.1, CL29.1, CL30.1, CL31.1, CL32.1, CL33.1, CL34.1, CL35.1, CL36.1, CL37.1, CL38.1, CL39.1, CL40.1, CL41.1, CL42.1, CL43.1, CL44.1, CL45.1, CL46.1, CL47.1, CL48.1, CL49.1, CL50.1, CL51.1, CL52.1, CL53.1, CL54.1, CL55.1, CL56.1, CL57.1, CL58.1, CL59.1, CL60.1, CL61.1, CL62.1, CL63.1, CL64.1, CL65.1, CL66.1, CL67.1, CL68.1, CL69.1, CL70.1, CL71.1, CL72.1, CL73.1, CL74.1, CL75.1, CL76.1, CL77.1, CL78.1, CL79.1, CL80.1, CL81.1, GLO1.1 (VDD), GLO2.1 (VDD), GLO3.1 (VDD), LED1.1 (VDD), LED2.1 (VDD), LED3.1 (VDD), LED4.1 (VDD), LED5.1 (VDD), LED6.1 (VDD), LED7.1 (VDD), LED8.1 (VDD), LED9.1 (VDD), LED10.1 (VDD), LED11.1 (VDD), LED12.1 (VDD), LED13.1 (VDD), LED14.1 (VDD), LED15.1 (VDD), LED16.1 (VDD), LED17.1 (VDD), LED18.1 (VDD), LED19.1 (VDD), LED20.1 (VDD), LED21.1 (VDD), LED22.1 (VDD), LED23.1 (VDD), LED24.1 (VDD), LED25.1 (VDD), LED26.1 (VDD), LED27.1 (VDD), LED28.1 (VDD), LED29.1 (VDD), LED30.1 (VDD), LED31.1 (VDD), LED32.1 (VDD), LED33.1 (VDD), LED34.1 (VDD), LED35.1 (VDD), LED36.1 (VDD), LED37.1 (VDD), LED38.1 (VDD), LED39.1 (VDD), LED40.1 (VDD), LED41.1 (VDD), LED42.1 (VDD), LED43.1 (VDD), LED44.1 (VDD), LED45.1 (VDD), LED46.1 (VDD), LED47.1 (VDD), LED48.1 (VDD), LED49.1 (VDD), LED50.1 (VDD), LED51.1 (VDD), LED52.1 (VDD), LED53.1 (VDD), LED54.1 (VDD), LED55.1 (VDD), LED56.1 (VDD), LED57.1 (VDD), LED58.1 (VDD), LED59.1 (VDD), LED60.1 (VDD), LED61.1 (VDD), LED62.1 (VDD), LED63.1 (VDD), LED64.1 (VDD), LED65.1 (VDD), LED66.1 (VDD), LED67.1 (VDD), LED68.1 (VDD), LED69.1 (VDD), LED70.1 (VDD), LED71.1 (VDD), LED72.1 (VDD), LED73.1 (VDD), LED74.1 (VDD), LED75.1 (VDD), LED76.1 (VDD), LED77.1 (VDD), LED78.1 (VDD), LED79.1 (VDD), LED80.1 (VDD), LED81.1 (VDD); also elsewhere on the board
/leds/LED_EXP: GLO3.2 (DOUT), TP4.1
/leds/LED_IN: LED1.3 (DIN), R24.2
AMB_IN: AMB1.3 (DIN), LED72.2 (DOUT)
GND: AMB1.4 (VSS), AMB2.4 (VSS), AMB3.4 (VSS), AMB4.4 (VSS), AMB5.4 (VSS), AMB6.4 (VSS), AMB7.4 (VSS), AMB8.4 (VSS), AMB9.4 (VSS), AMB10.4 (VSS), CA1.2, CA2.2, CA3.2, CA4.2, CA5.2, CA6.2, CA7.2, CA8.2, CA9.2, CA10.2, CG1.2, CG2.2, CG3.2, CL1.2, CL2.2, CL3.2, CL4.2, CL5.2, CL6.2, CL7.2, CL8.2, CL9.2, CL10.2, CL11.2, CL12.2, CL13.2, CL14.2, CL15.2, CL16.2, CL17.2, CL18.2, CL19.2, CL20.2, CL21.2, CL22.2, CL23.2, CL24.2, CL25.2, CL26.2, CL27.2, CL28.2, CL29.2, CL30.2, CL31.2, CL32.2, CL33.2, CL34.2, CL35.2, CL36.2, CL37.2, CL38.2, CL39.2, CL40.2, CL41.2, CL42.2, CL43.2, CL44.2, CL45.2, CL46.2, CL47.2, CL48.2, CL49.2, CL50.2, CL51.2, CL52.2, CL53.2, CL54.2, CL55.2, CL56.2, CL57.2, CL58.2, CL59.2, CL60.2, CL61.2, CL62.2, CL63.2, CL64.2, CL65.2, CL66.2, CL67.2, CL68.2, CL69.2, CL70.2, CL71.2, CL72.2, CL73.2, CL74.2, CL75.2, CL76.2, CL77.2, CL78.2, CL79.2, CL80.2, CL81.2, GLO1.4 (VSS), GLO2.4 (VSS), GLO3.4 (VSS), LED1.4 (VSS), LED2.4 (VSS), LED3.4 (VSS), LED4.4 (VSS), LED5.4 (VSS), LED6.4 (VSS), LED7.4 (VSS), LED8.4 (VSS), LED9.4 (VSS), LED10.4 (VSS), LED11.4 (VSS), LED12.4 (VSS), LED13.4 (VSS), LED14.4 (VSS), LED15.4 (VSS), LED16.4 (VSS), LED17.4 (VSS), LED18.4 (VSS), LED19.4 (VSS), LED20.4 (VSS), LED21.4 (VSS), LED22.4 (VSS), LED23.4 (VSS), LED24.4 (VSS), LED25.4 (VSS), LED26.4 (VSS), LED27.4 (VSS), LED28.4 (VSS), LED29.4 (VSS), LED30.4 (VSS), LED31.4 (VSS), LED32.4 (VSS), LED33.4 (VSS), LED34.4 (VSS), LED35.4 (VSS), LED36.4 (VSS), LED37.4 (VSS), LED38.4 (VSS), LED39.4 (VSS), LED40.4 (VSS), LED41.4 (VSS), LED42.4 (VSS), LED43.4 (VSS), LED44.4 (VSS), LED45.4 (VSS), LED46.4 (VSS), LED47.4 (VSS), LED48.4 (VSS), LED49.4 (VSS), LED50.4 (VSS), LED51.4 (VSS), LED52.4 (VSS), LED53.4 (VSS), LED54.4 (VSS), LED55.4 (VSS), LED56.4 (VSS), LED57.4 (VSS), LED58.4 (VSS), LED59.4 (VSS), LED60.4 (VSS), LED61.4 (VSS), LED62.4 (VSS), LED63.4 (VSS), LED64.4 (VSS), LED65.4 (VSS), LED66.4 (VSS), LED67.4 (VSS), LED68.4 (VSS), LED69.4 (VSS), LED70.4 (VSS), LED71.4 (VSS), LED72.4 (VSS), LED73.4 (VSS), LED74.4 (VSS), LED75.4 (VSS), LED76.4 (VSS), LED77.4 (VSS), LED78.4 (VSS), LED79.4 (VSS), LED80.4 (VSS), LED81.4 (VSS); also elsewhere on the board
unnamed: AMB1.2 (DOUT), AMB2.3 (DIN)
unnamed: AMB2.2 (DOUT), AMB3.3 (DIN)
unnamed: AMB3.2 (DOUT), AMB4.3 (DIN)
unnamed: AMB4.2 (DOUT), AMB5.3 (DIN)
unnamed: AMB5.2 (DOUT), AMB6.3 (DIN)
unnamed: AMB6.2 (DOUT), AMB7.3 (DIN)
unnamed: AMB7.2 (DOUT), AMB8.3 (DIN)
unnamed: AMB8.2 (DOUT), AMB9.3 (DIN)
unnamed: AMB9.2 (DOUT), AMB10.3 (DIN)
unnamed: GLO1.2 (DOUT), GLO2.3 (DIN)
unnamed: GLO2.2 (DOUT), GLO3.3 (DIN)
unnamed: LED1.2 (DOUT), LED2.3 (DIN)
unnamed: LED2.2 (DOUT), LED3.3 (DIN)
unnamed: LED3.2 (DOUT), LED4.3 (DIN)
unnamed: LED4.2 (DOUT), LED5.3 (DIN)
unnamed: LED5.2 (DOUT), LED6.3 (DIN)
unnamed: LED6.2 (DOUT), LED7.3 (DIN)
unnamed: LED7.2 (DOUT), LED8.3 (DIN)
unnamed: LED8.2 (DOUT), LED9.3 (DIN)
unnamed: LED9.2 (DOUT), LED10.3 (DIN)
unnamed: LED10.2 (DOUT), LED11.3 (DIN)
unnamed: LED11.2 (DOUT), LED12.3 (DIN)
unnamed: LED12.2 (DOUT), LED13.3 (DIN)
unnamed: LED13.2 (DOUT), LED14.3 (DIN)
unnamed: LED14.2 (DOUT), LED29.3 (DIN)
unnamed: LED15.3 (DIN), LED16.2 (DOUT)
unnamed: LED15.2 (DOUT), LED30.3 (DIN)
unnamed: LED16.3 (DIN), LED17.2 (DOUT)
unnamed: LED17.3 (DIN), LED18.2 (DOUT)
unnamed: LED18.3 (DIN), LED19.2 (DOUT)
unnamed: LED19.3 (DIN), LED20.2 (DOUT)
unnamed: LED20.3 (DIN), LED21.2 (DOUT)
unnamed: LED21.3 (DIN), LED22.2 (DOUT)
unnamed: LED22.3 (DIN), LED23.2 (DOUT)
unnamed: LED23.3 (DIN), LED24.2 (DOUT)
unnamed: LED24.3 (DIN), LED25.2 (DOUT)
unnamed: LED25.3 (DIN), LED26.2 (DOUT)
unnamed: LED26.3 (DIN), LED27.2 (DOUT)
unnamed: LED27.3 (DIN), LED28.2 (DOUT)
unnamed: LED28.3 (DIN), LED29.2 (DOUT)
unnamed: LED30.2 (DOUT), LED31.3 (DIN)
unnamed: LED31.2 (DOUT), LED32.3 (DIN)
unnamed: LED32.2 (DOUT), LED33.3 (DIN)
unnamed: LED33.2 (DOUT), LED34.3 (DIN)
unnamed: LED34.2 (DOUT), LED35.3 (DIN)
unnamed: LED35.2 (DOUT), LED36.3 (DIN)
unnamed: LED36.2 (DOUT), LED37.3 (DIN)
unnamed: LED37.2 (DOUT), LED38.3 (DIN)
unnamed: LED38.2 (DOUT), LED39.3 (DIN)
unnamed: LED39.2 (DOUT), LED40.3 (DIN)
unnamed: LED40.2 (DOUT), LED41.3 (DIN)
unnamed: LED41.2 (DOUT), LED42.3 (DIN)
unnamed: LED42.2 (DOUT), LED43.3 (DIN)
unnamed: LED43.2 (DOUT), LED44.3 (DIN)
unnamed: LED44.2 (DOUT), LED58.3 (DIN)
unnamed: LED45.3 (DIN), LED46.2 (DOUT)
unnamed: LED45.2 (DOUT), LED59.3 (DIN)
unnamed: LED46.3 (DIN), LED47.2 (DOUT)
unnamed: LED47.3 (DIN), LED48.2 (DOUT)
unnamed: LED48.3 (DIN), LED49.2 (DOUT)
unnamed: LED49.3 (DIN), LED50.2 (DOUT)
unnamed: LED50.3 (DIN), LED51.2 (DOUT)
unnamed: LED51.3 (DIN), LED52.2 (DOUT)
unnamed: LED52.3 (DIN), LED53.2 (DOUT)
unnamed: LED53.3 (DIN), LED54.2 (DOUT)
unnamed: LED54.3 (DIN), LED55.2 (DOUT)
unnamed: LED55.3 (DIN), LED56.2 (DOUT)
unnamed: LED56.3 (DIN), LED57.2 (DOUT)
unnamed: LED57.3 (DIN), LED58.2 (DOUT)
unnamed: LED59.2 (DOUT), LED60.3 (DIN)
unnamed: LED60.2 (DOUT), LED61.3 (DIN)
unnamed: LED61.2 (DOUT), LED62.3 (DIN)
unnamed: LED62.2 (DOUT), LED63.3 (DIN)
unnamed: LED63.2 (DOUT), LED64.3 (DIN)
unnamed: LED64.2 (DOUT), LED65.3 (DIN)
unnamed: LED65.2 (DOUT), LED66.3 (DIN)
unnamed: LED66.2 (DOUT), LED67.3 (DIN)
unnamed: LED67.2 (DOUT), LED68.3 (DIN)
unnamed: LED68.2 (DOUT), LED69.3 (DIN)
unnamed: LED69.2 (DOUT), LED70.3 (DIN)
unnamed: LED70.2 (DOUT), LED71.3 (DIN)
unnamed: LED71.2 (DOUT), LED81.3 (DIN)
unnamed: LED72.3 (DIN), LED73.2 (DOUT)
unnamed: LED73.3 (DIN), LED74.2 (DOUT)
unnamed: LED74.3 (DIN), LED75.2 (DOUT)
unnamed: LED75.3 (DIN), LED76.2 (DOUT)
unnamed: LED76.3 (DIN), LED77.2 (DOUT)
unnamed: LED77.3 (DIN), LED78.2 (DOUT)
unnamed: LED78.3 (DIN), LED79.2 (DOUT)
unnamed: LED79.3 (DIN), LED80.2 (DOUT)
unnamed: LED80.3 (DIN), LED81.2 (DOUT)
STATUS: AMB10.2 (DOUT), GLO1.3 (DIN)

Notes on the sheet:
Status
Main
KNOB
Ambient

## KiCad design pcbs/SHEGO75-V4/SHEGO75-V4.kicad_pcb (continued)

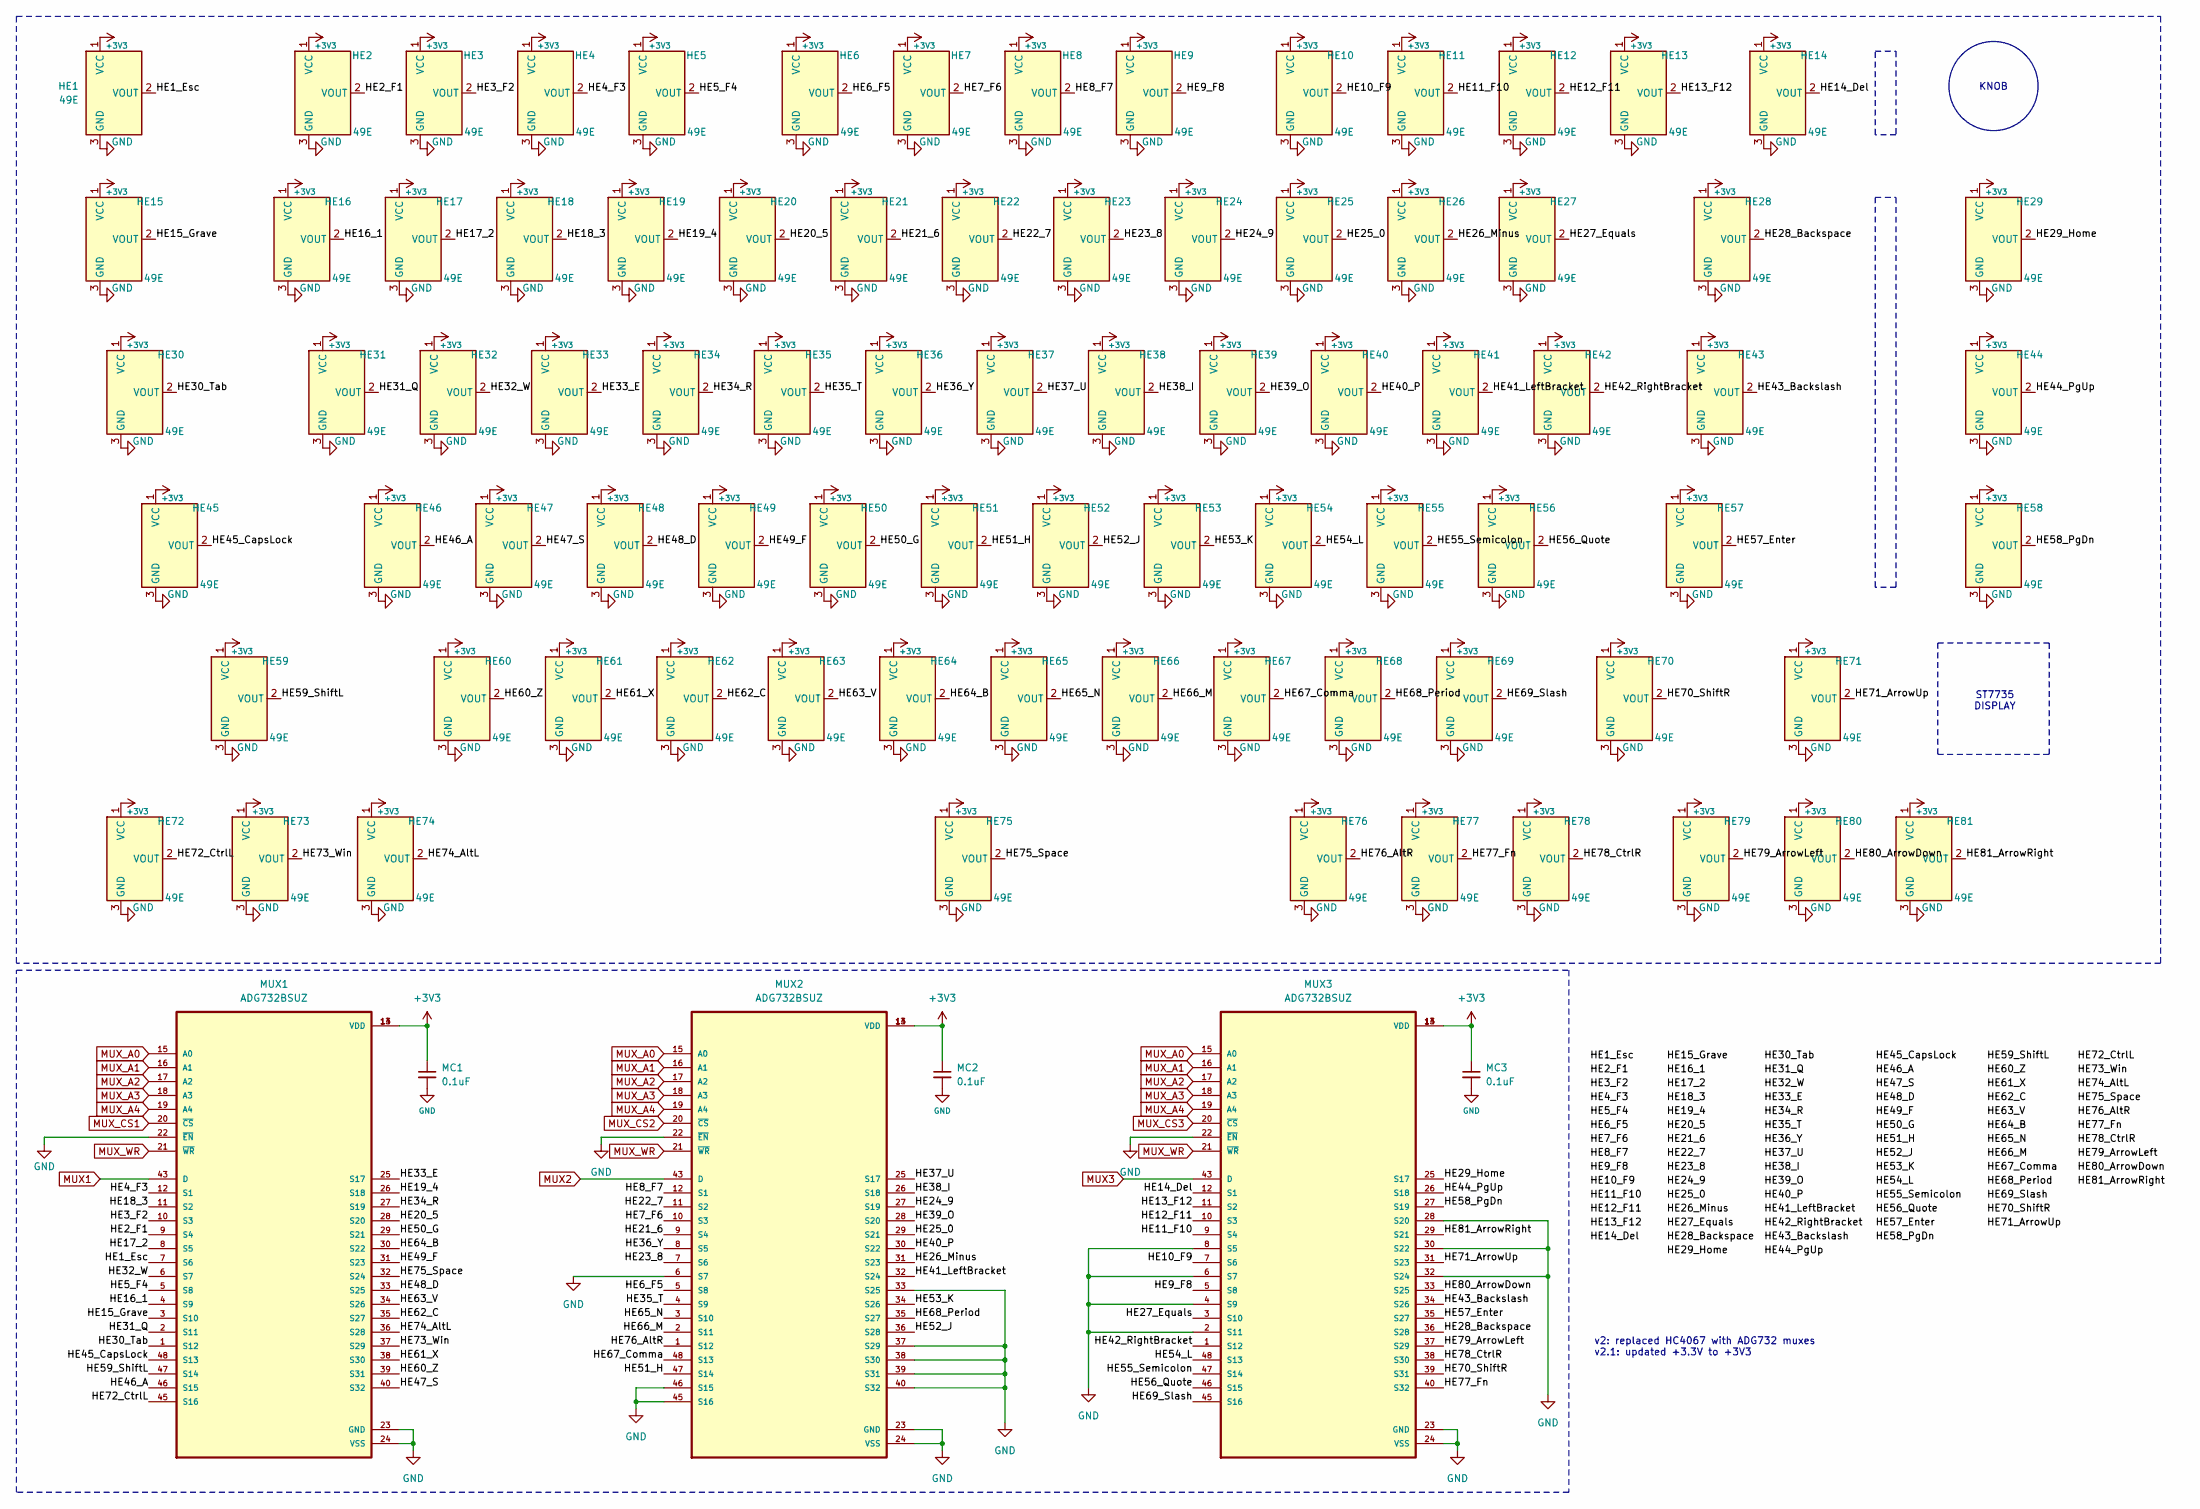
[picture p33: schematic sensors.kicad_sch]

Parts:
HE1, HE2, HE3, HE4, HE5, HE6, HE7, HE8, HE9, HE10, HE11, HE12, HE13, HE14, HE15, HE16, HE17, HE18, HE19, HE20, HE21, HE22, HE23, HE24, HE25, HE26, HE27, HE29, HE31, HE32, HE33, HE34, HE35, HE36, HE37, HE38, HE39, HE40, HE41, HE42, HE44, HE46, HE47, HE48, HE49, HE50, HE51, HE52, HE53, HE54, HE55, HE56, HE58, HE60, HE61, HE62, HE63, HE64, HE65, HE66, HE67, HE68, HE69, HE71, HE76, HE77, HE78, HE79, HE80, HE81: 49E; SW_MX_HE_90deg_1u_Rules; LCSC C7420984
HE28: 49E; SW_MX_HE_90deg_2.00u_Rules; LCSC C7420984
HE30, HE43: 49E; SW_MX_HE_90deg_1.5u_Rules; LCSC C7420984
HE45, HE70: 49E; SW_MX_HE_90deg_1.75u_Rules; LCSC C7420984
HE57, HE59: 49E; SW_MX_HE_90deg_2.25u_Rules; LCSC C7420984
HE72, HE73, HE74: 49E; SW_MX_HE_90deg_1.25u_Rules; LCSC C7420984
HE75: 49E; SW_MX_HE_90deg_6.25u_Rules; LCSC C7420984
MC1, MC2, MC3: 0.1uF; C_0402
MUX1, MUX2, MUX3: ADG732BSUZ; TQFP-48_7x7mm_P0.5mm; LCSC C114845

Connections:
+3V3: HE1.1 (VCC), HE2.1 (VCC), HE3.1 (VCC), HE4.1 (VCC), HE5.1 (VCC), HE6.1 (VCC), HE7.1 (VCC), HE8.1 (VCC), HE9.1 (VCC), HE10.1 (VCC), HE11.1 (VCC), HE12.1 (VCC), HE13.1 (VCC), HE14.1 (VCC), HE15.1 (VCC), HE16.1 (VCC), HE17.1 (VCC), HE18.1 (VCC), HE19.1 (VCC), HE20.1 (VCC), HE21.1 (VCC), HE22.1 (VCC), HE23.1 (VCC), HE24.1 (VCC), HE25.1 (VCC), HE26.1 (VCC), HE27.1 (VCC), HE28.1 (VCC), HE29.1 (VCC), HE30.1 (VCC), HE31.1 (VCC), HE32.1 (VCC), HE33.1 (VCC), HE34.1 (VCC), HE35.1 (VCC), HE36.1 (VCC), HE37.1 (VCC), HE38.1 (VCC), HE39.1 (VCC), HE40.1 (VCC), HE41.1 (VCC), HE42.1 (VCC), HE43.1 (VCC), HE44.1 (VCC), HE45.1 (VCC), HE46.1 (VCC), HE47.1 (VCC), HE48.1 (VCC), HE49.1 (VCC), HE50.1 (VCC), HE51.1 (VCC), HE52.1 (VCC), HE53.1 (VCC), HE54.1 (VCC), HE55.1 (VCC), HE56.1 (VCC), HE57.1 (VCC), HE58.1 (VCC), HE59.1 (VCC), HE60.1 (VCC), HE61.1 (VCC), HE62.1 (VCC), HE63.1 (VCC), HE64.1 (VCC), HE65.1 (VCC), HE66.1 (VCC), HE67.1 (VCC), HE68.1 (VCC), HE69.1 (VCC), HE70.1 (VCC), HE71.1 (VCC), HE72.1 (VCC), HE73.1 (VCC), HE74.1 (VCC), HE75.1 (VCC), HE76.1 (VCC), HE77.1 (VCC), HE78.1 (VCC), HE79.1 (VCC), HE80.1 (VCC), HE81.1 (VCC), MC1.1, MC2.1, MC3.1, MUX1.13 (VDD), MUX1.14 (VDD), MUX2.13 (VDD), MUX2.14 (VDD), MUX3.13 (VDD), MUX3.14 (VDD); also elsewhere on the board
/sensors/HE1_Esc: HE1.2 (VOUT), MUX1.7 (S6)
/sensors/HE2_F1: HE2.2 (VOUT), MUX1.9 (S4)
/sensors/HE3_F2: HE3.2 (VOUT), MUX1.10 (S3)
/sensors/HE4_F3: HE4.2 (VOUT), MUX1.12 (S1)
/sensors/HE5_F4: HE5.2 (VOUT), MUX1.5 (S8)
/sensors/HE6_F5: HE6.2 (VOUT), MUX2.5 (S8)
/sensors/HE7_F6: HE7.2 (VOUT), MUX2.10 (S3)
/sensors/HE8_F7: HE8.2 (VOUT), MUX2.12 (S1)
/sensors/HE9_F8: HE9.2 (VOUT), MUX3.5 (S8)
/sensors/HE10_F9: HE10.2 (VOUT), MUX3.7 (S6)
/sensors/HE11_F10: HE11.2 (VOUT), MUX3.9 (S4)
/sensors/HE12_F11: HE12.2 (VOUT), MUX3.10 (S3)
/sensors/HE13_F12: HE13.2 (VOUT), MUX3.11 (S2)
/sensors/HE14_Del: HE14.2 (VOUT), MUX3.12 (S1)
/sensors/HE15_Grave: HE15.2 (VOUT), MUX1.3 (S10)
/sensors/HE16_1: HE16.2 (VOUT), MUX1.4 (S9)
/sensors/HE17_2: HE17.2 (VOUT), MUX1.8 (S5)
/sensors/HE18_3: HE18.2 (VOUT), MUX1.11 (S2)
/sensors/HE19_4: HE19.2 (VOUT), MUX1.26 (S18)
/sensors/HE20_5: HE20.2 (VOUT), MUX1.28 (S20)
/sensors/HE21_6: HE21.2 (VOUT), MUX2.9 (S4)
/sensors/HE22_7: HE22.2 (VOUT), MUX2.11 (S2)
/sensors/HE23_8: HE23.2 (VOUT), MUX2.7 (S6)
/sensors/HE24_9: HE24.2 (VOUT), MUX2.27 (S19)
/sensors/HE25_0: HE25.2 (VOUT), MUX2.29 (S21)
/sensors/HE26_Minus: HE26.2 (VOUT), MUX2.31 (S23)
/sensors/HE27_Equals: HE27.2 (VOUT), MUX3.3 (S10)
/sensors/HE28_Backspace: HE28.2 (VOUT), MUX3.36 (S28)
/sensors/HE29_Home: HE29.2 (VOUT), MUX3.25 (S17)
/sensors/HE30_Tab: HE30.2 (VOUT), MUX1.1 (S12)
/sensors/HE31_Q: HE31.2 (VOUT), MUX1.2 (S11)
/sensors/HE32_W: HE32.2 (VOUT), MUX1.6 (S7)
/sensors/HE33_E: HE33.2 (VOUT), MUX1.25 (S17)
/sensors/HE34_R: HE34.2 (VOUT), MUX1.27 (S19)
/sensors/HE35_T: HE35.2 (VOUT), MUX2.4 (S9)
/sensors/HE36_Y: HE36.2 (VOUT), MUX2.8 (S5)
/sensors/HE37_U: HE37.2 (VOUT), MUX2.25 (S17)
/sensors/HE38_I: HE38.2 (VOUT), MUX2.26 (S18)
/sensors/HE39_O: HE39.2 (VOUT), MUX2.28 (S20)
/sensors/HE40_P: HE40.2 (VOUT), MUX2.30 (S22)
/sensors/HE41_LeftBracket: HE41.2 (VOUT), MUX2.32 (S24)
/sensors/HE42_RightBracket: HE42.2 (VOUT), MUX3.1 (S12)
/sensors/HE43_Backslash: HE43.2 (VOUT), MUX3.34 (S26)
/sensors/HE44_PgUp: HE44.2 (VOUT), MUX3.26 (S18)
/sensors/HE45_CapsLock: HE45.2 (VOUT), MUX1.48 (S13)
/sensors/HE46_A: HE46.2 (VOUT), MUX1.46 (S15)
/sensors/HE47_S: HE47.2 (VOUT), MUX1.40 (S32)
/sensors/HE48_D: HE48.2 (VOUT), MUX1.33 (S25)
/sensors/HE49_F: HE49.2 (VOUT), MUX1.31 (S23)
/sensors/HE50_G: HE50.2 (VOUT), MUX1.29 (S21)
/sensors/HE51_H: HE51.2 (VOUT), MUX2.47 (S14)
/sensors/HE52_J: HE52.2 (VOUT), MUX2.36 (S28)
/sensors/HE53_K: HE53.2 (VOUT), MUX2.34 (S26)
/sensors/HE54_L: HE54.2 (VOUT), MUX3.48 (S13)
/sensors/HE55_Semicolon: HE55.2 (VOUT), MUX3.47 (S14)
/sensors/HE56_Quote: HE56.2 (VOUT), MUX3.46 (S15)
/sensors/HE57_Enter: HE57.2 (VOUT), MUX3.35 (S27)
/sensors/HE58_PgDn: HE58.2 (VOUT), MUX3.27 (S19)
/sensors/HE59_ShiftL: HE59.2 (VOUT), MUX1.47 (S14)
/sensors/HE60_Z: HE60.2 (VOUT), MUX1.39 (S31)
/sensors/HE61_X: HE61.2 (VOUT), MUX1.38 (S30)
/sensors/HE62_C: HE62.2 (VOUT), MUX1.35 (S27)
/sensors/HE63_V: HE63.2 (VOUT), MUX1.34 (S26)
/sensors/HE64_B: HE64.2 (VOUT), MUX1.30 (S22)
/sensors/HE65_N: HE65.2 (VOUT), MUX2.3 (S10)
/sensors/HE66_M: HE66.2 (VOUT), MUX2.2 (S11)
/sensors/HE67_Comma: HE67.2 (VOUT), MUX2.48 (S13)
/sensors/HE68_Period: HE68.2 (VOUT), MUX2.35 (S27)
/sensors/HE69_Slash: HE69.2 (VOUT), MUX3.45 (S16)
/sensors/HE70_ShiftR: HE70.2 (VOUT), MUX3.39 (S31)
/sensors/HE71_ArrowUp: HE71.2 (VOUT), MUX3.31 (S23)
/sensors/HE72_CtrlL: HE72.2 (VOUT), MUX1.45 (S16)
/sensors/HE73_Win: HE73.2 (VOUT), MUX1.37 (S29)
/sensors/HE74_AltL: HE74.2 (VOUT), MUX1.36 (S28)
/sensors/HE75_Space: HE75.2 (VOUT), MUX1.32 (S24)
/sensors/HE76_AltR: HE76.2 (VOUT), MUX2.1 (S12)
/sensors/HE77_Fn: HE77.2 (VOUT), MUX3.40 (S32)
/sensors/HE78_CtrlR: HE78.2 (VOUT), MUX3.38 (S30)
/sensors/HE79_ArrowLeft: HE79.2 (VOUT), MUX3.37 (S29)
/sensors/HE80_ArrowDown: HE80.2 (VOUT), MUX3.33 (S25)
/sensors/HE81_ArrowRight: HE81.2 (VOUT), MUX3.29 (S21)
GND: HE1.3 (GND), HE2.3 (GND), HE3.3 (GND), HE4.3 (GND), HE5.3 (GND), HE6.3 (GND), HE7.3 (GND), HE8.3 (GND), HE9.3 (GND), HE10.3 (GND), HE11.3 (GND), HE12.3 (GND), HE13.3 (GND), HE14.3 (GND), HE15.3 (GND), HE16.3 (GND), HE17.3 (GND), HE18.3 (GND), HE19.3 (GND), HE20.3 (GND), HE21.3 (GND), HE22.3 (GND), HE23.3 (GND), HE24.3 (GND), HE25.3 (GND), HE26.3 (GND), HE27.3 (GND), HE28.3 (GND), HE29.3 (GND), HE30.3 (GND), HE31.3 (GND), HE32.3 (GND), HE33.3 (GND), HE34.3 (GND), HE35.3 (GND), HE36.3 (GND), HE37.3 (GND), HE38.3 (GND), HE39.3 (GND), HE40.3 (GND), HE41.3 (GND), HE42.3 (GND), HE43.3 (GND), HE44.3 (GND), HE45.3 (GND), HE46.3 (GND), HE47.3 (GND), HE48.3 (GND), HE49.3 (GND), HE50.3 (GND), HE51.3 (GND), HE52.3 (GND), HE53.3 (GND), HE54.3 (GND), HE55.3 (GND), HE56.3 (GND), HE57.3 (GND), HE58.3 (GND), HE59.3 (GND), HE60.3 (GND), HE61.3 (GND), HE62.3 (GND), HE63.3 (GND), HE64.3 (GND), HE65.3 (GND), HE66.3 (GND), HE67.3 (GND), HE68.3 (GND), HE69.3 (GND), HE70.3 (GND), HE71.3 (GND), HE72.3 (GND), HE73.3 (GND), HE74.3 (GND), HE75.3 (GND), HE76.3 (GND), HE77.3 (GND), HE78.3 (GND), HE79.3 (GND), HE80.3 (GND), HE81.3 (GND), MC1.2, MC2.2, MC3.2, MUX1.22 (~EN), MUX1.23 (GND), MUX1.24 (VSS), MUX2.6 (S7), MUX2.22 (~EN), MUX2.23 (GND), MUX2.24 (VSS), MUX2.33 (S25), MUX2.37 (S29), MUX2.38 (S30), MUX2.39 (S31), MUX2.40 (S32), MUX2.45 (S16), MUX2.46 (S15), MUX3.2 (S11), MUX3.4 (S9), MUX3.6 (S7), MUX3.8 (S5), MUX3.22 (~EN), MUX3.23 (GND), MUX3.24 (VSS), MUX3.28 (S20), MUX3.30 (S22), MUX3.32 (S24); also elsewhere on the board
MUX1: MUX1.43 (D); also elsewhere on the board
MUX2: MUX2.43 (D); also elsewhere on the board
MUX3: MUX3.43 (D); also elsewhere on the board
MUX_A0: MUX1.15 (A0), MUX2.15 (A0), MUX3.15 (A0); also elsewhere on the board
MUX_A1: MUX1.16 (A1), MUX2.16 (A1), MUX3.16 (A1); also elsewhere on the board
MUX_A2: MUX1.17 (A2), MUX2.17 (A2), MUX3.17 (A2); also elsewhere on the board
MUX_A3: MUX1.18 (A3), MUX2.18 (A3), MUX3.18 (A3); also elsewhere on the board
MUX_A4: MUX1.19 (A4), MUX2.19 (A4), MUX3.19 (A4); also elsewhere on the board
MUX_CS1: MUX1.20 (~CS); also elsewhere on the board
MUX_CS2: MUX2.20 (~CS); also elsewhere on the board
MUX_CS3: MUX3.20 (~CS); also elsewhere on the board
MUX_WR: MUX1.21 (~WR), MUX2.21 (~WR), MUX3.21 (~WR); also elsewhere on the board

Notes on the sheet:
v2: replaced HC4067 with ADG732 muxes v2.1: updated +3.3V to +3V3
KNOB
ST7735 DISPLAY

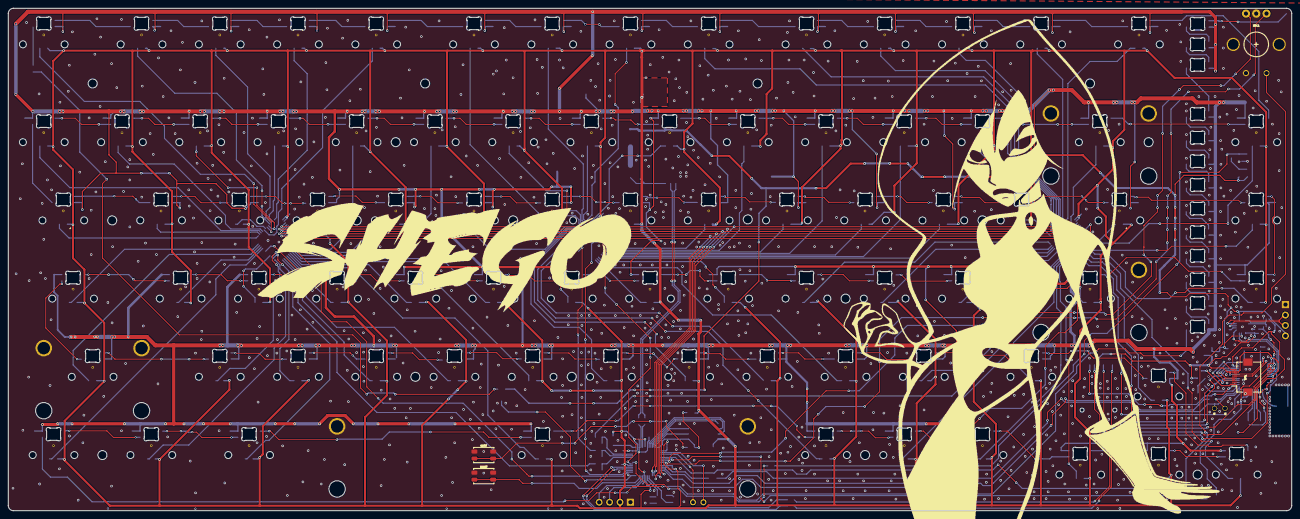
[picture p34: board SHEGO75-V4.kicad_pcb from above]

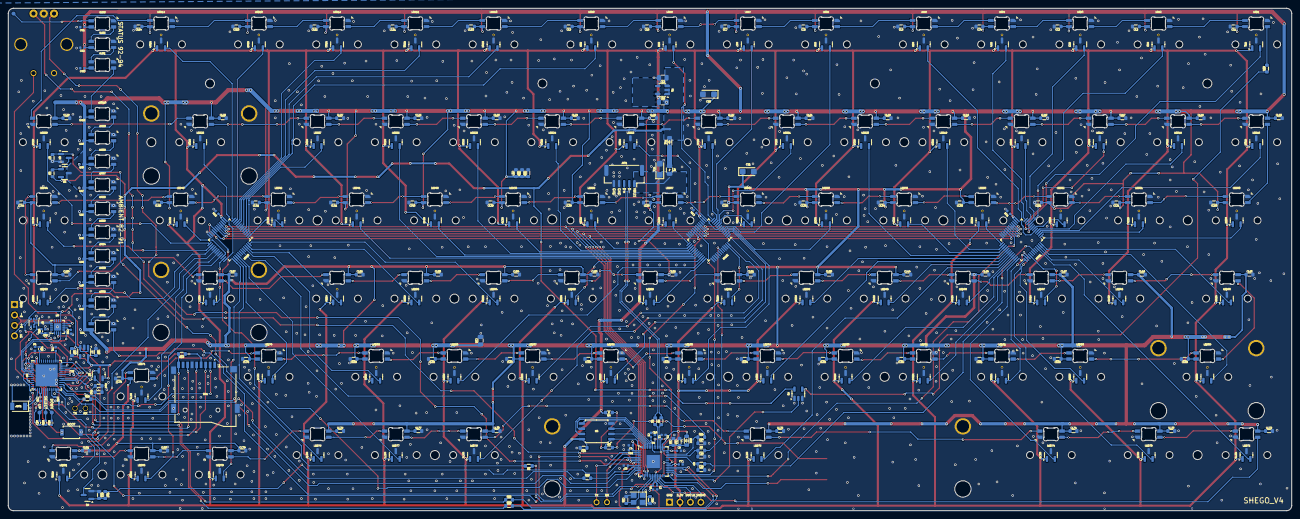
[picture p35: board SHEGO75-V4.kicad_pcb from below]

Board: 2 copper layers, 312.5 x 122.3 mm, 369 parts (362 on the bottom side), 265 nets.

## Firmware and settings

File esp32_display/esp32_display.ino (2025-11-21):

#include <SD.h>
#include <SPI.h>
#include <FS.h>
#include <SPIFFS.h>
#include <TFT_eSPI.h>
#include <AnimatedGIF.h>
#include <esp_task_wdt.h>
#include <WiFi.h>
#include "esp_bt.h"
#include "esp_bt_main.h"
#include "esp_wifi.h"
// FreeRTOS semaphore for SPI/TFT/SD mutual exclusion
#include <freertos/FreeRTOS.h>
#include <freertos/semphr.h>

#define SD_CS_PIN 26
#define SD_MOSI 22
#define SD_MISO 19
#define SD_SCK 21
#define BUTTON_UP 36      // Up/Previous button
#define BUTTON_DOWN 37    // Down/Next button  
#define BUTTON_SELECT 38  // Select button

// Backlight control (PWM via AO3401A transistor on GPIO25)
#define BACKLIGHT_PIN 25
#define BACKLIGHT_PWM_CHANNEL 0
#define BACKLIGHT_PWM_FREQ 5000
#define BACKLIGHT_PWM_RESOLUTION 8  // 0-255

// UART pins for QMK communication
#define QMK_RX_PIN 32     // ESP32 receives from RP2040
#define QMK_TX_PIN 33     // ESP32 sends to RP2040

// Create second serial port for QMK communication
HardwareSerial QMKSerial(2);

AnimatedGIF gif;
File gifFile;
TFT_eSPI tft = TFT_eSPI(); 
// Inclusive display end coordinates (used by GIFDraw.ino)
int displayXEnd;
int displayYEnd;
// Use a dedicated SPIClass instance for SD operations so we can control transactions
SPIClass sdSPI(VSPI);

// Mutex used to serialize access to SPI/TFT/SD to avoid concurrency races
SemaphoreHandle_t spiMutex = NULL;

// Array to store GIF filenames (for browsing only)
String gifFiles[100];
int gifCount = 0;
int currentGifIndex = 0;

// Button handling
bool buttonUpPressed = false;
bool buttonDownPressed = false;
bool buttonSelectPressed = false;
unsigned long lastButtonPress = 0;
unsigned long buttonSelectPressStart = 0;
bool buttonSelectHeld = false;

// Menu system
bool inMenu = false;
int menuSelection = 0;
unsigned long menuTimeout = 0;
#define MENU_TIMEOUT 5000  // 5 seconds
#define BUTTON_HOLD_TIME 500  // 500ms to trigger menu

// Settings menu system
enum MenuType { MENU_GIF, MENU_SETTINGS, MENU_TIMER, MENU_STOPWATCH };
MenuType currentMenuType = MENU_GIF;
int settingsSelection = 0;

// Settings toggles (persistent across menu opens)
bool setting_socd_enabled = false;
bool setting_raw_keycodes_enabled = false;
bool setting_keypress_detection_enabled = false;
bool setting_adc_printing_enabled = false;

// Timer state
int timerMinutes = 5; // default 5 minutes
bool timerRunning = false;
unsigned long timerEndTime = 0;
unsigned long timerStartTime = 0;

// Stopwatch state (for future implementation)
bool stopwatchRunning = false;
unsigned long stopwatchStartTime = 0;
unsigned long stopwatchElapsed = 0;

// Backlight brightness (0-3 index for 4 levels)
// Brightness levels: 0=25%, 1=50%, 2=75%, 3=100%
uint8_t backlightLevel = 3;  // start at 100% (level 3)
const uint8_t brightnessLevels[] = {64, 128, 192, 255};  // 4 brightness levels (25%, 50%, 75%, 100%)

// Maximum GIF size allowed (2 MB)
// Adjust this if your SPIFFS/partition scheme can't hold this size.
#define MAX_GIF_SIZE_BYTES (2UL * 1024UL * 1024UL)

// Current loaded GIF
String currentLoadedGif = "";
String currentGifPath = ""; // Path to current GIF (SD or SPIFFS)

// Debug popup state (multi-line, resizable centered overlay)
bool debugPopupActive = false;
unsigned long debugPopupUntil = 0;
String debugPopupTitle = "";   // e.g. "DEBUG:" or "SOCD"
String debugPopupLine1 = "";   // first body line
String debugPopupLine2 = "";   // second body line (optional)
unsigned long debugPopupDefaultMs = 1500; // default popup time
int debugPopupPaddingX = 22; // a few pixels wider
int debugPopupPaddingY = 12;
bool debugPopupHighlightKeycode = false;
uint16_t debugPopupLine1Color = TFT_WHITE;
// Request flag to safely activate a popup at a safe point in the GIF playback loop
bool debugPopupRequest = false;
// When true the next GIF frame will be drawn as a full opaque frame (transparent pixels replaced
// with the GIF background) so it completely overwrites any overlays. Cleared after one frame.
bool forceFullFrame = false;
// Per-line horizontal offsets (pixels). Can be negative or positive to shift text left/right.
int debugPopupOffsetTitleX = 0;
int debugPopupOffsetLine1X = 0;
int debugPopupOffsetLine2X = 0;
// Per-popup local offsets (set when creating a popup; if 0, globals are used)
int debugPopupLocalOffsetTitleX = 0;
int debugPopupLocalOffsetLine1X = 0;
int debugPopupLocalOffsetLine2X = 0;

// ═══════════════════════════════════════════════════════════════════════════════
// MANUAL TEXT OFFSET TABLE - Edit the X_OFFSET values below to position each text string
// ═══════════════════════════════════════════════════════════════════════════════
// HOW TO USE:
// 1. Find the exact text string you want to move (title, line1, or line2)
// 2. Set X_OFFSET: positive = shift RIGHT, negative = shift LEFT
// 3. All text is left-aligned by default at the left edge of the popup box
// 4. Compile and upload to see changes
// 
// Example entries (add your own below):
struct ManualOffset {
  const char* text;      // Exact text string to match
  int X_OFFSET;          // Pixels to shift: negative=left, positive=right
};

ManualOffset manualOffsets[] = {
  // Add your text strings and offsets here:
  // {"Keypress detection", 10},      
  {"Snappy Tappy", -13},                             
  {"SOCD: ON", -2},                 
  {"SOCD: OFF", -4},                 
  {"ADC printing", -13},              
  {"KEYCODE", 3},                     
  {"Raw Keycodes", -13},            
  {"Press Detect", -13},
  {"Disabled!", -2},                  

  
  // Your offsets below (copy exact text from Serial Monitor when popups appear):
  
};

int manualOffsetCount = sizeof(manualOffsets) / sizeof(manualOffsets[0]);

// Lookup X_OFFSET for a given text string
int getManualOffset(const String &text) {
  // Try exact match first
  for (int i = 0; i < manualOffsetCount; i++) {
    if (text.equals(manualOffsets[i].text)) {
      return manualOffsets[i].X_OFFSET;
    }
  }
  // Try case-insensitive trimmed match
  String lookupText = text;
  lookupText.trim();
  lookupText.toUpperCase();
  for (int i = 0; i < manualOffsetCount; i++) {
    String entryText = String(manualOffsets[i].text);
    entryText.trim();
    entryText.toUpperCase();
    if (lookupText.equals(entryText)) {
      return manualOffsets[i].X_OFFSET;
    }
  }
  
  // Special rule: any string starting with "0x" (hex keycodes) gets +8px offset
  if (text.startsWith("0x") || text.startsWith("0X")) {
    return 8;
  }
  
  return 0; // no offset found, use default (left edge)
}

// GIF loading state
bool pendingGifLoad = false;
int pendingGifIndex = -1;

// Track last serial-announced playing GIF to avoid spamming the serial port
String lastPlayedSerial = "";

// Function declarations
void handleButtons();
void handleQMKCommands();
void enterMenu();
void exitMenu();
void selectCurrentGif();
void drawMenu();
void enterSettingsMenu();
void drawSettingsMenu();
void handleSettingsSelection();
void enterTimerMenu();
void drawTimerMenu();
void handleTimerSelection();
void updateTimer();
void playCurrentGif();
void scanAllGifs();
void *fileOpen(const char *filename, int32_t *pFileSize);
void fileClose(void *pHandle);
int32_t fileRead(GIFFILE *pFile, uint8_t *pBuf, int32_t iLen);
int32_t fileSeek(GIFFILE *pFile, int32_t iPosition);
bool copyFile(const char *srcPath, const char *dstPath);
void setBacklightBrightness(uint8_t brightness);
void backlightUp();
void backlightDown();
void handleSerialCommands();
void processCommand(String command);

void setup()
{
  // ========== POWER OPTIMIZATION - DISABLE UNUSED RADIOS ==========
  // This MUST be done before Serial.begin() for maximum effect
  
  // Completely disable WiFi
  WiFi.mode(WIFI_OFF);
  esp_wifi_stop();
  esp_wifi_deinit();
  
  // Completely disable Bluetooth and release memory
  btStop();
  esp_bt_controller_disable();
  esp_bt_controller_deinit();
  esp_bt_mem_release(ESP_BT_MODE_BTDM);
  
  // Reduce CPU frequency for power savings
  // 160MHz is a good balance - try 80MHz if you want more savings
  // setCpuFrequencyMhz(160); // was 240
  
  // ========== END POWER OPTIMIZATION ==========
  
  Serial.begin(115200);
  delay(1000);

  Serial.println("Starting setup...");
  Serial.printf("CPU Frequency: %d MHz (power optimized)\n", getCpuFrequencyMhz());
  Serial.println("WiFi and Bluetooth disabled for low power operation");

  // Initialize buttons (GPIO36, 37, 38 with external pull-ups)
  pinMode(BUTTON_UP, INPUT);
  pinMode(BUTTON_DOWN, INPUT);
  pinMode(BUTTON_SELECT, INPUT);
  Serial.println("Buttons initialized on GPIO36(UP), GPIO37(DOWN), GPIO38(SELECT) with external pull-ups");

  // Initialize QMK Serial communication
  QMKSerial.begin(115200, SERIAL_8N1, QMK_RX_PIN, QMK_TX_PIN);
  Serial.println("QMK Serial initialized on pins 16(RX)/17(TX)");

  // Hardware reset for TFT (if RST pin is connected to GPIO 4)
  pinMode(4, OUTPUT);
  digitalWrite(4, LOW);
  delay(10);
  digitalWrite(4, HIGH);
  delay(10);

  tft.begin();
  Serial.println("Initializing TFT...");
  tft.writecommand(0x01); // Software reset
  delay(150);
  tft.writecommand(0x11); // Sleep out
  delay(120);
  tft.init();
  delay(100);
  
  // Initialize PWM backlight control (AO3401A transistor on GPIO25)
  // ESP32 Arduino 3.x uses ledcAttach instead of ledcSetup/ledcAttachPin
  ledcAttach(BACKLIGHT_PIN, BACKLIGHT_PWM_FREQ, BACKLIGHT_PWM_RESOLUTION);
  setBacklightBrightness(backlightLevel);  // Start at level 3 (100% brightness)
  Serial.println("Backlight initialized with 4 levels (25%, 50%, 75%, 100%)");
  
  tft.setRotation(3);
  tft.fillScreen(TFT_BLACK);
  // Set inclusive end coordinates for display (used by GIFDraw clipping)
  displayXEnd = tft.width() - 1;
  displayYEnd = tft.height() - 1;

  // Initialize SD card with custom SPI pins
  Serial.println("SD card initialization...");
  sdSPI.begin(SD_SCK, SD_MISO, SD_MOSI, SD_CS_PIN);
  bool sdInitialized = false;
  for (int attempts = 0; attempts < 3; attempts++) {
    if (SD.begin(SD_CS_PIN, sdSPI)) {
      sdInitialized = true;
      Serial.println("SD card initialized successfully!");
      break;
    }
    Serial.printf("SD initialization attempt %d failed, retrying...\n", attempts + 1);
    delay(1000);
  }
  if (!sdInitialized) {
    Serial.println("SD card initialization failed after 3 attempts!");
    tft.fillScreen(TFT_RED);
    tft.setCursor(10, 10);
    tft.print("SD CARD FAILED");
    return;
  }

  // Initialize SPIFFS
  Serial.println("Initialize SPIFFS...");
  if (!SPIFFS.begin(true)) {
    Serial.println("SPIFFS initialization failed!");
    tft.fillScreen(TFT_RED);
    tft.setCursor(10, 30);
    tft.print("SPIFFS FAILED");
    return;
  }
  Serial.println("SPIFFS initialized successfully.");
  
  // Display SPIFFS capacity info
  size_t totalBytes = SPIFFS.totalBytes();
  size_t usedBytes = SPIFFS.usedBytes();
  size_t freeBytes = totalBytes - usedBytes;
  Serial.printf("SPIFFS Total: %u bytes (%.2f MB)\n", totalBytes, totalBytes / 1048576.0);
  Serial.printf("SPIFFS Used: %u bytes (%.2f MB)\n", usedBytes, usedBytes / 1048576.0);
  Serial.printf("SPIFFS Free: %u bytes (%.2f MB)\n", freeBytes, freeBytes / 1048576.0);

  // Scan SD for GIF files (but don't auto-play)
  scanAllGifs();
  if (gifCount == 0) {
    Serial.println("No GIF files found on SD!");
    tft.fillScreen(TFT_RED);
    tft.setCursor(10, 50);
    tft.print("NO GIFS FOUND ON SD");
    delay(2000);
  }

  // Check for existing SPIFFS GIF (/current.gif or numbered)
  bool foundExistingGif = false;
  String existingSpiffsPath = "";
  if (SPIFFS.exists("/current.gif")) {
    existingSpiffsPath = "/current.gif";
    foundExistingGif = true;
    Serial.println("Found existing SPIFFS GIF: /current.gif");
  } else {
    for (int i = 0; i < gifCount && !foundExistingGif; i++) {
      String testPath = "/gif_" + String(i) + ".gif";
      if (SPIFFS.exists(testPath.c_str())) {
        existingSpiffsPath = testPath;
        foundExistingGif = true;
        Serial.printf("Found existing SPIFFS GIF: %s\n", testPath.c_str());
        break;
      }
    }
  }

  if (foundExistingGif) {
    File existingGif = SPIFFS.open(existingSpiffsPath.c_str(), FILE_READ);
    if (existingGif && existingGif.size() > 0) {
      Serial.printf("Using existing SPIFFS GIF (%d bytes) at %s\n", existingGif.size(), existingSpiffsPath.c_str());
      size_t existingSize = existingGif.size();
      existingGif.close();
      // try to match by size
      currentGifIndex = 0;
      for (int i = 0; i < gifCount; i++) {
        String sdPath = "/" + gifFiles[i];
        File sdGif = SD.open(sdPath.c_str());
        if (sdGif && sdGif.size() == existingSize) {
          currentGifIndex = i;
          currentLoadedGif = gifFiles[i];
          currentGifPath = existingSpiffsPath;
          Serial.printf("Matched existing SPIFFS GIF to index %d: %s\n", i, gifFiles[i].c_str());
          sdGif.close();
          break;
        }
        if (sdGif) sdGif.close();
      }
    } else {
      Serial.printf("Existing SPIFFS GIF corrupted at %s, opening menu\n", existingSpiffsPath.c_str());
      existingGif.close();
      currentGifIndex = 0;
      currentLoadedGif = "";
      currentGifPath = "";
      // Set flag to enter menu after setup
      inMenu = true;
      menuSelection = 0;
      menuTimeout = millis() + 60000; // Longer timeout on startup
    }
  } else {
    Serial.println("No existing SPIFFS GIF found, opening menu for selection...");
    currentGifIndex = 0;
    // Important: Don't ever want to play from SD
    // Only set placeholders until user makes a selection
    currentLoadedGif = "";
    currentGifPath = "";
    
    // Set flag to enter menu after setup
    inMenu = true;
    menuSelection = 0;
    menuTimeout = millis() + 60000; // Longer timeout (60 seconds) on initial startup
  }

  // Initialize the GIF
  Serial.println("Starting animation...");
  gif.begin(BIG_ENDIAN_PIXELS);

  // Create mutex for SPI/TFT/SD serialization
  spiMutex = xSemaphoreCreateMutex();
  if (!spiMutex) {
    Serial.println("Failed to create SPI mutex!");
  }

  // Initialize I2C GIF receiver (SDA=GPIO13, SCL=GPIO14)
  // Use renamed init function to avoid conflict with esp32-hal i2cInit()
  i2cInitSlave();

  tft.fillScreen(TFT_BLACK);
  
  // If we're starting in menu mode, draw the menu right away
  if (inMenu) {
    drawMenu();
  }
}

void loop()
{
  handleButtons();
  handleQMKCommands();
  handleSerialCommands();  // Handle commands from Serial Monitor
  i2cProcess();  // Process I2C GIF transfers (renamed)
  
  // Update timer if running
  if (timerRunning) {
    updateTimer();
  }
  
  if (inMenu) {
    // Menu mode - handle timeout (except for timer/stopwatch menus)
    if (currentMenuType == MENU_GIF || currentMenuType == MENU_SETTINGS) {
      if (millis() - menuTimeout > MENU_TIMEOUT) {
        // Only exit menu if there's a valid GIF to play
        if (currentGifPath != "" && SPIFFS.exists(currentGifPath.c_str())) {
          exitMenu();
        } else {
          // No valid GIF - reset timeout to keep menu open
          menuTimeout = millis();
        }
      }
    }
  } else {
    // GIF playback mode - no more pending loads, direct SD card playback
    playCurrentGif();
  }
}
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

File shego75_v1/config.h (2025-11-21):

/* config.h - keyboard configuration for shego75_v1 */
#pragma once

// Enable vendor bulk endpoints for host app detection
// (Actual vendor communication not yet implemented - falls back to raw HID)
#define VENDOR_ENABLE

// ============================================================================
// AUTO-CALIBRATION CONFIGURATION
// ============================================================================
// The keyboard automatically calibrates sensor thresholds on startup.
// Each key's baseline (resting) value is measured, and actuation occurs when
// the ADC drops below CALIBRATION_THRESHOLD_PERCENT of that baseline.
//
// IMPORTANT: Ensure NO KEYS ARE PRESSED during power-on!
//
// Adjusting sensitivity:
// - Lower percentage (e.g., 80) = MORE sensitive (earlier actuation, lighter touch)
// - Higher percentage (e.g., 90) = LESS sensitive (deeper press required)
//
// Uncomment and adjust the value below to customize:
// #define CALIBRATION_THRESHOLD_PERCENT 85
//
// Default is 85% (15% drop from baseline triggers actuation)
// ============================================================================

// ============================================================================
// RGB MATRIX CONFIGURATION
// ============================================================================
// Cap brightness at 70% (178/255) to reduce heat and power consumption
#define RGB_MATRIX_MAXIMUM_BRIGHTNESS 178

// ============================================================================
// I2C CONFIGURATION (for ESP32 communication)
// ============================================================================
// RGB is on GP17, so GP20/GP21 are available for I2C
#define I2C_DRIVER I2CD1
#define I2C1_SDA_PIN GP20
#define I2C1_SCL_PIN GP21

// ============================================================================
// RAW HID CONFIGURATION (for Electron app communication)
// ============================================================================
// Define custom usage page to preserve report IDs on Windows
// This prevents Windows HID from stripping the report ID byte
#define RAW_USAGE_PAGE 0xFF60  // Custom vendor-defined usage page
#define RAW_USAGE_ID   0x61    // Custom usage ID

#define VENDOR_ENABLE

// LED rail control polarity. Set to 1 if driving the pin HIGH turns LEDs ON,
// or 0 if the hardware expects LOW for ON (for example, a direct P-channel gate).
#ifndef LED_TOG_ACTIVE_HIGH
#    define LED_TOG_ACTIVE_HIGH 1
#endif

// Define the LED toggle pin (GP23) so uart_keycodes.c can drive it
#ifndef LED_TOG_PIN
#   define LED_TOG_PIN GP23
#endif

// UART configuration - Dual UART setup
// UART0 (GP0/GP1): Debug output
// UART1 (GP8/GP9): ESP32 communication
// Note: Pin configuration is handled in uart.c

// Encoder switch (optional - not part of standard encoder config)
#ifndef ENCODER_SW_PIN
#define ENCODER_SW_PIN GP4
#define ENCODER_A_PIN GP5
#define ENCODER_B_PIN GP6
#endif
// #define ENCODER_DIRECTION_FLIP

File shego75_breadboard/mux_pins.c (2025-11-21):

#include "mux_pins.h"
#include "quantum.h"

// MASTER SENSOR-TO-KEYCODE LOOKUP TABLE
// This maps sensor numbers 1-48 directly to QMK keycodes based on your 4x12 layout
// Sensor numbers are calculated as: (matrix_row * 12) + matrix_col + 1
// Your keymap layout:
//   Row 0: ESC  Q    W    E    R    T    Y    U    I    O    P    BSPC
//   Row 1: TAB  A    S    D    F    G    H    J    K    L    SCLN ENT
//   Row 2: LSFT Z    X    C    V    B    N    M    COMM DOT  SLSH RSFT
//   Row 3: LCTL LGUI LALT MO1  SPC  SPC  SPC  MO2  RALT RGUI APP  RCTL

const uint16_t sensor_to_keycode[KEY_COUNT] = {
    // Sensors 1-12 (Row 0): ESC through BSPC
    KC_ESC,  KC_Q,    KC_W,    KC_E,    KC_R,    KC_T,    KC_Y,    KC_U,    KC_I,    KC_O,    KC_P,    KC_BSPC,
    // Sensors 13-24 (Row 1): TAB through ENT
    KC_TAB,  KC_A,    KC_S,    KC_D,    KC_F,    KC_G,    KC_H,    KC_J,    KC_K,    KC_L,    KC_SCLN, KC_ENT,
    // Sensors 25-36 (Row 2): LSFT through RSFT
    KC_LSFT, KC_Z,    KC_X,    KC_C,    KC_V,    KC_B,    KC_N,    KC_M,    KC_COMM, KC_DOT,  KC_SLSH, KC_RSFT,
    // Sensors 37-48 (Row 3): LCTL through RCTL  (use 0x5D00 for MO(1), 0x5D01 for MO(2))
    KC_LCTL, KC_LGUI, KC_LALT, 0x5D00,  KC_SPC,  KC_SPC,  KC_SPC,  0x5D01,  KC_RALT, KC_RGUI, KC_APP,  KC_RCTL
};

// Sensor names array (for debug printing)
const char *sensor_names[KEY_COUNT] = {
    "Esc", "Q", "W", "E", "R", "T", "Y", "U", "I", "O", "P", "Bspc",
    "Tab", "A", "S", "D", "F", "G", "H", "J", "K", "L", "Scln", "Ent",
    "LShft", "Z", "X", "C", "V", "B", "N", "M", "Comm", "Dot", "Slsh", "RShft",
    "LCtrl", "LGui", "LAlt", "MO1", "Spc", "Spc", "Spc", "MO2", "RAlt", "RGui", "App", "RCtrl"
};

// MUX1 channel mappings (channels 0-15)
// Each MUX channel is wired to a specific sensor number.
// The sensor number automatically maps to matrix position via: (sensor-1)/12, (sensor-1)%12
// Update these sensor numbers to match your actual MUX1 wiring.
const mux16_ref_t mux1_channels[16] = {
    [0]  = { K_E       },  // CH0    /* HE4 */
    [1]  = { K_D       },  // CH1    /* HE16 */
    [2]  = { K_C       },  // CH2    /* HE28 */
    [3]  = { K_MO1     },  // CH3    /* HE40 */
    [4]  = { K_W       },  // CH4    /* HE3 */
    [5]  = { K_S       },  // CH5    /* HE15 */
    [6]  = { K_X       },  // CH6    /* HE27 */
    [7]  = { K_LALT    },  // CH7    /* HE39 */
    [8]  = { K_Q       },  // CH8    /* HE2 */
    [9]  = { K_A       },  // CH9    /* HE14 */
    [10] = { K_Z       },  // CH10   /* HE26 */
    [11] = { K_WIN     },  // CH11   /* HE38 */
    [12] = { K_ESC     },  // CH12   /* HE1 */
    [13] = { K_TAB     },  // CH13   /* HE13 */
    [14] = { K_LSFT    },  // CH14   /* HE25 */
    [15] = { K_LCTL    },  // CH15   /* HE37 */
};

// MUX2 channel mappings (channels 0-15)
// Same wiring as MUX1, but add 4 to each sensor number
const mux16_ref_t mux2_channels[16] = {
    [0]  = { K_U       },  // CH0   /* HE8 */
    [1]  = { K_J       },  // CH1   /* HE20 */
    [2]  = { K_M       },  // CH2   /* HE32 */
    [3]  = { K_FN      },  // CH3   /* HE41 */
    [4]  = { K_Y       },  // CH4   /* HE7 */
    [5]  = { K_H       },  // CH5   /* HE19 */
    [6]  = { K_N       },  // CH6   /* HE31 */
    [7]  = { K_SPC2    },  // CH7   /* HE42 */
    [8]  = { K_T       },  // CH8   /* HE6 */
    [9]  = { K_G       },  // CH9   /* HE18 */
    [10] = { K_B       },  // CH10  /* HE30 */
    [11] = { K_SPC1    },  // CH11  /* HE43 */
    [12] = { K_R       },  // CH12  /* HE5 */
    [13] = { K_F       },  // CH13  /* HE17 */
    [14] = { K_V       },  // CH14  /* HE29 */
    [15] = { K_TG3     },  // CH15  /* HE43 */
};

// MUX3 channel mappings (channels 0-15)
// Same wiring as MUX1, but add 8 to each sensor number
const mux16_ref_t mux3_channels[16] = {
    [0]  = { K_BSPC    },  // CH0   /* HE12 */
    [1]  = { K_ENT     },  // CH1   /* HE24 */
    [2]  = { K_RSFT    },  // CH2   /* HE36 */
    [3]  = { K_RGHT    },  // CH3   /* HE48 */
    [4]  = { K_P       },  // CH4   /* HE11 */
    [5]  = { K_SCLN    },  // CH5   /* HE23 */
    [6]  = { K_UP      },  // CH6   /* HE48 */
    [7]  = { K_DOWN    },  // CH7   /* HE44 */
    [8]  = { K_O       },  // CH8   /* HE10 */
    [9]  = { K_L       },  // CH9   /* HE22 */
    [10] = { K_DOT     },  // CH10  /* HE34 */
    [11] = { K_LEFT    },  // CH11  /* HE45 */
    [12] = { K_I       },  // CH12  /* HE9 */
    [13] = { K_K       },  // CH13  /* HE21 */
    [14] = { K_COMM    },  // CH14  /* HE33 */
    [15] = { K_RALT    },  // CH15  /* HE45 */
};

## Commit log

2025-11-21 Initial public release (squash merge from dev)
    [SHEGO75 - CASE_LOWER-V1.step, SHEGO75 - CASE_UPPER-V1.step, SHEGO75 - Drawing 1.dwg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]
2025-12-24 Merry Christmas! Updated README and CHANGELOG.
    [SHEGO75 - ScreenHolder 0.025.step, SHEGO75 - ScreenHolder 0.1.step]
2026-01-21 ✅✅✅ UPDATE: Add CHANGELOG and UPDATE documentation
    - Added CHANGELOG.md tracking version history and feature releases
    - Added UPDATE.md with detailed development story for Nocturne 75
    - Documents transition from RP2040+ESP32 to unified RP2350B architecture
    - Covers new slot-based GIF system, LVGL screen integration and other features
    [SHEGO75-V4.kicad_pcb, SHEGO75-V4.kicad_sch, SHEGO75-V5.kicad_pcb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]
